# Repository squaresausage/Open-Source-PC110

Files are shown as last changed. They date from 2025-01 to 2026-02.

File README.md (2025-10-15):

# IBM Palm Top PC110

Screenshot 2025-04-17 at 7 04 40 PM

A repository for all the technical details of the PC110

What it includes:

Schematic and PCB layout of the motherboard (based on KiCad)

Schematic and PCB layout of the PSU module (based on KiCad)

Schematic and PCB layout of the Docking Station (based on KiCad)

Schematic and PCB layout of the Modem (based on KiCad)

Schematic and PCB layout of the 16MB RAM Module (based on KiCad)

Flex PCB and PET Schematic and layout of the Keyboard Membrane (based on KiCad)

Optical scans, X-ray images from different PCBs, layers, and chips.

Flash dump of the BIOS and the AT29LV512 (available in only a few models).

Flash dump of M38224M6HP and M38813E4HP.

# How can you help?

Help by reviewing Schematics and PCB layouts to report potential bugs, errors, and issues.

Help to verify the layout and schematic.

Help with finding missing datasheets

Please help us [fund](https://gofund.me/716b7dae) the next iteration of PCBA to test the recreated motherboard.

# Press

Featured on Hack-A-Day: 
- [Reverse Engineering The IBM PC110, One PCB At A Time](https://hackaday.com/2025/04/06/reverse-engineering-the-ibm-pc110-one-pcb-at-a-time/) 

Featured on Taka's blog:
- [PC110 New PSU](https://garakutaen.sakura.ne.jp/misc2/MlogmP3.html#e0318)
- [PC110 PCB Pattern](https://garakutaen.sakura.ne.jp/misc2/MlogmP1.html#e0130)
- [PC110 PCB Layout creation](https://garakutaen.sakura.ne.jp/misc2/MlogmP2.html#e0208)
- [PC110 New Docking Station PCB](https://garakutaen.sakura.ne.jp/misc2/MlogmP3.html#e0324)
- [X-ray photos of the inside of the PC110's LSI](https://garakutaen.sakura.ne.jp/misc2/MlogmP2.html#e0225)

Jeff Geerling's YouTube Channel:
- [Reverse engineering Episode](https://youtu.be/p7IvioiveOo?si=PUlHSzOhwXYEpZJ3&t=217)

LGR YouTube Channel:
- [LGR Vlog: VCFMW20](https://www.youtube.com/watch?v=yIwXQicYClw&t=7595s)

VCFMW20 YouTube Channel:
- [Archaeology of the IBM PC110](https://www.youtube.com/watch?v=8Uja7g9hQlo)

# License

This project is licensed under the Creative Commons Attribution-NonCommercial 4.0 International License (CC BY-NC 4.0).

You are free to:
- Share — copy and redistribute the material in any medium or format
- Adapt — remix, transform, and build upon the material

Under the following terms:
- Attribution — You must give appropriate credit, provide a link to the license, and indicate if changes were made.
- NonCommercial — You may not use the material for commercial purposes.

For full details, see: https://creativecommons.org/licenses/by-nc/4.0/

As the project creator, I reserve the right to use this material commercially or under any other terms.

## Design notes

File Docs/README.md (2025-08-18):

# A Tribute to the IBM PC110

## A Deep Dive into Silicon, Sandpaper, and Secrets of the IBM PC110

**Reverse engineering the beloved IBM PC110, a 486SX-based subnotebook from the 90s, released exclusively in Japan with custom repackaged BGA chips, custom ASICs, and an attractive form factor.**

---

## Introduction: A Palm-Sized Powerhouse

The **IBM PC110**, released exclusively in **Japan in 1995**, was one of the smallest fully functional x86 systems ever made by IBM. This palmtop computer crammed a 486SX CPU, a CHIPS 65535 VGA chip, two PCMCIA slots, a CF card, and more great features into something that fits on top of your palm.

Despite rumors of an **English-language or U.S. release**, no such version ever reached the market. The project was reportedly in development but was quietly shelved, making the IBM PC110 unique and **regionally rare and historically mysterious**.

What fascinated me wasn’t just the size—it was the story under the keyboard: repackaged BGA packages and chips with no public documentation, the usage of camcorder batteries instead of a proprietary battery, and a CF card slot which made the machine sort of future proof and relevant to be "practical", even today. 

Unfortunately, most of the IBM PC110s ended up breaking down over time due to the leak of the bridge battery, causing corrosion and destroying the circuit board. It was heartbreaking to see those laptops end up in the landfill helplessly.  

So I decided to **reverse engineer the entire machine**. That journey involved **sandpaper**, **ROM dumps**, **laser decapping**, **high-resolution die photos**, and the help of some brilliant hardware and software hackers. What I found includes rare chipsets, custom logic arrays, and design decisions that were both *visionary* and *tragically destructive*.

---

## A Design Ahead of Its Time and One Fatal Flaw

The PC110 had forward-thinking design features, including:

- A **standard camcorder battery** (still sold on Amazon today)
- A **CompactFlash card slot**, used as its primary storage drive

These were remarkable decisions in 1995, long before CF replaced spinning disks in industrial systems.

But the system had a fatal flaw:  
A small **NiMH-based bridge battery**, placed internally, which was designed to maintain power between main battery swaps.
This was mainly because the internal PSU was unable to charge the battery while the machine was operating (things we take for granted with today's laptops). Therefore, the bridge battery was placed there to keep the machine running for about 2 minutes while you perform a battery swap.

Over time, that battery becomes a **ticking time bomb**.  
As it fails, it **leaks potassium hydroxide (KOH)**, a highly corrosive chemical that **destroys PCB traces**, **eats through components**, and **wrecks solder joints**.  
It’s the leading cause of death for otherwise restorable PC110 units today.

---

## Sanding a 10-Layer PCB — With a Flatbed Scanner

To begin understanding the system, I took the hard and destructive, yet necessary route:  
I **sanded the motherboard** down layer by layer.

The board is just **1.0mm thick**, with **10 copper layers**, each ~**70 microns**. I used **ultra-fine grit sandpaper** to remove layers delicately, scanning the exposed surface after each pass with a **high-resolution flatbed scanner**.

It was slow, imperfect, and occasionally damaging—but it worked. By the end, I had a full stack of perfectly aligned copper layers. Because I made several mistakes during the sanding and went too far, especially as I progressed through the layers, I had to sacrifice a second PCB, this time by sanding it from the other side.

---

## Reconstructing the Board in KiCad

With the scanned layers imported into **KiCad**, I aligned them and manually traced:

- Every net  
- Every via (through and blind)  
- Every component pad  
- Every trace/track  
- Every power polygon  
- Many more details  

Bit by bit, the **entire circuit** came together. I gave up many times in the middle due to some complexity or unresolved issues, but each time, I returned and continued. Some traces were incomplete or degraded, but logic and redundancy allowed me to **reconstruct the full schematic** of the system. Some tracks even appeared to go nowhere—perhaps used for debugging or cut later by the manufacturer. Who knows what software IBM used in the mid-90s; certainly not KiCad.

---

## Schematic Extraction and Deep System Insight

After the layout was reconstructed and the parts were identified, I began to **extract the schematic**, piece by piece.  
I organized different **subsystems** into separate schematic sheets, including:

- Clock Tree  
- CPU and debug port  
- Chipset and RTC  
- VGA controller  
- RAM interface  
- ROM and BIOS  
- ASICs  
- Super IO (FDD, Serial, LPT)  
- Power and charging logic  
- PCMCIA controller  
- Audio and FM Synthesizer  
- Storage and CF slot  
- Keyboard/PS2  
- IRDA and Docking station connector  

This gave me exceptional insight into **how IBM and RIOS Systems engineered this device**. After extracting the full schematic, I linked it back to the layout to identify and resolve discrepancies.  

The result is a schematic that **perfectly reflects the physical PCB** — signal-for-signal.

---

## Why This Schematic Unlocks the Future

With a fully accurate schematic and layout, this project now enables:

- **Redesigning the motherboard** with modern components  
- **Changing the form factor** entirely (e.g., vertical/landscape designs)  
- **Creating a Raspberry Pi-based recreation**  
- **Hardware diagnostics and repair**  
- **Upgrades and mods**, including custom RAM cards, new docks, and embedded devices

---

## The Known and Unknown Silicon

Identified components:

- **Intel 80486SX** CPU  
- **CHIPS65535** VGA controller  
- **Ricoh RB5C396** PCMCIA bridge  
- **FDC37C665IR** for FDD, Serial, LPT  
- **SC414281PU4** Storage Controller  
- Various logic ICs

Mysterious components:

- **VL82C420** – part of the SCAMP IV chipset, no datasheet available  
- **ES488** – no datasheet found; To recover the pinout, we purchased an old ISA sound card based on the ES488 and carefully traced all the connections from the ISA bus to the chip. This revealed almost the entire pinout and, in turn, helped us determine the ISA bus pinout of the PC110 motherboard.
- **IBM “Pluto” and “Bowman” ASICs**

The VL82C420 integrates 6 known chips (VL82C59s, VL82C37s, VL82C54, VL82C018) and a custom gate array.

---

## Decapping Chips with CLC and John McMaster

With Fred Nielsen from **CLC**, we decapped the VL82C420, Pluto, and Bowman using a laser-driven photo-chemical process.  
**John McMaster** provided high-resolution die imaging.

### Inside the VL82C420

- 2× VL82C59 (Interrupt Controller)  
- 2× VL82C37 (DMA Controller)  
- 1× VL82C54 (Timer)  
- 1× VL82C018 (RTC)  
- Integrated gate array  
- BGA packaging custom-made by RIOS

### Pluto and Bowman

IBM-designed gate arrays responsible for:

- Power sequencing  
- Interrupt control  
- ISA and docking logic  
- System glue logic

---

## PSU, Modem, and Docking Station Reverse Engineering

Reverse-engineering the PSU, modem, and docking station enabled:

- Full **pinout mapping**  
- Verification of unknown connector functions  
- Potential for **custom modern docks**

---

## Embedded Microcontrollers and ROM Extraction

| Chip | Function |
|---|---|
| **M38223** | Power sequencing |
| **M3881** | Keyboard & PS/2 |
| **D17137AGT**  | TrackPoint controller |

ROMs for M38223 and M3881 were extracted (thanks to **Kevin Moonlight**).  
**D17137AGT** was imaged optically but not visually decoded.

---

## Everything is Open-Source

GitHub Repo: [https://github.com/ahmadexp/Open-Source-PC110](https://github.com/ahmadexp/Open-Source-PC110)

### Contents

- `/scans/` — 10-layer PCB scans  
- `/kicad/` — Full KiCad schematic/layout  
- `/rom_dumps/` — ROM binaries  
- `/die_images/` — Die photographs  
- `/pinouts/` — Pin mappings  
- `/notes/` — Research notes

---

## What You Can Do

- Rebuild or modify the hardware  
- Use for emulation or form factor experiments  
- Study VL82C420 and ES488  
- Build docks, RAM, and CF replacements  
- Contribute firmware or ROM analysis

---

## Thanks and Acknowledgements

This project would not have been possible without:

- **Kevin Moonlight** — for microcontroller ROM extraction  
- **Mike Lycett** — for organizing the fundraiser, coordinating the effort, and promoting the project  
- **Nick Rogers** — for debugging and verification  
- **John McMaster** — for high-resolution die imaging and technical consultation  
- **CLC** — for decapping services and silicon prep  
- The **open hardware & retrocomputing community** — for encouragement, contributions, and documentation support

---

## Featured on Hackaday

Read the article: [https://hackaday.com/2025/04/06/reverse-engineering-the-ibm-pc110-one-pcb-at-a-time/](https://hackaday.com/2025/04/06/reverse-engineering-the-ibm-pc110-one-pcb-at-a-time/)

> “The kind of project that goes beyond repair — it preserves design history, reveals hidden hardware, and makes future restoration possible.”

---

## Stay Updated

- GitHub: [ahmadexp/Open-Source-PC110](https://github.com/ahmadexp/Open-Source-PC110)  
- Contact: Ahmad Byagowi / [@ahmadexp](https://github.com/ahmadexp)  
- YouTube video coming soon!

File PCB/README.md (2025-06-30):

## PC110 Recreated PCBs

Here you can find the recreated [Schematics](https://github.com/ahmadexp/Open-Source-PC110/blob/main/PCB/PC110-Schematics-Combined.pdf) and PCB layouts for different parts of the PC110 based on KiCad 9.0 (with the [AKL](https://alternatekicadlibrary.com/) as a requirement).
Here is a description of each folder:

| Index | Folder | Description | Number of Layers |
| ----- | --- | --- | --- |
| 1 | Mainboard | Mother Board | 10 |
| 2 | PSU | Power Supply | 4 |
| 3 | Keyboard | Keyboard Membrane  | 2 + 2 |
| 4 | DockingStation | Port Expansion | 4 |
| 5 | Modem | 14.4 Interal Modem | 6 |
| 6 | RAM-16MB | 16MB RAM Module | 4 |

Here are some 3D renders of the PCBs

### Mother Board:

- Schematic

Screenshot 2025-06-19 at 7 54 10 AM

- Layout

motherboard

### Power Supply:

- Schematic
Screenshot 2025-06-19 at 7 47 46 AM

- Layout
Screenshot 2025-04-04 at 7 01 09 PM

### Keyboard Membrane:

- Schematic
Screenshot 2025-06-19 at 7 48 27 AM

- Layout
Screenshot 2025-03-26 at 6 59 02 PM

### Port Expansion (Docking Station):

- Schematic
Screenshot 2025-06-19 at 7 48 05 AM

- Layout
dock

### 14.4 Kbps Internal Modem:

- Schematic
Screenshot 2025-06-19 at 7 48 13 AM

- Layout
modem

### 16MB RAM Module:

- Schematic
Screenshot 2025-06-19 at 7 48 20 AM

- Layout
Screenshot 2025-03-26 at 7 45 36 PM

Screenshot 2025-03-26 at 7 45 54 PM

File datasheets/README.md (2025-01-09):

## collection of datasheets related to the chips on the board

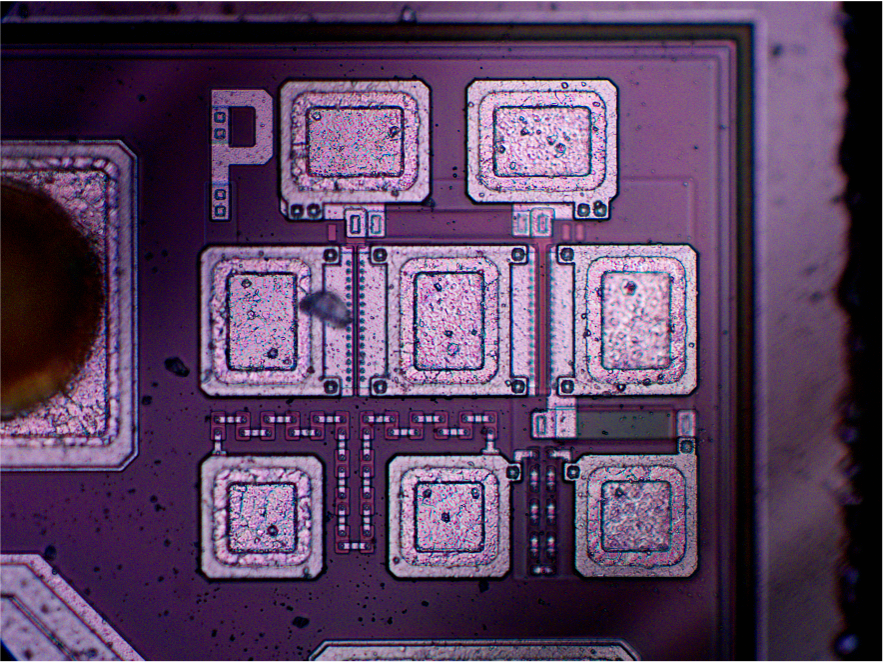
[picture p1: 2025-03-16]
optical/Pluto/Picture9.png

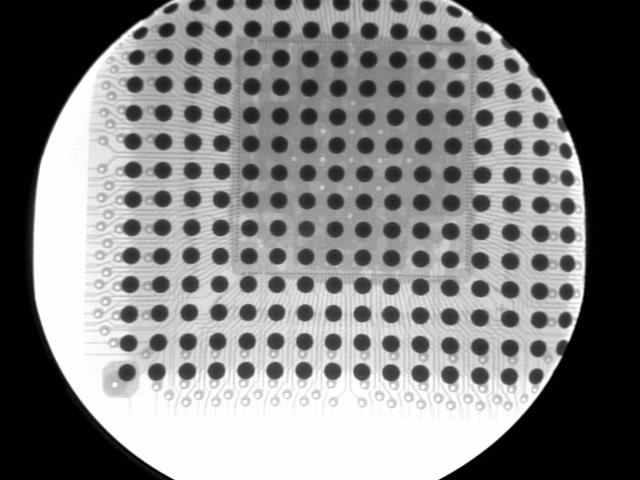
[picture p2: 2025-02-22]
optical/Chip Diagnostic/VL82C420 BL.JPG

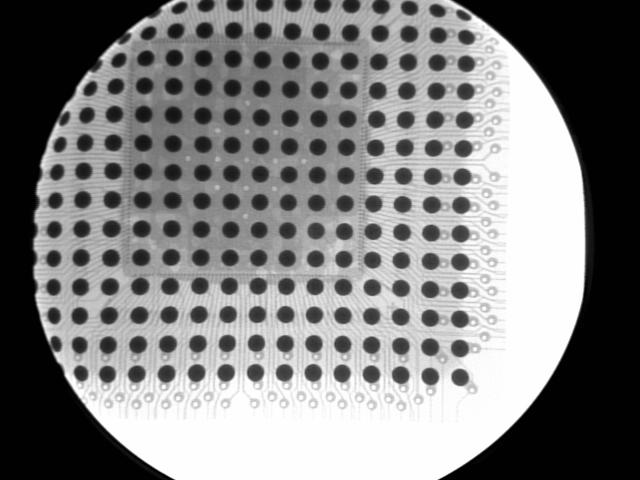
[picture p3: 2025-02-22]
optical/Chip Diagnostic/VL82C420 BR.JPG

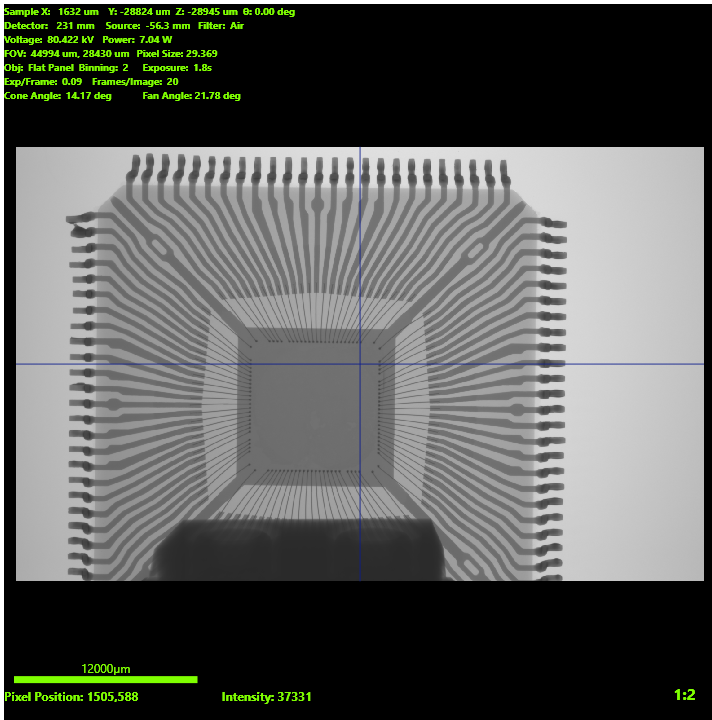
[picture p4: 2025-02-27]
optical/x-ray/pluto.png

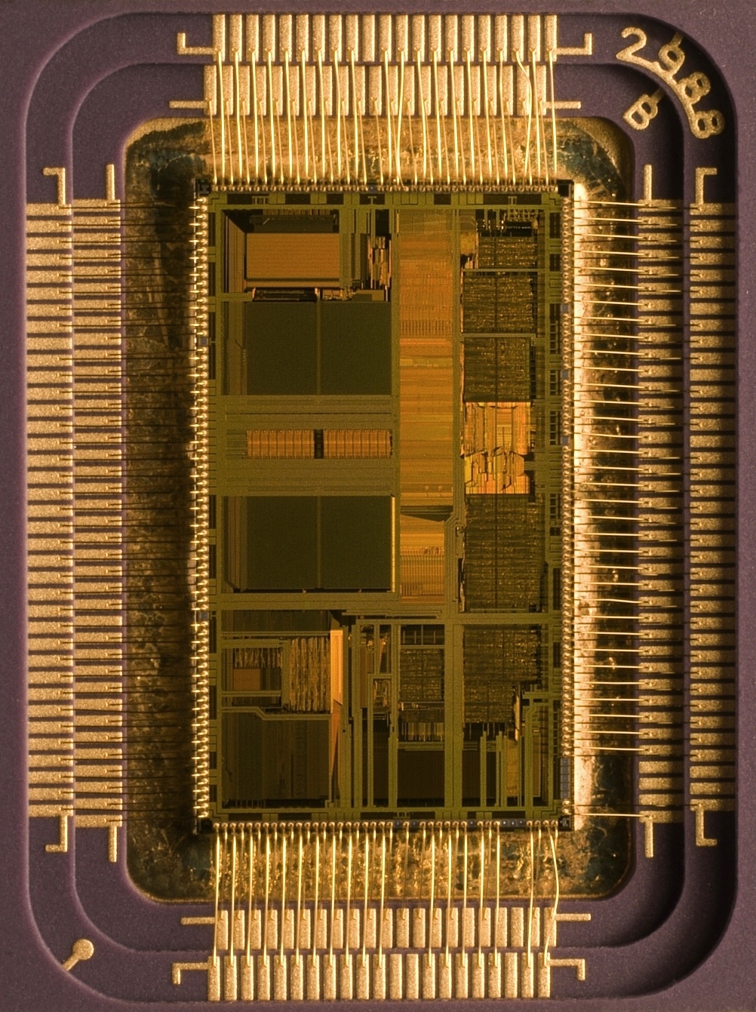
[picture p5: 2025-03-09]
optical/Chip Diagnostic/80486dx2-large.jpg

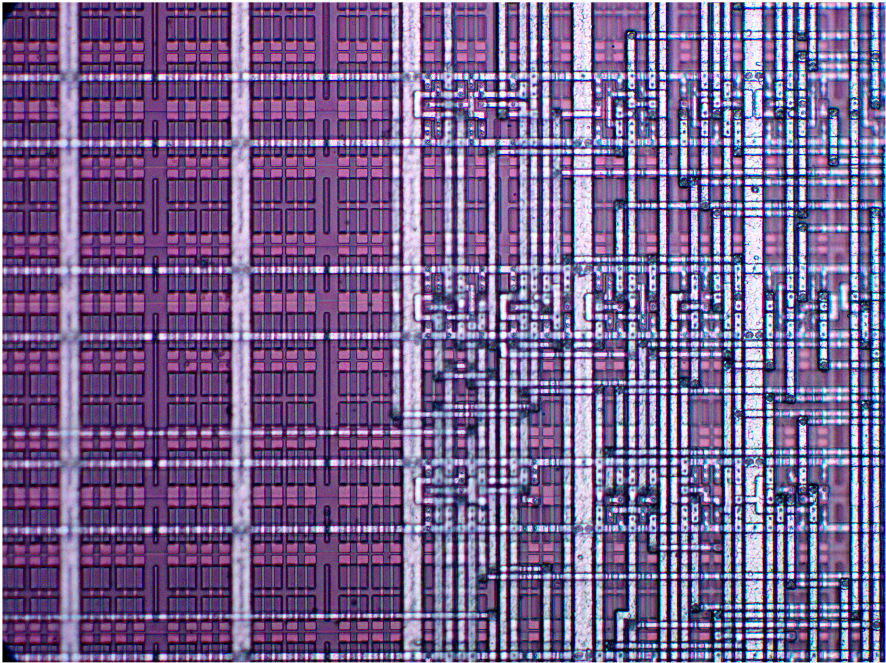
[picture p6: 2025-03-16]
optical/Pluto/Picture11.png

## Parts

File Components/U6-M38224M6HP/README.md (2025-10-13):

## Datasheets ##
[M38224M6HP](M3822.pdf)

[PCA4738H0-80A](PCA4738H.pdf)

## Part Number Details ##
```
M38223E4HP
|||||||||
|||||||++--> 80P6Q-A
||||||+----> 16384 Byte ROM Size 
|||||+-----> EPROM / OTP Version
||||+------> 512 Bytes RAM
++++-------> Mitsubishi 3822 Group MCU
```
There are at least two variations of the PC110.    In a small number of systems U6 is M38223E4HP OTP/EPROM version of the chip,  in the rest it is the M38223M4-192HP MASKROM version.  It is unclear if these represent early production models or perhaps supply chain related.    This is a helpful detail as it is unclear if a MASKROM variant can have its program read out without an optical approach.

Some boards also have non-programmed Sandisk controllers in U41 and contain a flash chip U27 for the program/config, where as the rest omit the external flashrom and have a maskrom U41.

I have observed boards where U6 is EPROM but U41 is MASKROM.  I have not yet seen one where U6 is MASKROM and U41 is not.  

## Location ##







## ROM Extraction ##

[M38223E4HP@QFP80.BIN](/Flash/M38223E4HP/M38223E4HP@QFP80.BIN) - **M3822X POWER SENSE MICON FIRMWARE Rev 8 (C) 1995 RIOS SYSTEMS CO.,LTD**

So far it seems to not be possible to  read the program from the MASKROM version of the chip,  which likely is to be expected.

There was some indictation that M38xx could be  programmed using a Segger Flasher 5 or earlier,  but I was unsuccessful with this approach so far.

For the PROM method, the documentation specifies to utilize a standard programmer with the following special adapter:

PCA4738H-80A - PROM Programming Adapter for 80-pin 0.5mm-pitch LQFP of 38000 Series with PROM

I was unable to find detailed documentation on this adapter,  but the manual does specify some useful information.

The document titled [**PROM Programming Adapters for 38000 Series**](PCA4738H.pdf) on **Page 16 under 2.6 Setting the Programming Area** specifies to configure your programmer for a M5M27C256A and that the ROM area will be 0x4080 to 0x7FFD.

In reviewing related chips of the M38 family I was able to determine the following were the required connections for accessing the PROM.   Note VCC not not be powered, and instead P40 receives VCC to power only the internal PROM.  There is a note about this PIN and its special use case for powering the internal PROM.   PIN60 must be grounded.   









## Program Recovery & Analysis

Datasheet states the M3822 group is based on the 740 family core,  which is based on the 65C02.

[Mitsubishi 704 Family MCU](https://en.wikipedia.org/wiki/Mitsubishi_740)

The vector table at the end of the PROM is as expected and dissassembly is the next step. Work is currently ongoing and many functions are already documented. The M3822 seems to be doing a lot of different things however, so there is still much to be done.

Note that currently a custom version of Ghidra is needed to add support for the Mitsubishi 740 and its extended variants like the M3822. This currently exists [here](https://github.com/squaresausage/ghidra/tree/philpem-add-melps740).

The ROM is appears at 0xC080 -> 0xFFFD  in the 65C02 memory space, with FFFC/FFFD being the reset vector.



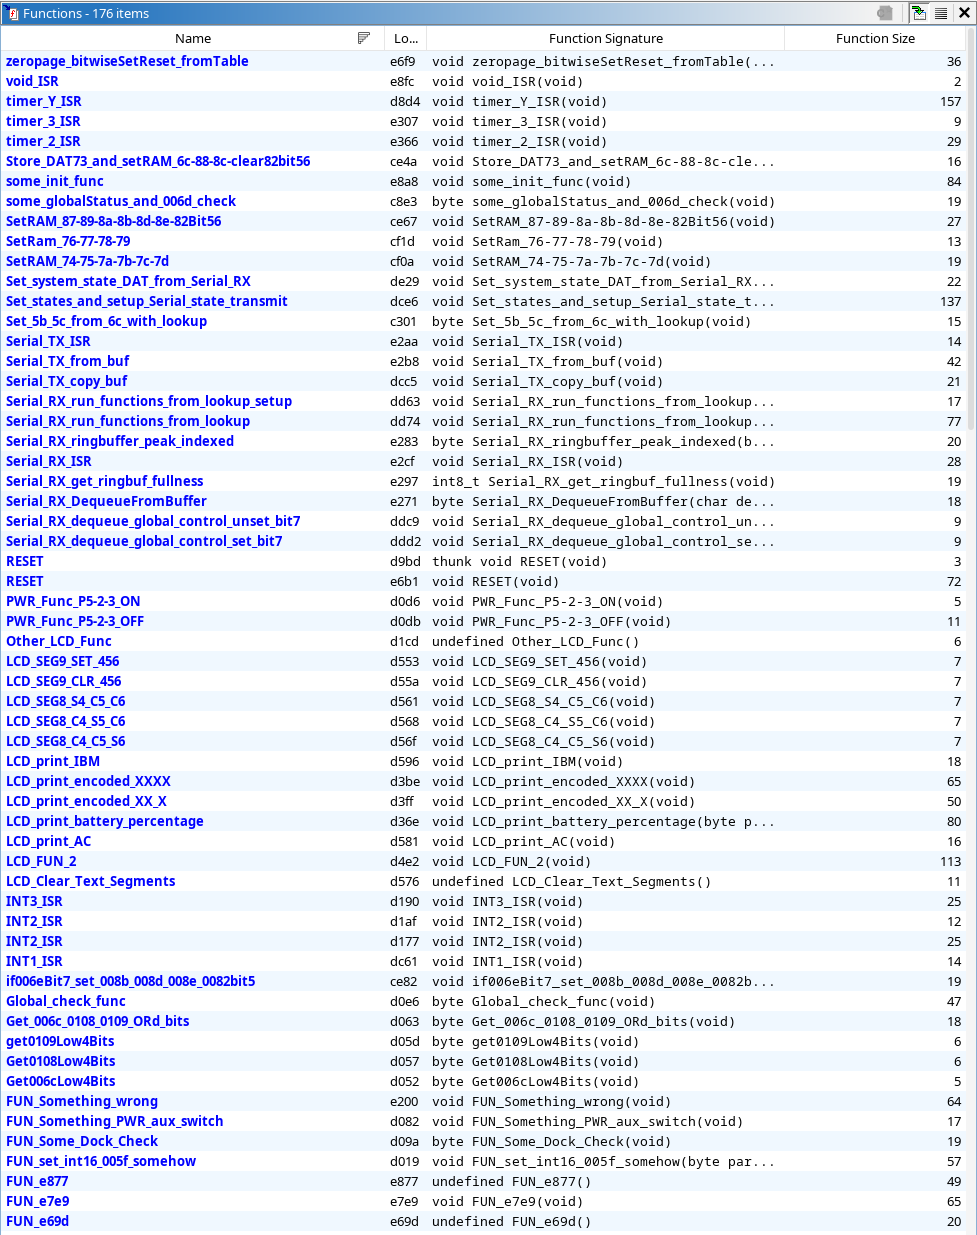
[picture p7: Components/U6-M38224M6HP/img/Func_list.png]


## Other Notes ##

* The UART pins (19,20)  are connected to U69 /  M3813E4HP   Pins 10/11.  The communicate at 1200 baud, there is a heartbeat and some other communication to be investigated.

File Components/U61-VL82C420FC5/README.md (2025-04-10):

## VL82C420FC5

Screenshot 2025-04-10 at 7 49 05 AM

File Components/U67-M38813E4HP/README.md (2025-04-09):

## Datasheets ##

As found with the  power management MCU,  some PC110's  have a MASKROM version populated,  and some have PROM version which can be read back.

The actual datasheet for the M3881   does not appear to be available,  however reviewing datasheets of similiar chips is helpful.

[PCA4738H0-80A](/Components/U6-M38224M6HP/PCA4738H.pdf)

[M38813M4 Example](M38813M4.png)

[M38002M4.PDF](M38002M4.PDF)

## Part Number Details ##
```
M38813E4HP
||||||||||
||||||||++--> 64P6Q-A
|||||||+----> 16384 Byte ROM Size 
||||||+-----> EPROM / OTP Version
|||||+------> 512 Bytes RAM
+++++-------> Mitsubishi 3881 Group MCU
```

## Location ##





## ROM Extraction ##

[M3881E4HP@QFP64.BIN](/Flash/M38813E4HP/M38813E4HP@QFP64.bin) - **MELPS 740 Series Keyboard Firmware Version 1.1(C) Copyright 1992-1995 RIOS Systems Co.,Ltd**

Extraction of the firmware from the M38813E4 was the same concept as the M38223E4,  however without a datasheet and limited information it took some trial and error to determine how to power the internal PROM.

As shown below, those are the connections made when using at as an M5M27C256K chip.    Datasheets for similiar  chips showed attaching A15 to VCC, however doing this caused unexpected behaviour.   Pulling A15 high with a 10K resistor resulted in reliable results.  The connections are still not quite as expected in relation to CE/OE.    Once connected the PROM is located at 0x4080 to 0x7FFD.

For a little bit more detail refer to [U6-M38224M6HP](/Components/U6-M38224M6HP/).





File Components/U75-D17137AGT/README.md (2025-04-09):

## D17137AGT

Screenshot 2025-04-09 at 12 22 31 AM

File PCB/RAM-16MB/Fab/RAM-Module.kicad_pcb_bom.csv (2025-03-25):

Designator | Quantity | Value | Footprint | Package | MPN | DNP | Mount_Type
C1, C10, C2, C3, C4, C5, C6, C7, C8, C9 | 10 | 100nF | C_0805_2012Metric |  |  |  | smt
J15 | 1 | RAM Module | RAM Module |  |  |  | smt
R1, R2 | 2 | 0 | R_0805_2012Metric |  |  |  | smt
U1, U2, U3, U4, U5, U6, U7, U8 | 8 | 51W17800TT6 | SOJ-28_10.16x18.415mm_P1.27mm |  |  |  | smt

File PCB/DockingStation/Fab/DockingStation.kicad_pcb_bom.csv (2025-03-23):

Designator | Quantity | Value | Footprint | Package | MPN | DNP | Mount_Type
, | 2 |  |  |  |  |  | tht
C1 | 1 | 330nF | C_0805_2012Metric |  |  |  | smt
C10 | 1 | 1nF | C_0603_1608Metric |  |  |  | smt
C11 | 1 | 2.5uF | C_1206_3216Metric |  |  |  | smt
C12, C15, C17, C19, C21, C23, C25, C27, C29, C31, C32, C34, C35, C36, C9 | 15 | 280nF | C_0603_1608Metric |  |  |  | smt
C13, C14, C16, C18, C20, C22, C24, C26, C28, C30 | 10 | 82pF | C_0603_1608Metric |  |  |  | smt
C2 | 1 | 1nF | C_0805_2012Metric |  |  |  | smt
C3, C4 | 2 | 200pF | C_0805_2012Metric |  |  |  | smt
C33 | 1 | 330nF | C_0603_1608Metric |  |  |  | smt
C37, C38, C39, C40, C41, C42, C43, C44, C63, C64, C65, C66 | 12 | 200pF | C_0603_1608Metric |  |  |  | smt
C45, C46, C47, C48, C49, C50, C51, C52, C53, C54, C55, C56, C57, C58, C59, C60, C61 | 17 | 200nF | C_0603_1608Metric |  |  |  | smt
C62, C67, C78 | 3 | 250nF | C_0603_1608Metric |  |  |  | smt
C68 | 1 | DNP | C_0603_1608Metric |  |  | Yes | smt
C69 | 1 | DNP | C_1206_3216Metric |  |  | Yes | smt
C70 | 1 | DNP | C_0805_2012Metric |  |  | Yes | smt
C71 | 1 | DNP | C_1206_3216Metric |  |  | Yes | smt
C72 | 1 | DNP | C_0805_2012Metric |  |  | Yes | smt
C73 | 1 | DNP | C_0603_1608Metric |  |  | Yes | smt
C74 | 1 | DNP | C_0603_1608Metric |  |  | Yes | smt
C75 | 1 | 150nF | C_0603_1608Metric |  |  |  | smt
C76, C77 | 2 | 10nF | C_0603_1608Metric |  |  |  | smt
C79, C80, C81, C82 | 4 | 360nF | C_0805_2012Metric |  |  |  | smt
C83 | 1 | DNP | C_0603_1608Metric |  |  | Yes | smt
CN1 | 1 | DSUB-15-HD_Socket_Horizontal_P2.29x1.90mm_EdgePinOffset3.03mm_Housed_MountingHolesOffset4.94mm | DSUB-15-HD_Socket_Horizontal_P2.29x1.90mm_EdgePinOffset3.03mm_Housed_MountingHolesOffset4.94mm |  |  |  | tht
CN2 | 1 | FDC_Connector | FDC_Connector |  |  |  | smt
CN4 | 1 | DSUB-25_Socket_Horizontal_P2.77x2.84mm_EdgePinOffset4.94mm_Housed_MountingHolesOffset4.94mm | DSUB-25_Socket_Horizontal_P2.77x2.84mm_EdgePinOffset4.94mm_Housed_MountingHolesOffset4.94mm |  |  |  | tht
CN5 | 1 | DSUB-9_Pins_Horizontal_P2.77x2.84mm_EdgePinOffset4.94mm_Housed_MountingHolesOffset4.94mm | DSUB-9_Pins_Horizontal_P2.77x2.84mm_EdgePinOffset4.94mm_Housed_MountingHolesOffset4.94mm |  |  |  | tht
CN6, CN7 | 2 | PS2 Connector | PS2 Connector |  |  |  | smt
CN8 | 1 | BarrelJack_Horizontal_PC110 | BarrelJack_Horizontal_PC110 |  |  |  | tht
D2, D3 | 2 | s.3 5J | D_2010_5025Metric |  |  |  | smt
DA1, DA10, DA2, DA3, DA4, DA6, DA7, DA8 | 8 | 1W | SOT-323_SC-70 |  |  |  | smt
DA11 | 1 | DNP | SOT-23W |  |  | Yes | smt
DA12 | 1 | DNP | SOT-23W |  |  | Yes | smt
DA9 | 1 | SOT-323_SC-70 | SOT-323_SC-70 |  |  | Yes | smt
F1 | 1 | 50v x1G0 JX30 | Fuse_Littelfuse_395Series |  |  |  | tht
J1, J2, J3, J4 | 4 | 25-1MP_P0.5mm_Horizontal | 25-1MP_P0.5mm_Horizontal_PC110_dock |  |  |  | smt
L1, L2, L3, L34, L37, L38 | 6 | 300nH | L_0805_2012Metric |  |  |  | smt
L11, L13, L14, L15, L16, L17, L18, L19, L20, L21, L22, L23, L24, L25, L26, L27, L28, L29, L30, L31, L39, L40, L41, L42, L43, L44, L45, L46, L47, L48, L49, L5, L50, L51, L52, L53, L54, L55, L56, L57, L58, L59, L6, L60, L61, L62, L63, L64, L65, L66, L67 | 51 | 680nH | L_0805_2012Metric |  |  |  | smt
L68 | 1 | EMI_Transformer | EMI_Transformer |  |  |  | smt
Q1 | 1 | 3P4J | TO-252-2 |  |  |  | smt
Q2 | 1 | 8C | SOT-323_SC-70 |  |  |  | smt
R1, R2 | 2 | 33 | R_0805_2012Metric |  |  |  | smt
R10 | 1 | DNP | R_0603_1608Metric |  |  | Yes | smt
R11 | 1 | DNP | R_0603_1608Metric |  |  | Yes | smt
R12, R13, R14, R15, R16, R17, R18, R19, R20, R21, R22, R23, R24, R25, R26, R27, R28 | 17 | 10 | R_0603_1608Metric |  |  |  | smt
R29 | 1 | DNP | R_0603_1608Metric |  |  | Yes | smt
R3, R4 | 2 | 33 | R_0603_1608Metric |  |  |  | smt
R30, R31, R32, R33, R34, R35, R36, R37 | 8 | 1k | R_0805_2012Metric |  |  |  | smt
R38 | 1 | 0 | R_0805_2012Metric |  |  |  | smt
R39, R41, R5, R52, R53, R54, R55, R56, R57, R58, R59, R68, R69, R7, R70, R71, R72, R73, R74, R75, R8 | 21 | 0 | R_0603_1608Metric |  |  |  | smt
R40 | 1 | DNP | R_0603_1608Metric |  |  | Yes | smt
R42 | 1 | DNP | R_0603_1608Metric |  |  | Yes | smt
R43 | 1 | DNP | R_0603_1608Metric |  |  | Yes | smt
R44 | 1 | DNP | R_0603_1608Metric |  |  | Yes | smt
R45 | 1 | DNP | R_0603_1608Metric |  |  | Yes | smt
R46 | 1 | DNP | R_0603_1608Metric |  |  | Yes | smt
R47 | 1 | DNP | R_0603_1608Metric |  |  | Yes | smt
R48 | 1 | DNP | R_0603_1608Metric |  |  | Yes | smt
R49 | 1 | DNP | R_0603_1608Metric |  |  | Yes | smt
R50 | 1 | DNP | R_0603_1608Metric |  |  | Yes | smt
R51 | 1 | DNP | R_0603_1608Metric |  |  | Yes | smt
R6, R9 | 2 | 470k | R_0603_1608Metric |  |  |  | smt
R60 | 1 | DNP | R_0603_1608Metric |  |  | Yes | smt
R61 | 1 | DNP | R_0603_1608Metric |  |  | Yes | smt
R62 | 1 | DNP | R_0603_1608Metric |  |  | Yes | smt
R63 | 1 | DNP | R_0603_1608Metric |  |  | Yes | smt
R64 | 1 | DNP | R_0603_1608Metric |  |  | Yes | smt
R65 | 1 | DNP | R_0603_1608Metric |  |  | Yes | smt
R66 | 1 | DNP | R_0603_1608Metric |  |  | Yes | smt
R67 | 1 | DNP | R_0603_1608Metric |  |  | Yes | smt
RA2, RA3, RA4 | 3 | 47k | R_Array_Concave_4x0603 |  |  |  | smt
RA5, RA6 | 2 | 470k | R_Array_Concave_4x0603 |  |  |  | smt
RA7 | 1 | DNP | R_Array_Concave_4x0603 |  |  | Yes | smt
RA8 | 1 | DNP | R_Array_Concave_4x0603 |  |  | Yes | smt
SSFC | 1 | Fuse_2010_5025Metric | Fuse_2010_5025Metric |  |  |  | smt
U1 | 1 | 74VHCT244 | SSOP-20_4.4x6.5mm_P0.65mm |  |  |  | smt
U2 | 1 | DNP (LT1237CS) | SSOP-28_5.3x10.2mm_P0.65mm |  |  | Yes | smt
U3 | 1 | DS14C535MSA | SSOP-28_5.3x10.2mm_P0.65mm |  |  |  | smt
U4 | 1 | DNP | SOT-23-5 |  |  | Yes | smt
ZD1 | 1 | 18- | D_0805_2012Metric |  |  |  | smt
ZD4 | 1 | 5_1 | D_0805_2012Metric |  |  |  | smt

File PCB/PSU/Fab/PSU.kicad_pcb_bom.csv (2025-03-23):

Designator | Quantity | Value | Footprint | Package | MPN | DNP | Mount_Type
C1, C16, C24, C28, C36, C46, C47, C5, C59, C7 | 10 | 150nF | C_0603_1608Metric |  |  |  | smt
C10 | 1 | 3.6nF | C_0603_1608Metric |  |  |  | smt
C11, C15, C37, C44, C49 | 5 | 180nF | C_0603_1608Metric |  |  |  | smt
C12 | 1 | 1.2uF | C_1206_3216Metric |  |  |  | smt
C13, C14 | 2 | 1.5uF | C_1206_3216Metric |  |  |  | smt
C17, C22, C26, C29, C30, C32, C39, C40, C48, C9 | 10 | 10nF | C_0603_1608Metric |  |  |  | smt
C18, C42, C51, C53, C64 | 5 | 120nF | C_0603_1608Metric |  |  |  | smt
C19 | 1 | 18nF | C_0603_1608Metric |  |  |  | smt
C2 | 1 | 4.7nF | C_0603_1608Metric |  |  |  | smt
C20, C6 | 2 | 100pF | C_0603_1608Metric |  |  |  | smt
C21 | 1 | 12nF | C_0603_1608Metric |  |  |  | smt
C23, C34, C38, C41, C55, C58 | 6 | 1.5uF | C_0805_2012Metric |  |  |  | smt
C25, C27, C31, C35, C66 | 5 | 1.2nF | C_0603_1608Metric |  |  |  | smt
C3 | 1 | 5.2uF | C_1206_3216Metric |  |  |  | smt
C33, C8 | 2 | 24nF | C_0603_1608Metric |  |  |  | smt
C4 | 1 | 2.5nF | C_0603_1608Metric |  |  |  | smt
C43 | 1 | 10pF | C_0603_1608Metric |  |  |  | smt
C45 | 1 | 33uF 20V | C_Disc_D3.0mm_W1.6mm_P2.50mm |  |  |  | tht
C50 | 1 | 56uF 25V EC | EC |  |  |  | tht
C52, C60 | 2 | 1nF | C_0603_1608Metric |  |  |  | smt
C54, C61 | 2 | 47uF 6.3v | C_Radial_D6.3mm_H11.0mm_P2.50mm |  |  |  | tht
C56 | 1 | 47uF 6.3V | C_Radial_D6.3mm_H11.0mm_P2.50mm |  |  |  | tht
C57 | 1 | 15uF 16V | C_Radial_D6.3mm_H11.0mm_P2.50mm |  |  |  | tht
C62, C65 | 2 | 100nF | C_0603_1608Metric |  |  |  | smt
C63 | 1 | 5.1nF | C_0603_1608Metric |  |  |  | smt
C67 | 1 | 18uF 50V | C_Radial_D6.3mm_H11.0mm_P2.50mm |  |  |  | tht
D1 | 1 | 8-2 | D_0603_1608Metric |  |  |  | smt
D2 | 1 | 5-9 | D_0603_1608Metric |  |  |  | smt
D3 | 1 | DNP | D_1206_3216Metric |  |  | Yes | smt
D4 | 1 | 18 | D_0603_1608Metric |  |  |  | smt
D5 | 1 | 3^9 | D_0603_1608Metric |  |  |  | smt
D6 | 1 | DNP | D_1206_3216Metric |  |  | Yes | smt
D7, D8 | 2 | s.3 4F | D_1206_3216Metric |  |  |  | smt
F1, F5 | 2 | 2.5A | Fuse_2010_5025Metric |  |  |  | smt
F2 | 1 | 830mA | Fuse_2010_5025Metric |  |  |  | smt
F3 | 1 | 15 | Fuse_1206_3216Metric |  |  |  | smt
F4 | 1 | 10 | Fuse_1210_3225Metric |  |  |  | smt
J1 | 1 | Backllight_Connector | Backllight_Connector |  |  |  | smt
J2 | 1 | PSU_Jack | PSU_Jack |  |  |  | smt
J3 | 1 | PSU_Connector_Receptor | PSU_Connector_Receptor |  |  |  | smt
L1 | 1 | 10uH | L_Radial_D7.5mm_P5.00mm_Fastron_07P |  |  |  | tht
L2, L5 | 2 | 10uH | L_Radial_D10.0mm_P5.00mm_Fastron_07M |  |  |  | tht
L3 | 1 | 68uH | L_Coilcraft_LPS5030 |  |  |  | smt
L4 | 1 | 470uH | L_Coilcraft_LPS5030 |  |  |  | smt
Q1 | 1 | R4C | 3D |  |  |  | smt
Q10 | 1 | 103 5G | SOT-powerT |  |  |  | smt
Q11, Q14, Q24, Q3, Q34, Q6, Q7 | 7 | 6LS | SOT-416 |  |  |  | smt
Q12, Q18 | 2 | Q | 3D |  |  |  | smt
Q13, Q15, Q33, Q37, Q4 | 5 | 8LR | SOT-416 |  |  |  | smt
Q16, Q17, Q19 | 3 | M2P | 3D |  |  |  | smt
Q2, Q32 | 2 | K | 3D |  |  |  | smt
Q20, Q28, Q31 | 3 | W6 | 3D |  |  |  | smt
Q21, Q22, Q23, Q27, Q30, Q35, Q5 | 7 | 8C | SOT-416 |  |  |  | smt
Q25 | 1 | 8LB | SOT-416 |  |  |  | smt
Q26 | 1 | G16 | SOT-23-PC110 |  |  |  | smt
Q29 | 1 | H15 | SOT-23-PC110 |  |  |  | smt
Q36 | 1 | 3P4J | TO-252-2 |  |  |  | smt
Q8 | 1 | 303 5H | SOT-powerT |  |  |  | smt
Q9 | 1 | KD 3.E | SOT-89-3 |  |  |  | smt
R1 | 1 | DNP | R_0603_1608Metric |  |  | Yes | smt
R10, R2, R21, R31, R70, R74, R83, R87, R90 | 9 | 470k | R_0603_1608Metric |  |  |  | smt
R100, R110 | 2 | 7.5k | R_0603_1608Metric |  |  |  | smt
R101, R109, R45, R62, R69, R81 | 6 | 200k | R_0603_1608Metric |  |  |  | smt
R102, R49, R53, R78 | 4 | 300k | R_0603_1608Metric |  |  |  | smt
R103, R11, R114, R117, R13, R17, R19, R20, R30, R33, R35, R4, R44, R52, R61, R63, R64, R85, R86 | 19 | 10k | R_0603_1608Metric |  |  |  | smt
R104, R118, R48 | 3 | 100 | R_0603_1608Metric |  |  |  | smt
R105, R15, R22, R5, R54, R57, R59, R77, R80, R84, R92 | 11 | 100k | R_0603_1608Metric |  |  |  | smt
R106, R27, R39, R41, R51, R58, R60 | 7 | 4.7k | R_0603_1608Metric |  |  |  | smt
R107 | 1 | 2k | R_0603_1608Metric |  |  |  | smt
R108 | 1 | DNP | R_0603_1608Metric |  |  | Yes | smt
R111 | 1 | 33 | R_0603_1608Metric |  |  |  | smt
R112, R113, R18, R9 | 4 | 20k | R_0603_1608Metric |  |  |  | smt
R115 | 1 | 11K | R_0603_1608Metric |  |  |  | smt
R116 | 1 | 15k | R_0603_1608Metric |  |  |  | smt
R12 | 1 | 2.2k | R_0603_1608Metric |  |  |  | smt
R14 | 1 | 12k | R_0603_1608Metric |  |  |  | smt
R16 | 1 | 130k | R_0603_1608Metric |  |  |  | smt
R23, R25, R32, R34 | 4 | 0.1 | R_1206_3216Metric |  |  |  | smt
R24 | 1 | 220 | R_0603_1608Metric |  |  |  | smt
R26 | 1 | 103 (RT1) | R_1206_3216Metric |  |  |  | smt
R28 | 1 | 0 | R_0603_1608Metric |  |  |  | smt
R29 | 1 | 103 (RT2) | R_1206_3216Metric |  |  |  | smt
R3, R36, R65, R71, R72, R75, R76, R93 | 8 | 1k | R_0603_1608Metric |  |  |  | smt
R37 | 1 | 120 | R_0603_1608Metric |  |  |  | smt
R38, R6 | 2 | 470 | R_0603_1608Metric |  |  |  | smt
R40 | 1 | 0.22 | R_1206_3216Metric |  |  |  | smt
R42, R47, R67, R68, R73, R79, R94 | 7 | 47k | R_0603_1608Metric |  |  |  | smt
R43, R56 | 2 | 300 | R_0603_1608Metric |  |  |  | smt
R46, R55, R88, R89 | 4 | 1M | R_0603_1608Metric |  |  |  | smt
R50 | 1 | DNP | R_0603_1608Metric |  |  | Yes | smt
R66 | 1 | DNP | R_0603_1608Metric |  |  | Yes | smt
R7, R8 | 2 | 0.1 | R_1210_3225Metric |  |  |  | smt
R82 | 1 | DNP | R_0603_1608Metric |  |  | Yes | smt
R91 | 1 | DNP | R_1206_3216Metric |  |  | Yes | smt
R95 | 1 | DNP | R_1206_3216Metric |  |  | Yes | smt
R96 | 1 | 1.8k | R_0603_1608Metric |  |  |  | smt
R97 | 1 | DNP | R_1206_3216Metric |  |  | Yes | smt
R98, R99 | 2 | 0 | R_1206_3216Metric |  |  |  | smt
SW1 | 1 | PSU-SW1 | PSU-SW1 |  |  |  | smt
U1 | 1 | D9D | SOT-23-5 |  |  |  | smt
U10 | 1 | 9742 | SSOP-16_4.4x5.2mm_P0.65mm |  |  |  | smt
U11 | 1 | 7W14 | SSOP-8-PSU |  |  |  | smt
U12, U13 | 2 | J421 | SOP-8_3.9x4.9mm_P1.27mm |  |  |  | smt
U2 | 1 | TA | SOT-23-5 |  |  |  | smt
U3 | 1 | 6.5 5F | SOT-23-6_Handsoldering |  |  |  | smt
U4 | 1 | MAX786CAI | TSSOP-28_6.1x9.7mm_P0.65mm |  |  |  | smt
U5 | 1 | K2337 | SOP-8_3.9x4.9mm_P1.27mm |  |  |  | smt
U6 | 1 | 7064 | TSSOP-14_4.4x5mm_P0.65mm |  |  |  | smt
U7 | 1 | 5W01 | SSOP-8-PSU |  |  |  | smt
U8, U9 | 2 | 2556 | SOP-8_3.9x4.9mm_P1.27mm |  |  |  | smt

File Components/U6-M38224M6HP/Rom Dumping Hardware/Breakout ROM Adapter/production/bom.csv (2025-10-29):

Designator | Footprint | Quantity | Value | LCSC Part #
J1, J2 | PinHeader_1x14_P2.54mm_Vertical | 2 | Conn_01x14
U6 | QFN-80 | 1 | M38223E4HP

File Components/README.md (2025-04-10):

## PROM Dump

Here is a list of microcontrollers used on the PC110.
You can find the binary used on them with the disassembler approach.

|Designator|Part#  |Functions |Notes |
|---|---|---|---|
|U6 |M38223*|Power Control, Front LCD & More|[Notes](U6-M38224M6HP/)|
|U67 |M38813*|Keyboard Controller|[Notes](U67-M38813E4HP/) |

## Die level investigation

This part is a collaboration with [John McMaster](https://siliconpr0n.org/archive/doku.php?id=ibm:pc110)

|Designator|Part# |Functions |Images | Notes |
|---|---|---|---|---|
|U75 |D17137AGT  |Trackpoint |[Images](https://siliconpr0n.org/archive/doku.php?id=mcmaster:nec:d17137agt)|[Notes](U75-D17137AGT/)|
|U35 |Pluto |Gate Array |[Images](https://siliconpr0n.org/archive/doku.php?id=mcmaster:rios:z10s10922-00)|[Notes](U35-Pluto/)|
|U21 |Bowman |Gate Array |[Images](https://siliconpr0n.org/archive/doku.php?id=mcmaster:rios:63g33f1017)|[Notes](U21-Bowman/)|
|U61 |VL82C420FC5|Chipset, RTC, DMA, Intrupt Controller, Timer |[Images](https://siliconpr0n.org/archive/doku.php?id=mcmaster:rios:vl82c420fc5-c)|[Notes](U61-VL82C420FC5/)|

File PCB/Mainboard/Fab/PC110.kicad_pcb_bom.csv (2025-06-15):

Designator | Quantity | Value | Footprint | Package | MPN | DNP | Mount_Type | Description
C1 | 1 | DNP | C_0402_1005Metric |  |  | Yes | smt
C10 | 1 | DNP | C_1206_3216Metric |  |  | Yes | smt
C100, C131, C150, C190, C222, C224, C245, C46, C59 | 9 | 10nF | C_0603_1608Metric |  |  |  | smt
C101, C109, C61, C74, C86, C88 | 6 | 180nF | C_0402_1005Metric |  |  |  | smt
C102, C113, C198, C243, C244, C255, C279, C29, C41, C62, C73, C87, C90, C92 | 14 | 120nF | C_0402_1005Metric |  |  |  | smt
C103, C104, C105, C108, C112, C123, C126, C128, C136, C142, C143, C151, C155, C157, C17, C19, C2, C203, C205, C211, C212, C216, C217, C219, C220, C223, C227, C231, C234, C235, C237, C239, C249, C253, C256, C26, C265, C271, C272, C278, C282, C31, C32, C33, C35, C39, C42, C5, C65, C8, C95, C96 | 52 | 150nF | C_0402_1005Metric |  |  |  | smt
C106, C107, C110, C111, C125, C137, C138, C15, C179, C188, C208, C247, C252, C254, C260, C34, C37, C38, C4, C40, C43, C64, C69, C71, C77, C78, C81, C85 | 28 | 1nF | C_0402_1005Metric |  |  |  | smt
C11, C13, C18, C21, C22, C25, C45 | 7 | 270nF | C_0603_1608Metric |  |  |  | smt
C114, C115, C116, C117, C119, C120, C121, C122, C127, C129, C133, C139, C141, C146, C149, C156, C172, C189, C213, C215, C236, C241, C242, C263, C274, C275, C276, C280, C3, C55, C56, C58, C67, C68, C7, C70, C72, C75, C76, C82, C83, C84, C91, C93, C94, C97 | 46 | 100nF | C_0402_1005Metric |  |  |  | smt
C118, C135, C54 | 3 | 2.7uF | C_0805_2012Metric |  |  |  | smt
C12 | 1 | 250nF | C_0603_1608Metric |  |  |  | smt
C124, C134, C202, C218, C221, C246, C273 | 7 | 150nF | C_0603_1608Metric |  |  |  | smt
C130, C140, C147, C153, C158, C168, C225, C226, C229, C238, C248, C277, C66, C79 | 14 | 1uF | C_0603_1608Metric |  |  |  | smt
C132, C57, C60, C63 | 4 | 100nF | C_0603_1608Metric |  |  |  | smt
C14, C152, C160, C161, C162, C200, C201, C204, C206, C209, C210, C214, C23, C232, C30, C36, C51, C9 | 18 | 10uF | C_1206_3216Metric |  |  |  | smt
C144, C145, C154, C16, C228, C99 | 6 | 100pF | C_0402_1005Metric |  |  |  | smt
C148 | 1 | DNP | C_0402_1005Metric |  |  | Yes | smt
C159 | 1 | DNP | C_0402_1005Metric |  |  | Yes | smt
C163, C167, C170, C199, C258, C269 | 6 | 220pF | C_0402_1005Metric |  |  |  | smt
C164, C233, C259 | 3 | 330nF | C_0603_1608Metric |  |  |  | smt
C165 | 1 | DNP | C_0402_1005Metric |  |  | Yes | smt
C166, C197, C207, C240 | 4 | 300nF | C_0603_1608Metric |  |  |  | smt
C169, C171, C173, C174, C175, C177, C178, C180, C181, C182, C183, C184, C185, C186, C187, C191, C192, C193, C194, C195, C196, C264 | 22 | 56pF | C_0402_1005Metric |  |  |  | smt
C176, C89 | 2 | 470nF | C_0603_1608Metric |  |  |  | smt
C20 | 1 | 1.5nF | C_0402_1005Metric |  |  |  | smt
C230 | 1 | DNP | C_0402_1005Metric |  |  | Yes | smt
C24 | 1 | DNP | C_0402_1005Metric |  |  | Yes | smt
C250, C251, C27, C28 | 4 | 18pF | C_0402_1005Metric |  |  |  | smt
C257 | 1 | DNP | C_0402_1005Metric |  |  | Yes | smt
C261 | 1 | DNP | C_0402_1005Metric |  |  | Yes | smt
C262 | 1 | 1.5uF | C_0805_2012Metric |  |  |  | smt
C266 | 1 | 180pF | C_0402_1005Metric |  |  |  | smt
C267 | 1 | DNP | C_0402_1005Metric |  |  | Yes | smt
C268 | 1 | 56pf | C_0402_1005Metric |  |  |  | smt
C270 | 1 | DNP | C_0402_1005Metric |  |  | Yes | smt
C281, C283 | 2 | 39pF | C_0402_1005Metric |  |  |  | smt
C44 | 1 | 5.6nF | C_0402_1005Metric |  |  |  | smt
C47 | 1 | 5.6uF | C_1206_3216Metric |  |  |  | smt
C48 | 1 | 330nF | C_0402_1005Metric |  |  |  | smt
C49 | 1 | 2.2uF | C_0805_2012Metric |  |  |  | smt
C50 | 1 | DNP | C_0402_1005Metric |  |  | Yes | smt
C52, C53 | 2 | 22pF | C_0402_1005Metric |  |  |  | smt
C6 | 1 | DNP | C_0402_1005Metric |  |  | Yes | smt
C80 | 1 | 1uF | C_0603_1608Metric |  |  | Yes | smt
C98 | 1 | 330pF | C_0402_1005Metric |  |  |  | smt
D1, D16, D18, D21, D22, D24, D25, D26, D27, D28, D29, D3, D35, D5 | 14 | 3D | 3D |  |  |  | smt
D10, D13, D2, D32, D58 | 5 | K | SOT-416L |  |  |  | smt
D11 | 1 | DNP | 3D |  |  | Yes | smt
D12 | 1 | DNP | 3D |  |  | Yes | smt
D14, D15, D17, D19, D30, D31, D37, D4, D40, D42, D43, D45, D46, D49 | 14 | N | SOT-416L |  |  |  | smt
D20, D59 | 2 | 3D | SOT-416L |  |  |  | smt
D23 | 1 | 92 | D_0603_1608Metric |  |  |  | smt
D33 | 1 | N | SOT-416 |  |  |  | smt
D34 | 1 | DNP | 3D |  |  | Yes | smt
D36 | 1 | 71 | D_0603_1608Metric |  |  |  | smt
D38 | 1 | 40 | D_0603_1608Metric |  |  |  | smt
D39, D55 | 2 | s.3 5F | Diode |  |  |  | smt
D41, D47 | 2 | 24 | D_0603_1608Metric |  |  |  | smt
D44 | 1 | 83 | D_0603_1608Metric |  |  |  | smt
D48 | 1 | A2 | D_0603_1608Metric |  |  |  | smt
D50 | 1 | 26 | D_0603_1608Metric |  |  |  | smt
D51 | 1 | C6 | D_0603_1608Metric |  |  |  | smt
D52, D53, D54, D56, D57 | 5 | K | SOT-416 |  |  |  | smt
D6, D7 | 2 | Q | 3D |  |  |  | smt
D60 | 1 | 3D | SOT-23 |  |  |  | smt
D8 | 1 | DNP | 3D |  |  | Yes | smt
D9 | 1 | DNP | 3D |  |  | Yes | smt
EM1, EM2, EM3, EM4, EM5 | 5 | R-array | R-array |  |  |  | smt
F1, F3, F4 | 3 | 0.5A | Fuse_1206_3216Metric |  |  |  | smt
F2 | 1 | 1.0A | Fuse_1206_3216Metric |  |  |  | smt
J1 | 1 | PS2 | PS2 |  |  |  | smt
J10 | 1 | PCMCIA | PCMCIA |  |  |  | smt
J11 | 1 | CF-card | CF-card |  |  |  | smt
J12 | 1 | Debug-6 | Debug-6 |  |  |  | smt
J13 | 1 | Docking Port | Docking Port |  |  |  | smt
J15 | 1 | RAM Module | RAM Module |  |  |  | smt
J16 | 1 | Flat-20 | Flat-20 |  |  |  | smt
J17 | 1 | Flat-8 | Flat-8 |  |  |  | smt
J18 | 1 | Flat-4 | Flat-4 |  |  |  | smt
J19 | 1 | Flat-18 | Flat-18 |  |  |  | smt
J2 | 1 | LCD_connector | LCD_connector |  |  |  | smt
J3 | 1 | Audio-Jack | Audio-Jack |  |  |  | smt
J4 | 1 | connector-4 | connector-4 |  |  |  | smt
J5 | 1 | PSU_Connector | PSU_Connector |  |  |  | smt
J6 | 1 | BridgeBatt | BridgeBatt |  |  |  | smt
J7 | 1 | SPKR | SPKR |  |  |  | smt
J8 | 1 | Modem-Connector | Modem-Connector |  |  |  | smt
J9 | 1 | Debug-10 | Debug-10 |  |  |  | smt
L1, L11, L13, L14, L15, L16, L17, L18, L2, L3, L5, L6, L7, L8 | 14 | 1.5uH | L_0603_1608Metric |  |  |  | smt
L10, L12, L9 | 3 | 300nH | L_0805_2012Metric |  |  |  | smt
L4 | 1 | 68uH | L_1210_3225Metric |  |  |  | smt
Q1, Q11, Q13 | 3 | IS6 | SOT-23 |  |  |  | smt
Q10, Q12, Q14, Q18, Q2, Q26, Q27, Q30, Q38, Q7 | 10 | 8C | SOT-416 |  |  |  | smt
Q15, Q19, Q21, Q23, Q32 | 5 | 8B | SOT-416 |  |  |  | smt
Q16 | 1 | IS6 | TSOT-23 |  |  |  | smt
Q17, Q8 | 2 | 6D | 3D |  |  |  | smt
Q20, Q36 | 2 | 7C | TSOT-23 |  |  |  | smt
Q22, Q4 | 2 | YQ | SOT-416L |  |  |  | smt
Q24, Q31 | 2 | 6D | SOT-23 |  |  |  | smt
Q25, Q33, Q34, Q37 | 4 | BH RT | SOT-89-3 |  |  |  | smt
Q28 | 1 | 8LR | SOT-416 |  |  |  | smt
Q29 | 1 | DNP | SOT-23 |  |  | Yes | smt
Q3 | 1 | 582 B74 | SOT-89-3 |  |  |  | smt
Q35, Q9 | 2 | 8C | SOT-523 |  |  |  | smt
Q39, Q40 | 2 | HQ | TSOT-23 |  |  |  | smt
Q41, Q42 | 2 | CQ | TSOT-23 |  |  |  | smt
Q43, Q44 | 2 | 8B | SOT-523 |  |  |  | smt
Q5 | 1 | HQ | SOT-416L |  |  |  | smt
Q6 | 1 | ST3 | SOT-416L |  |  |  | smt
R1, R10, R102, R105, R11, R113, R119, R122, R123, R124, R125, R126, R127, R128, R13, R130, R135, R139, R144, R146, R147, R148, R15, R152, R156, R158, R160, R161, R162, R173, R18, R182, R183, R186, R187, R189, R19, R190, R191, R194, R2, R215, R216, R217, R218, R22, R224, R228, R229, R233, R235, R243, R244, R245, R247, R248, R259, R262, R269, R27, R278, R282, R287, R302, R303, R305, R306, R307, R309, R311, R314, R315, R327, R33, R360, R361, R379, R5, R6, R61, R7, R77, R80, R82, R83, R90, R91, R94 | 88 | 470k | R_0402_1005Metric |  |  |  | smt
R100, R291, R297 | 3 | 220 | R_0402_1005Metric |  |  |  | smt
R101, R103, R106, R149, R154, R159, R251, R252, R255, R257, R261, R272, R274, R317, R318, R322, R324, R326, R329, R332, R333, R334, R335, R337, R338, R340, R341, R342, R343, R345, R346, R347, R348, R350, R352, R357, R359, R46, R53 | 39 | 33 | R_0402_1005Metric |  |  |  | smt
R104, R112, R114, R117, R165, R171, R177, R196, R197, R200, R204, R206, R240, R246, R249, R254, R280, R288, R312, R356, R385, R39, R393, R397, R40, R408, R411, R85, R93, R95, R96 | 31 | 47k | R_0402_1005Metric |  |  |  | smt
R107, R276, R383 | 3 | 33k | R_0402_1005Metric |  |  |  | smt
R108, R185, R24, R263, R265, R270, R275, R279, R283, R304, R328, R330, R331, R336, R339, R351, R354, R355, R373, R374, R375, R376, R377, R378, R38, R380, R381, R4, R42, R86, R89, R9, R98 | 33 | 4.7k | R_0402_1005Metric |  |  |  | smt
R109, R110, R115, R134, R143, R163, R164, R166, R168, R169, R170, R172, R174, R175, R176, R178, R179, R181, R188, R192, R193, R198, R203, R220, R227, R232, R237, R258, R281, R289, R320, R325, R36, R365, R384, R389, R391, R395, R396, R41, R71, R74, R78, R97 | 44 | 10k | R_0402_1005Metric |  |  |  | smt
R111 | 1 | 100 | R_0603_1608Metric |  |  |  | smt
R116, R118, R120, R121, R150, R151, R153, R155, R157, R167, R201, R205, R209, R212, R214, R219, R223, R234, R268, R310, R321, R349, R35, R363, R37, R372, R390, R401, R404, R405, R406, R407, R413, R44, R45, R49, R57, R59, R81, R87 | 40 | 100k | R_0402_1005Metric |  |  |  | smt
R12 | 1 | 182k | R_0402_1005Metric |  |  |  | smt
R129, R260 | 2 | 133k | R_0402_1005Metric |  |  |  | smt
R131 | 1 | DNP | R_0402_1005Metric |  |  | Yes | smt
R132, R133, R137, R362, R371 | 5 | 2k | R_0402_1005Metric |  |  |  | smt
R136, R138, R140, R141, R142, R25, R29, R316, R319, R323, R34, R386, R76 | 13 | 1k | R_0402_1005Metric |  |  |  | smt
R14, R17, R20, R308 | 4 | 10 | R_0402_1005Metric |  |  |  | smt
R145 | 1 | DNP | R_0402_1005Metric |  |  | Yes | smt
R16, R195, R21, R221, R23, R285, R295, R299, R30, R366, R367, R370, R51, R58, R67, R72, R75, R79, R84, R88 | 20 | 0 | R_0402_1005Metric |  |  |  | smt
R180 | 1 | 180k | R_0402_1005Metric |  |  |  | smt
R184 | 1 | DNP | R_0402_1005Metric |  |  | Yes | smt
R199 | 1 | DNP | R_0402_1005Metric |  |  | Yes | smt
R202 | 1 | DNP | R_0402_1005Metric |  |  | Yes | smt
R207, R208, R211, R213, R52 | 5 | 120k | R_0402_1005Metric |  |  |  | smt
R210 | 1 | 100K | R_0402_1005Metric |  |  |  | smt
R222, R225 | 2 | 6.8k | R_0402_1005Metric |  |  |  | smt
R226 | 1 | 120 | R_1206_3216Metric |  |  |  | smt
R230, R250, R300 | 3 | 0 | R_0805_2012Metric |  |  |  | smt
R231 | 1 | 0 | R_0603_1608Metric |  |  |  | smt
R236, R99 | 2 | 470 | R_0402_1005Metric |  |  |  | smt
R238, R239 | 2 | 56 | R_0603_1608Metric |  |  |  | smt
R241 | 1 | 8.2 | R_1206_3216Metric_Pad1.30x1.75mm_HandSolder |  |  |  | smt
R242, R412 | 2 | 7.5k | R_0402_1005Metric |  |  |  | smt
R253 | 1 | DNP | R_0402_1005Metric |  |  | Yes | smt
R256 | 1 | 100 | R_0805_2012Metric |  |  |  | smt
R26, R32, R409, R69, R73 | 5 | 2.2k | R_0402_1005Metric |  |  |  | smt
R264, R267, R273 | 3 | 150 | R_0805_2012Metric |  |  |  | smt
R266, R382, R60 | 3 | 50k | R_0402_1005Metric |  |  |  | smt
R271 | 1 | DNP | R_0402_1005Metric |  |  | Yes | smt
R277 | 1 | 200k | R_0402_1005Metric |  |  |  | smt
R28 | 1 | 56 | R_1206_3216Metric |  |  |  | smt
R284 | 1 | 10 | R_0805_2012Metric |  |  |  | smt
R286, R293, R369, R392, R398, R399 | 6 | 22k | R_0402_1005Metric |  |  |  | smt
R290 | 1 | DNP | R_0402_1005Metric |  |  | Yes | smt
R292 | 1 | DNP | R_0805_2012Metric |  |  | Yes | smt
R294 | 1 | 1.2k | R_0402_1005Metric |  |  |  | smt
R296 | 1 | DNP | R_0402_1005Metric |  |  | Yes | smt
R298 | 1 | DNP | R_0402_1005Metric |  |  | Yes | smt
R3 | 1 | 131k | R_0402_1005Metric |  |  |  | smt
R301 | 1 | DNP | R_0402_1005Metric |  |  | Yes | smt
R31, R8 | 2 | 300 | R_0402_1005Metric |  |  |  | smt
R313 | 1 | 300 | R_0805_2012Metric |  |  |  | smt
R344 | 1 | DNP | R_0402_1005Metric |  |  | Yes | smt
R353 | 1 | 56 | R_0402_1005Metric |  |  |  | smt
R358, R92 | 2 | 47 | R_0402_1005Metric |  |  |  | smt
R364 | 1 | DNP | R_0402_1005Metric |  |  | Yes | smt
R368 | 1 | 1.5k | R_0402_1005Metric |  |  |  | smt
R387 | 1 | DNP | R_0402_1005Metric |  |  | Yes | smt
R388 | 1 | 3K | R_0402_1005Metric |  |  |  | smt
R394 | 1 | DNP | R_0402_1005Metric |  |  | Yes | smt
R400 | 1 | DNP | R_0402_1005Metric |  |  | Yes | smt
R402 | 1 | DNP | R_0402_1005Metric |  |  | Yes | smt
R403 | 1 | DNP | R_0402_1005Metric |  |  | Yes | smt
R410 | 1 | 20k | R_0402_1005Metric |  |  |  | smt
R43, R62, R63 | 3 | 68k | R_0402_1005Metric |  |  |  | smt
R47 | 1 | DNP | R_0402_1005Metric |  |  | Yes | smt
R48 | 1 | DNP | R_0402_1005Metric |  |  | Yes | smt
R50 | 1 | DNP | R_0402_1005Metric |  |  | Yes | smt
R54 | 1 | DNP | R_0402_1005Metric |  |  | Yes | smt
R55 | 1 | DNP | R_0402_1005Metric |  |  | Yes | smt
R56 | 1 | DNP | R_0402_1005Metric |  |  | Yes | smt
R64 | 1 | DNP | R_0402_1005Metric |  |  | Yes | smt
R65 | 1 | DNP | R_0402_1005Metric |  |  | Yes | smt
R66 | 1 | 270 | R_0402_1005Metric |  |  |  | smt
R68 | 1 | 56 | R_0805_2012Metric |  |  |  | smt
R70 | 1 | DNP | R_0402_1005Metric |  |  | Yes | smt | External clock input for Audio Drive
RA1 | 1 | 47k | R-array |  |  |  | smt
RA2, RA4 | 2 | 10k | R-array |  |  |  | smt
RA3 | 1 | 22k | R-array |  |  |  | smt
RA5 | 1 | 470k | R-array |  |  |  | smt
SW1 | 1 | Switch | Switch |  |  |  | smt
SW2 | 1 | LidSwitch | LidSwitch |  |  |  | smt
U1, U14, U15, U23, U52, U58 | 6 | EA | SOT-353 |  |  |  | smt
U10 | 1 | YM3812 | SOP-24 |  |  |  | smt
U11, U44 | 2 | NJM2904M | soic-8-small |  |  |  | smt
U12 | 1 | LM4861 | SOIC-8-narrow |  |  |  | smt | Audio Amp
U13, U16 | 2 | 8C01 | SOT-23-5 |  |  |  | smt
U17 | 1 | 3E00 | SOT-23-5 |  |  |  | smt
U18 | 1 | VT74 | TSSOP-14_4.4x5mm_P0.65mm |  |  |  | smt
U19, U26 | 2 | 7W126 | sso-8 |  |  |  | smt
U2 | 1 | 7W32 | sso-8 |  |  |  | smt
U20, U38 | 2 | 7W14 | sso-8 |  |  |  | smt
U21 | 1 | Bowman | Bowman |  |  |  | smt
U22 | 1 | FDC37C665IR | FDC |  |  |  | smt
U24, U25, U65, U9 | 4 | E4 | SOT-353 |  |  |  | smt
U27 | 1 | AT29LV512-12TU | Flash-32 |  |  |  | smt
U28, U33 | 2 | M5M4V16160BTP | RAMchip |  |  |  | smt
U29 | 1 | E2 | SOT-353 |  |  |  | smt
U3 | 1 | HSDL-1000 X03 | IRDA |  |  |  | smt
U30 | 1 | 74LVT74 | TSSOP-14_4.4x5mm_P0.65mm |  |  |  | smt
U31 | 1 | 3F01 | SOT-23-5 |  |  |  | smt
U32 | 1 | V74 | TSSOP-14_4.4x5mm_P0.65mm |  |  |  | smt
U34 | 1 | 74LV126 | TSSOP-14_4.4x5mm_P0.65mm |  |  |  | smt
U35 | 1 | Pluto | Pluto |  |  |  | smt
U36 | 1 | MSM538032E | SOP48 |  |  |  | smt
U37 | 1 | E8 | SOT-353 |  |  |  | smt
U39 | 1 | 7W00 | sso-8 |  |  |  | smt
U4 | 1 | ES488F | QFN-52 |  |  |  | smt
U40 | 1 | SN74LS74a | TSSOP-14_4.4x5mm_P0.65mm |  |  |  | smt
U41 | 1 | SDLB-4 | SanDisk |  |  |  | smt
U42 | 1 | SC414281PU4 | QFN-100 |  |  |  | smt
U43 | 1 | Front LCD | LCD |  |  |  | tht
U45 | 1 | SN74LS123A | TSSOP-16_4.4x5mm_P0.65mm |  |  |  | smt
U46 | 1 | Y3014 | SOP-16 |  |  |  | smt
U47 | 1 | 3414A | SOIC-8 |  |  |  | smt
U48 | 1 | DS1669 | SOIC-8 |  |  |  | smt | Digital Rheostat
U49, U72 | 2 | HD151015 | SSOP-24_5.3x8.2mm_P0.65mm |  |  |  | smt | 9 bit Level Shifter/Transceiver With 3 State Outputs
U5 | 1 | 74HC14 | TSSOP-14_4.4x5mm_P0.65mm |  |  |  | smt
U50 | 1 | 3T01 | SOT-23-5 |  |  |  | smt
U51 | 1 | CHIPS65535 | BGA-169 |  |  |  | smt
U53 | 1 | 3F01 | TSOP-5_1.65x3.05mm_P0.95mm |  |  |  | smt
U54 | 1 | SN74HC74 | TSSOP-14_4.4x5mm_P0.65mm |  |  |  | smt | Dual D-Type Positive-Edge-Triggered Flip-Flops With Clear and Preset
U55 | 1 | 3T01 | TSOP-5_1.65x3.05mm_P0.95mm |  |  |  | smt
U56, U71 | 2 | SN74LV32 | TSSOP-14_4.4x5mm_P0.65mm |  |  |  | smt | Quadruple 2-Input Positive-Or Gates
U57, U62 | 2 | SN74LVT125 | TSSOP-14_4.4x5mm_P0.65mm |  |  |  | smt | ABT QUADRUPLE BUS BUFFER WITH 3STATE OUTPUTS
U59 | 1 | 28F002BX | Flash-40 |  |  |  | smt
U6 | 1 | M38223E4HP | QFN-80 |  |  |  | smt
U60 | 1 | E3 | SOT-353 |  |  |  | smt
U61 | 1 | VL82C420 | BGA-256 |  |  |  | smt
U63 | 1 | AV9154A-27 | SOIC-16W |  |  |  | smt
U64 | 1 | SN74LV126 | TSSOP-14_4.4x5mm_P0.65mm |  |  |  | smt | Quadruple Bus Buffer Gates With 3-State Outputs
U66 | 1 | SN74LV02 | TSSOP-14_4.4x5mm_P0.65mm |  |  |  | smt | Quadruple 2-Input Positive-NOR Gates
U67 | 1 | M38813M4 | QFN64 |  |  |  | smt | Keyboard controller
U68 | 1 | SN74LV08 | TSSOP-14_4.4x5mm_P0.65mm |  |  |  | smt
U69 | 1 | SN74LVC2G32 | SSOP-8_2.95x2.8mm_P0.65mm |  |  |  | smt | Dual 2-Input Positive-OR Gate
U7 | 1 | HD151015 | TSSOP-24_6.1x7.8mm_P0.65mm |  |  |  | smt
U70 | 1 | TPS2201 | TSSOP-30_6.1x9.7mm_P0.65mm |  |  |  | smt | Dual-Slot PC Card Power-Interface Switches
U73 | 1 | SN74LVT244B | TSSOP-20_4.4x6.5mm_P0.65mm |  |  |  | smt | ABT OCTAL BUFFER/DRIVER
U74 | 1 | RB5C396 | BGA-256 |  |  |  | smt
U75 | 1 | D17137AGT | SSOP-28 |  |  |  | smt | Trackpad Controller
U76 | 1 | 486SX-33 | BGA-256 |  |  |  | smt | Intel 486 SX
U8 | 1 | 51W4260ATT7 | GRAMchip |  |  |  | smt
X1 | 1 | 245759 | XTAL-2 |  |  |  | smt
X2 | 1 | 89G6821 | XTAL-1 |  |  |  | smt
X3 | 1 | 32768 | XTAL-3 |  |  |  | smt
X4 | 1 | 59G3482 | XTAL-6 |  |  |  | smt
X5 | 1 | 4.00 | XTAL-5 |  |  |  | smt
X6 | 1 | 8.00 | XTAL-4 |  |  |  | smt

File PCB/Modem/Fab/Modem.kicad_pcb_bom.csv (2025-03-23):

Designator | Quantity | Value | Footprint | Package | MPN | DNP | Mount_Type
C1, C4, C52, C54 | 4 | 330nF | C_0603_1608Metric |  |  |  | smt
C12, C45 | 2 | 47uF 16v | C_1812_4532Metric |  |  |  | smt
C13 | 1 | 822J | C_1206_3216Metric |  |  |  | smt
C15, C2, C32 | 3 | 1.2uF | C_0603_1608Metric |  |  |  | smt
C2, C34 | 2 | 1nF | C_0603_1608Metric |  |  |  | smt
C23 | 1 | 1.2uF | C_0805_2012Metric |  |  |  | smt
C24, C37 | 2 | 230nF | C_0603_1608Metric |  |  |  | smt
C26 | 1 | 10nF | C_0603_1608Metric |  |  |  | smt
C28 | 1 | 8.1uF | C_1206_3216Metric |  |  |  | smt
C29, C30 | 2 | 1.5uF | C_0603_1608Metric |  |  |  | smt
C3 | 1 | 30nF | C_0603_1608Metric |  |  |  | smt
C31 | 1 | 230nF | C_1206_3216Metric |  |  |  | smt
C38 | 1 | 2.2uF | C_0603_1608Metric |  |  |  | smt
C39 | 1 | 100nF | C_0603_1608Metric |  |  |  | smt
C39, C48 | 2 | 25nF | C_0603_1608Metric |  |  |  | smt
C40 | 1 | 16nF | C_0603_1608Metric |  |  |  | smt
C41, C43 | 2 | 1uF | C_0603_1608Metric |  |  |  | smt
C42, C51 | 2 | 1.2nF | C_0603_1608Metric |  |  |  | smt
C46, C47 | 2 | 24nF | C_0603_1608Metric |  |  |  | smt
C5 | 1 | 250nF | C_0603_1608Metric |  |  |  | smt
C56 | 1 | 1.6nF | C_0402_1005Metric |  |  |  | smt
C56 | 1 | 470nF | C_0603_1608Metric |  |  |  | smt
C57 | 1 | 6.8uF | C_1206_3216Metric |  |  |  | smt
C58 | 1 | 220nF | C_0603_1608Metric |  |  |  | smt
C59, C60, C62 | 3 | 280nF | C_2220_5750Metric |  |  |  | smt
C70, C72 | 2 | 1.8uF | C_0603_1608Metric |  |  |  | smt
C71 | 1 | 1.3uF | C_0805_2012Metric |  |  |  | smt
C73 | 1 | 100pF | C_0402_1005Metric |  |  |  | smt
C74 | 1 | 220nF | C_0805_2012Metric |  |  |  | smt
CNP1 | 1 | Line_Connector | Line_Connector |  |  |  | smt
CNP2 | 1 | modem_heaset_jack | modem_heaset_jack |  |  |  | smt
CNP3 | 1 | JST_8_headset_connector | JST_8_headset_connector |  |  |  | smt
CNP4 | 1 | Modem-Connector | Modem-Connector |  |  |  | smt
CNP5 | 1 | JST_2_modem_spkr | JST_2_modem_spkr |  |  |  | smt
D1, D7, D9 | 3 | TO-269AA | TO-269AA |  |  |  | smt
D10 | 1 | 152 | D_1206_3216Metric |  |  |  | smt
D2 | 1 | 1N4148 | D_SOD-128 |  |  |  | smt
D3, D4, D8 | 3 | 5 | D_1206_3216Metric_modem |  |  |  | smt
D5 | 1 | 3D | SOT-323_SC-70 |  |  |  | smt
D6 | 1 | 30H | SOT-23-3 |  |  |  | smt
DA1 | 1 | M1T | DA_Modem |  |  |  | smt
IC10 | 1 | AT32 433 | TSSOP-14_4.4x5mm_P0.65mm |  |  |  | smt
IC11 | 1 | EN29F040A | TSOP-I-32_18.4x8mm_P0.5mm_Reverse |  |  |  | smt
IC12 | 1 | KM681000BLT-7 (I-Reverse) | TSOP-I-32_18.4x8mm_P0.5mm_Reverse |  |  |  | smt
IC13, IC17, IC2, IC7, IC9 | 5 | EA | SOT-353_SC-70-5 |  |  |  | smt
IC14 | 1 | E4 | SOT-353_SC-70-5 |  |  |  | smt
IC15 | 1 | 8206 5877 | SOIC-8_5.3x6.2mm_P1.27mm |  |  |  | smt
IC16 | 1 | E3 | SOT-353_SC-70-5 |  |  |  | smt
IC18 | 1 | 3L01 | TSOT-23-5 |  |  |  | smt
IC3 | 1 | Line-Module | Line-Module |  |  |  | smt
IC4 | 1 | E5 | SOT-353_SC-70-5 |  |  |  | smt
IC5 | 1 | MN195 | MN195 |  |  |  | smt
IC6 | 1 | 54 | SOT-353_SC-70-5 |  |  |  | smt
IC8 | 1 | TA31033F | SOIC-16_4.55x10.3mm_P1.27mm |  |  |  | smt
L1, L2 | 2 | 1.2uH | L_1206_3216Metric |  |  |  | smt
L3, L5 | 2 | 1.8uH | L_0603_1608Metric |  |  |  | smt
L4 | 1 | 1.2uH | L_0603_1608Metric |  |  |  | smt
NF1 | 1 | 300nH | L_1206_3216Metric |  |  |  | smt
NF2, NF4 | 2 | 4.7nH | L_1206_3216Metric |  |  |  | smt
NF3 | 1 | 0 | L_1206_3216Metric |  |  |  | smt
OSC1 | 1 | 41.472 | Oscillator_SMD_Fordahl_DFAS2-4Pin_7.3x5.1mm |  |  |  | smt
PC2 | 1 | TLP124 | Everlight_ITR8307_Reverse |  |  |  | smt
Q1, Q4 | 2 | CQ | SOT-323_SC-70 |  |  |  | smt
Q2 | 1 | DA QU | SOT-89-3 |  |  |  | smt
Q3 | 1 | 123 | SOT-323_SC-70 |  |  |  | smt
Q7 | 1 | SOT-323_SC-70 | SOT-323_SC-70 |  |  |  | smt
Q9 | 1 | HP | SOT-323_SC-70 |  |  |  | smt
R1 | 1 | 12k | R_0402_1005Metric |  |  |  | smt
R10, R11, R68 | 3 | 38k | R_0402_1005Metric |  |  |  | smt
R100, R51, R72, R72, R90 | 5 | 470k | R_0402_1005Metric |  |  |  | smt
R101, R102, R103, R104, R105, R106, R107, R108, R109, R110, R111, R112, R114, R115, R116, R117, R118, R119, R120, R121, R122, R123, R124, R124, R125, R126, R127, R129, R130, R131, R132 | 31 | 100 | R_0402_1005Metric |  |  |  | smt
R12, R75 | 2 | 2.2k | R_2010_5025Metric |  |  |  | smt
R13, R133, R16, R17, R19, R21, R47, R49, R62, R67, R82 | 11 | 10k | R_0402_1005Metric |  |  |  | smt
R14 | 1 | 560k | R_0402_1005Metric |  |  |  | smt
R15 | 1 | 330k | R_0402_1005Metric |  |  |  | smt
R18, R46 | 2 | 1.5k | R_0402_1005Metric |  |  |  | smt
R2, R28, R29, R3, R30, R31, R32, R36, R37, R38, R41, R43 | 12 | 4.7k | R_0402_1005Metric |  |  |  | smt
R20, R63, R81, R9 | 4 | 100k | R_0402_1005Metric |  |  |  | smt
R22 | 1 | DNP | R_0402_1005Metric |  |  | Yes | smt
R23 | 1 | DNP | R_0402_1005Metric |  |  | Yes | smt
R24 | 1 | 200 | R_0603_1608Metric |  |  |  | smt
R25 | 1 | 500k | R_0402_1005Metric |  |  |  | smt
R26, R33, R34, R7 | 4 | 10 | R_1206_3216Metric |  |  |  | smt
R27 | 1 | DNP | R_0402_1005Metric |  |  | Yes | smt
R35 | 1 | 20 | R_1206_3216Metric |  |  |  | smt
R4 | 1 | 330 | R_0402_1005Metric |  |  |  | smt
R42 | 1 | 15k | R_0402_1005Metric |  |  |  | smt
R44 | 1 | 51 | R_0402_1005Metric |  |  |  | smt
R48 | 1 | 3.3 | R_1206_3216Metric |  |  |  | smt
R5 | 1 | 100 | R_0603_1608Metric |  |  |  | smt
R50 | 1 | 6.2k | R_0603_1608Metric |  |  |  | smt
R52, R70, R71 | 3 | 1k | R_0402_1005Metric |  |  |  | smt
R53 | 1 | 11k | R_0603_1608Metric |  |  |  | smt
R54 | 1 | 1.5k | R_0603_1608Metric |  |  |  | smt
R55 | 1 | 82 | R_2010_5025Metric |  |  |  | smt
R56 | 1 | 15 | R_1206_3216Metric |  |  |  | smt
R57 | 1 | 150 | R_0603_1608Metric |  |  |  | smt
R58 | 1 | 620 | R_0603_1608Metric |  |  |  | smt
R59, R60 | 2 | 2.2k | R_0402_1005Metric |  |  |  | smt
R6 | 1 | 3.3k | R_0603_1608Metric |  |  |  | smt
R61 | 1 | 3.6k | R_0402_1005Metric |  |  |  | smt
R65 | 1 | 15 | R_0402_1005Metric |  |  |  | smt
R68 | 1 | 20k | R_0402_1005Metric |  |  |  | smt
R73 | 1 | 120 | R_0603_1608Metric |  |  |  | smt
R76 | 1 | 2.4k | R_0402_1005Metric |  |  |  | smt
R77 | 1 | 270k | R_0402_1005Metric |  |  |  | smt
R78 | 1 | 5.6k | R_0402_1005Metric |  |  |  | smt
R8 | 1 | 22k | R_0402_1005Metric |  |  |  | smt
R92 | 1 | 47k | R_0402_1005Metric |  |  |  | smt
R98, R99 | 2 | 100 | R_0805_2012Metric |  |  |  | smt
RL1 | 1 | RL | RL |  |  |  | smt
SW2 | 1 | SW_modem | SW_modem |  |  |  | smt
T1 | 1 | IsoTransformer | IsoTransformer |  |  |  | smt
VA1 | 1 | R_2512_6332Metric | R_2512_6332Metric |  |  |  | smt

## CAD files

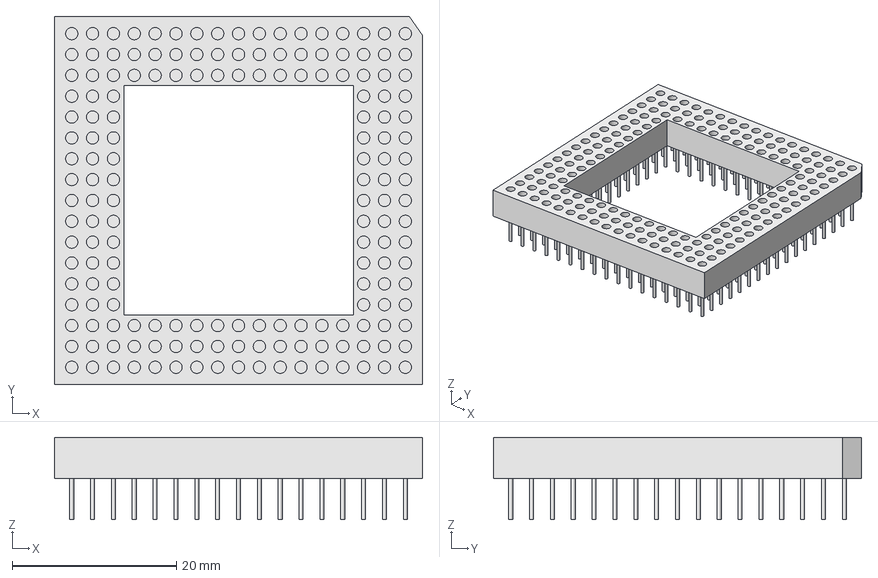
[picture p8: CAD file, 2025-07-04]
Modifications/PC110-ITX/486_Socket.step
44.8 x 44.8 x 10.0 mm

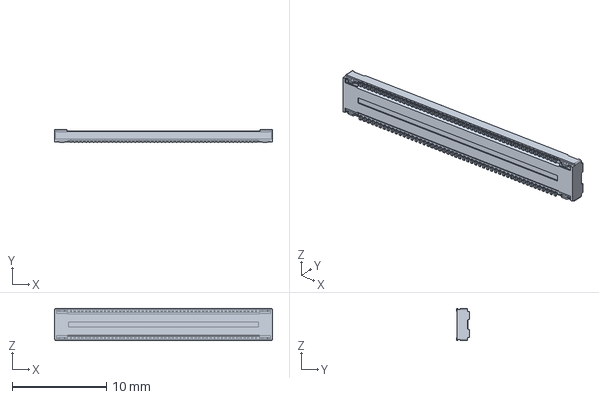
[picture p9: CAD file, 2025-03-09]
Modifications/CPU Upgrade/bgacpu-dualcon/3D/51338-1074.stp
23.1 x 1.40 x 3.40 mm

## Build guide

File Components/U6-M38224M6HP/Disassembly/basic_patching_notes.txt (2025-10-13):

C300	280	60	Made sense
C310	290	60	Made sense
C600	580	50	Made sense but not sure
C900	880	10	Cant patch with my ghidra :(
C980	900	85	Made sense
D000	F80	65	Made sense but less sure
D280	1200	04	Made sense
DC00	1B80	D8	Made sense but less sure
E230	21B0	60	Made sense
E500	2480	00	Cant patch with my ghidra :(
E530	24B0	05	Made Sense
E630	25B0	60	Made Sense
E880	2800	D3	Made sense bit not sure

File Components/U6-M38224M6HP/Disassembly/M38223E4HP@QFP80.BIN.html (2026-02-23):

                            ;************************************************************************************************
                            ;*  P0-0 : Connected to BOWMAN P105                                                             *
                            ;*  P0-1 : Connected to BOWMAN P104                                                             *
                            ;*  P0-2 : Connected to BOWMAN P103                                                             *
                            ;*  P0-3 : Connected to BOWMAN P102                                                             *
                            ;*  P0-4 : Connected to BOWMAN P101                                                             *
                            ;*  P0-5 : Connected to BOWMAN P99                                                              *
                            ;*  P0-6 : Connected to BOWMAN P98                                                              *
                            ;*  P0-7 : Connected to BOWMAN P97                                                              *
                            ;************************************************************************************************
                            P0:                           ;XREF[6,0]:   cdee,ce22,dc79,dc82,e06d,e099
ZERO_PAGE:0000                  db          ??                                      
                            ;************************************************************************************************
                            ;*  // Port P0 Direction Register (P0D) [Address 0x01]                                          *
                            ;*  // Bit 0: Sets Port P0 mode — 0 = input, 1 = output                                         *
                            ;*  // Bits 1-7: Not allocated; cannot be read or written                                       *
                            ;************************************************************************************************
                            P0D:                          ;XREF[7,0]:   cdf1,ce25,e070,e09c,e71f,e76f,e794
ZERO_PAGE:0001                  db          ??                                      
                            ;************************************************************************************************
                            ;*  P1-0 : ON connects Touch_Y- to GND                                                          *
                            ;*  P1-1 : OFF connects Touch_Y+ to PWR                                                         *
                            ;*  P1-2 : ON connects Touch_X- to GND                                                          *
                            ;*  P1-3 : OFF connects Touch_X+ to PWR                                                         *
                            ;*  P1-4 : Connects to BOWMAN pin 107                                                           *
                            ;*  P1-5 : Connects to BOWMAN pin 106                                                           *
                            ;*  P1-6 : Connects to Docking connector pin 62                                                 *
                            ;*  P1-7 : OFF conects power to touch components (P0-1, P0-3, op amps)                          *
                            ;************************************************************************************************
                            P1:                           ;XREF[23,0]:  cdec,cdfa,cdfe,ce00,ce1a,ce1c,ce1e,ce20
                                                          ;             d84e,d850,d865,d867,d885,d887,d8a7,d8a9
                                                          ;             dc7b,dc7d,e06b,e097,e721,e773,e798
ZERO_PAGE:0002                  db          ??                                      
                            ;************************************************************************************************
                            ;*  // Port P1 Direction Register (P1D) [Address 0x03]                                          *
                            ;*  // Bit 0: Sets Port P0 mode — 0 = input, 1 = output                                         *
                            ;*  // Bits 1-7: Not allocated; cannot be read or written                                       *
                            ;************************************************************************************************
                            P1D:                          ;XREF[1,0]:   e723
ZERO_PAGE:0003                  db          ??                                      
                            ;************************************************************************************************
                            ;*  P2-0 : PSU control unsure                                                                   *
                            ;*  P2-1 : PSU control unsure                                                                   *
                            ;*  P2-2 : KB_KBCSMI                                                                            *
                            ;*  P2-3 : KB_TP139                                                                             *
                            ;*  P2-4 : N/C                                                                                  *
                            ;*  P2-5 : N/C                                                                                  *
                            ;*  P2-6 : N/C                                                                                  *
                            ;*  P2-7 : KB_SPKDN                                                                             *
                            ;************************************************************************************************
                            P2:                           ;XREF[44,0]:  c7e8,c7ef,c806,c80d,c825,c82c,c843,c84a
                                                          ;             c883,c88a,c8b0,c8b7,c8ce,c8d5,ca03,ca13
                                                          ;             ca93,ca95,caaf,cab1,cb53,cb62,cb64,cc34
                                                          ;             cc37,cc47,cc4b,cc4e,cc51,cc5b,cc61,cc64
                                                          ;             cc70,cc72,db62,db68,db82,db88,e211,e215
                                                          ;             e219,e21d,e725,e79c
ZERO_PAGE:0004                  db          ??                                      
                            ;************************************************************************************************
                            ;*  Port P2 Direction Register (P2D) [Address 0x05]                                             *
                            ;*  Each bit sets the corresponding Port P2 pin mode:                                           *
                            ;*  0 = input mode                                                                              *
                            ;*  1 = output mode                                                                             *
                            ;*  At reset, all bits are 0 (input mode)                                                       *
                            ;*  Register is write-only; contents cannot be read                                             *
                            ;************************************************************************************************
                            P2D:                          ;XREF[1,0]:   e727
ZERO_PAGE:0005                  db          ??                                      
                            ;************************************************************************************************
                            ;*  P3-0 : N/C                                                                                  *
                            ;*  P3-1 : N/C                                                                                  *
                            ;*  P3-2 : N/C                                                                                  *
                            ;*  P3-3 : N/C                                                                                  *
                            ;*  P3-4 : Dock, connects to P46 when connected, pulled up                                      *
                            ;*         Pulled down to 0 when dock barreljack powered                                        *
                            ;*  P3-5 : KB_PADLED#                                                                           *
                            ;*  P3-6 : KB_NUMLED#                                                                           *
                            ;*  P3-7 : KB_CAPLED#                                                                           *
                            ;************************************************************************************************
                            P3:                           ;XREF[4,0]:   d0a9,d1eb,d1f4,d1fd
ZERO_PAGE:0006                  db          ??                                      
ZERO_PAGE:0007                  NO_ACCESS   ??                                      
                            ;************************************************************************************************
                            ;*  P4-0 : PSU_AUX_SW1                                                                          *
                            ;*  P4-1 : BOWMAN (Touch enable active low from ASIC?)                                          *
                            ;*  P4-2 : N/C                                                                                  *
                            ;*  P4-3 : BOWMAN                                                                               *
                            ;*  P4-4 : KB_TXD                                                                               *
                            ;*  P4-5 : KB_RXD                                                                               *
                            ;*  P4-6 : Dock, connects to P34 when connected, pulled up                                      *
                            ;*         Pulled down to 0 when dock barreljack powered                                        *
                            ;*  P4-7 : N/C                                                                                  *
                            ;************************************************************************************************
                            P4:                           ;XREF[19,0]:  c9da,ccb9,cdaf,cdd2,cde0,d082,d0a5,d1b2
                                                          ;             d1b8,db9a,e2f0,e324,e37f,e38a,e392,e396
                                                          ;             e729,e7a0,e802
ZERO_PAGE:0008                  ??          ??                                      
                            ;************************************************************************************************
                            ;*  Port P4 Direction Register (P4D) [Address 0x09]                                             *
                            ;*  Each bit sets the corresponding Port P4 pin mode:                                           *
                            ;*  0 = input mode                                                                              *
                            ;*  1 = output mode                                                                             *
                            ;*  At reset, all bits are 0 (input mode)                                                       *
                            ;*  Nothing is allocated bit 0 of port P4                                                       *
                            ;*  Register is write-only; contents cannot be read                                             *
                            ;*                                                                                              *
                            ;************************************************************************************************
                            P4D:                          ;XREF[1,0]:   e72b
ZERO_PAGE:0009                  db          ??                                      
                            ;************************************************************************************************
                            ;*  P5-0 : GND                                                                                  *
                            ;*  P5-1 : PNET5                                                                                *
                            ;*  P5-2 : Something to do with the PWR_SW1                                                     *
                            ;*  P5-3 : possibly enable Jack+ sensing (P64) and some BAT                                     *
                            ;*         current sensing change (P63)                                                         *
                            ;*  P5-4 : N/C                                                                                  *
                            ;*  P5-5 : 1CLK whatever that is                                                                *
                            ;*  P5-6 : N/C                                                                                  *
                            ;*  P5-7 : signal from BOWMAN, PNET1 pullup                                                     *
                            ;************************************************************************************************
                            P5:                           ;XREF[21,0]:  ca91,caad,cc6e,cd8a,cd91,cd9d,ce0b,d0d6
                                                          ;             d0d8,d0e1,d0e3,d1d1,dab0,dab3,dab7,dab9
                                                          ;             db42,db48,e221,e225,e72d
ZERO_PAGE:000a                  db          ??                                      
                            ;************************************************************************************************
                            ;*  Port P5 Direction Register (P5D) [Address 0x0b]                                             *
                            ;*  Each bit sets the corresponding Port P5 pin mode:                                           *
                            ;*  0 = input mode                                                                              *
                            ;*  1 = output mode                                                                             *
                            ;*  At reset, all bits are 0 (input mode)                                                       *
                            ;*  Register is write-only; contents cannot be read                                             *
                            ;************************************************************************************************
                            P5D:                          ;XREF[1,0]:   e72f
ZERO_PAGE:000b                  db          ??                                      
                            ;************************************************************************************************
                            ;*  P6-0 : BAT current usage (1V = 1A)                                                          *
                            ;*  P6-1 : Sensing BAT_GND somehow                                                              *
                            ;*  P6-2 : CMOS BAT Sense (Microphone?)                                                         *
                            ;*  P6-3 : BAT charge current (cant figure out schematic)                                       *
                            ;*  P6-4 : PWR_IN_10V5 1V = 4V                                                                  *
                            ;*  P6-5 : Touch_Y measurement (Via Touch_X) 1V = 1V / 1.2                                      *
                            ;*  P6-6 : Touch_X measurement (Via Touch_Y) 1V = 1V / 1.2                                      *
                            ;*  P6-7 : Dock PWR_IN V+ (1V = 3V)                                                             *
                            ;************************************************************************************************
                            P6:                           ;XREF[1,0]:   e731
ZERO_PAGE:000c                  db          ??                                      
                            ;************************************************************************************************
                            ;*  Port P6 Direction Register (P6D) [Address 0x0d]                                             *
                            ;*  Each bit sets the corresponding Port P6 pin mode:                                           *
                            ;*  0 = input mode                                                                              *
                            ;*  1 = output mode                                                                             *
                            ;*  At reset, all bits are 0 (input mode)                                                       *
                            ;*  Register is write-only; contents cannot be read                                             *
                            ;************************************************************************************************
                            P6D:                          ;XREF[1,0]:   e733
ZERO_PAGE:000d                  db          ??                                      
                            ;************************************************************************************************
                            ;*  P7-0 : PWRGD_Shift_Buf                                                                      *
                            ;*  P7-1 : Something for PSI_AUX_SW1                                                            *
                            ;*  P7-2 : N/C                                                                                  *
                            ;*  P7-3 : N/C                                                                                  *
                            ;*  P7-4 : N/C                                                                                  *
                            ;*  P7-5 : N/C                                                                                  *
                            ;*  P7-6 : N/C                                                                                  *
                            ;*  P7-7 : N/C                                                                                  *
                            ;************************************************************************************************
                            P7:                           ;XREF[8,0]:   c9dd,cd85,cd96,cdb2,ce0e,d1b5,e735,e805
ZERO_PAGE:000e                  db          ??                                      
                            ;************************************************************************************************
                            ;*  Port P7 Direction Register (P7D) [Address 0x0f]                                             *
                            ;*  Each bit sets the corresponding Port P7 pin mode:                                           *
                            ;*  0 = input mode                                                                              *
                            ;*  1 = output mode                                                                             *
                            ;*  At reset, all bits are 0 (input mode)                                                       *
                            ;*  Nothing is allocated bit 2 to bit 7 of port P7                                              *
                            ;*  Register is write-only; contents cannot be read                                             *
                            ;************************************************************************************************
                            P7D:                          ;XREF[1,0]:   e737
ZERO_PAGE:000f                  db          ??                                      
ZERO_PAGE:0010                  NO_ACCESS   ??                                      
ZERO_PAGE:0011                  NO_ACCESS   ??                                      
ZERO_PAGE:0012                  NO_ACCESS   ??                                      
ZERO_PAGE:0013                  NO_ACCESS   ??                                      
ZERO_PAGE:0014                  NO_ACCESS   ??                                      
ZERO_PAGE:0015                  NO_ACCESS   ??                                      
                            ;************************************************************************************************
                            ;*  PULL register A (PULLA) [Address 0x16]                                                      *
                            ;*  Bits 0: Port P00–P07 pull-down enable (0: No pull-down, 1: Pull-down enabled)               *
                            ;*  Bits 1: Port P10–P17 pull-down enable (0: No pull-down, 1: Pull-down enabled)               *
                            ;*  Bits 2: Port P20–P27 pull-up enable (0: No pull-up, 1: Pull-up enabled)                     *
                            ;*  Bits 3: Port P30–P37 pull-down enable (0: No pull-down, 1: Pull-down enabled)               *
                            ;*  Bits 4: Port P70, P71 pull-up enable (0: No pull-up, 1: Pull-up enabled)                    *
                            ;*  Bits 5 to 7: Not allocated, fixed to 0 on read                                              *
                            ;*  For ports set for the output mode, pull-up or                                               *
                            ;*  pull-down is impossible.                                                                    *
                            ;************************************************************************************************
                            PULLA:                        ;XREF[1,0]:   e739
ZERO_PAGE:0016                  db          ??                                      
                            ;************************************************************************************************
                            ;*  PULL register B (PULLB) [Address 0x17]                                                      *
                            ;*  Bit 0: Port P41–P43 pull-up (0: No pull-up, 1: Pull-up enabled)                             *
                            ;*  Bit 1: Port P44–P47 pull-up (0: No pull-up, 1: Pull-up enabled)                             *
                            ;*  Bit 2: Port P50–P53 pull-up (0: No pull-up, 1: Pull-up enabled)                             *
                            ;*  Bit 3: Port P54–P57 pull-up (0: No pull-up, 1: Pull-up enabled)                             *
                            ;*  Bit 4: Port P60–P63 pull-up (0: No pull-up, 1: Pull-up enabled)                             *
                            ;*  Bit 5: Port P64–P67 pull-up (0: No pull-up, 1: Pull-up enabled)                             *
                            ;*  Bits 6, 7: Not allocated, fixed to 0 on read                                                *
                            ;*  For ports set for the output mode, pull-up is impossible.                                   *
                            ;************************************************************************************************
                            PULLB:                        ;XREF[1,0]:   e73b
ZERO_PAGE:0017                  db          ??                                      
                            ;************************************************************************************************
                            ;*  // Bit fields for TB/RB (Transmit/Receive Buffer Register)                                  *
                            ;*  b0–b7: Transmit/Receive data byte                                                           *
                            ;*  // Write to transmit, read from receive buffer                                              *
                            ;*                                                                                              *
                            ;************************************************************************************************
                            TB/RB:                        ;XREF[2,0]:   e2c2,e2d6
ZERO_PAGE:0018                  char        ??                                      
                            ;************************************************************************************************
                            ;*  // Bit fields for SIOSTS (Serial I/O Status Register)                                       *
                            ;*  b0: Transmit buffer empty flag (TBE)                                                        *
                            ;*  b1: Receive buffer full flag (RBF)                                                          *
                            ;*  b2: Transmit shift register shift completion flag (TSC)                                     *
                            ;*  b3: Overrun error flag (OE)                                                                 *
                            ;*  b4: Parity error flag (PE)                                                                  *
                            ;*  b5: Framing error flag (FE)                                                                 *
                            ;*  b6: Summing error flag (SE) — (OE) ∪ (PE) ∪ (FE)                                            *
                            ;*  b7: Reserved — fixed to 1 when read, cannot be written                                      *
                            ;************************************************************************************************
                            SIO1STS:                      ;XREF[8,0]:   d97b,d97e,d981,d984,d98f,d991,d993,d995
ZERO_PAGE:0019                  db          ??                                      
                            ;************************************************************************************************
                            ;*  // Bit fields for SIOCON (Serial I/O Control Register)                                      *
                            ;*  b0: BRG count source selection bit (CSS)                                                    *
                            ;*  // 0: f(XIN), 1: f(XIN)/4                                                                   *
                            ;*  b1: Serial I/O synchronization clock selection bit (SCS)                                    *
                            ;*  // Selects internal or external clock                                                       *
                            ;*  b2: SRDY output enable bit (SRDY)                                                           *
                            ;*  // 1: Enable SRDY signal on P47                                                             *
                            ;*  b3: Transmit interrupt source selection bit (TIC)                                           *
                            ;*  // 0: On buffer empty, 1: On shift complete                                                 *
                            ;*  b4: Transmit enable bit (TE)                                                                *
                            ;*  // 1: Enable transmit                                                                       *
                            ;*  b5: Receive enable bit (RE)                                                                 *
                            ;*  // 1: Enable receive                                                                        *
                            ;*  b6: Serial I/O mode selection bit (SIOM)                                                    *
                            ;*  // 0: UART mode, 1: Clock synchronous mode                                                  *
                            ;*  b7: Serial I/O enable bit (SIOE)                                                            *
                            ;*  // 1: Enable Serial I/O (P44–P47 as I/O)                                                    *
                            ;*                                                                                              *
                            ;************************************************************************************************
                            SIO1CON:                      ;XREF[8,0]:   d989,d98b,d98d,d997,d999,d99b,e73d,e790
ZERO_PAGE:001a                  db          ??                                      
                            ;************************************************************************************************
                            ;*  // Bit fields for UART Control Register (UARTCON)                                           *
                            ;*  b0: CHAS  – Character length selection bit                                                  *
                            ;*  // 0 = 8 bits, 1 = 7 bits                                                                   *
                            ;*  b1: PARE  – Parity enable bit                                                               *
                            ;*  // 0 = Disabled, 1 = Enabled                                                                *
                            ;*  b2: PARS  – Parity selection bit                                                            *
                            ;*  // 0 = Even, 1 = Odd                                                                        *
                            ;*  b3: STPS  – Stop bit length selection bit                                                   *
                            ;*  // 0 = 1 stop bit, 1 = 2 stop bits                                                          *
                            ;*  b4: POFF  – P45/TxD P-channel output disable bit                                            *
                            ;*  // 0 = CMOS output, 1 = Open-drain output                                                   *
                            ;*  b5–b7: Reserved/fixed                                                                       *
                            ;*  // Always read as 1, cannot be written                                                      *
                            ;*                                                                                              *
                            ;************************************************************************************************
                            UARTCON:                      ;XREF[1,0]:   e73f
ZERO_PAGE:001b                  db          ??                                      
                            ;************************************************************************************************
                            ;*  Baud rate calculation:                                                                      *
                            ;*  Baud rate =                                                                                 *
                            ;*  	XIN input frequency /                                                                      *
                            ;*  	(Division ratio * (BRG value + 1) * 4)                                                     *
                            ;*                                                                                              *
                            ;*  Division ratio can be 1 or 4.                                                               *
                            ;*  BRG value ranges from 0 to 255.                                                             *
                            ;************************************************************************************************
                            BRG:                          ;XREF[1,0]:   e741
ZERO_PAGE:001c                  db          ??                                      
ZERO_PAGE:001d                  NO_ACCESS   ??                                      
ZERO_PAGE:001e                  NO_ACCESS   ??                                      
ZERO_PAGE:001f                  NO_ACCESS   ??                                      
                            ;************************************************************************************************
                            ;*  Timer X (TXH:TXL) is a 16-bit down counter (0x21–0x20).                                     *
                            ;*  Decrements by 1 with each count input.                                                      *
                            ;*  Must write TXL before TXH when setting value.                                               *
                            ;*  Must read TXH before TXL when reading value.                                                *
                            ;*  If write control bit is 0, TXH and TXL are latched together.                                *
                            ;*  Default reset value is 0x01.                                                                *
                            ;*                                                                                              *
                            ;************************************************************************************************
                            TXL:                          ;XREF[1,0]:   daf4
ZERO_PAGE:0020                  db          ??                                      
                            ;************************************************************************************************
                            ;*  Timer X (TXH:TXL) is a 16-bit down counter (0x21–0x20).                                     *
                            ;*  Decrements by 1 with each count input.                                                      *
                            ;*  Must write TXL before TXH when setting value.                                               *
                            ;*  Must read TXH before TXL when reading value.                                                *
                            ;*  If write control bit is 0, TXH and TXL are latched together.                                *
                            ;*  Default reset value is 0x01.                                                                *
                            ;*                                                                                              *
                            ;************************************************************************************************
                            TXH:                          ;XREF[3,0]:   db05,db10,db17
ZERO_PAGE:0021                  db          ??                                      
                            ;************************************************************************************************
                            ;*  Timer Y (TYH:TYL) is a 16-bit down counter (0x23–0x22).                                     *
                            ;*  Decrements by 1 with each count input.                                                      *
                            ;*  Must write TYL before TYH when setting value.                                               *
                            ;*  Must read TYH before TYL when reading value.                                                *
                            ;*  If write control bit is 0, TXH and TXL are latched together.                                *
                            ;*  Default reset value is 0x01.                                                                *
                            ;*                                                                                              *
                            ;************************************************************************************************
                            TYL:                          ;XREF[3,0]:   e747,e77b,e7a8
ZERO_PAGE:0022                  db          ??                                      
                            ;************************************************************************************************
                            ;*  Timer Y (TYH:TYL) is a 16-bit down counter (0x23–0x22).                                     *
                            ;*  Decrements by 1 with each count input.                                                      *
                            ;*  Must write TYL before TYH when setting value.                                               *
                            ;*  Must read TYH before TYL when reading value.                                                *
                            ;*  If write control bit is 0, TXH and TXL are latched together.                                *
                            ;*  Default reset value is 0x01.                                                                *
                            ;*                                                                                              *
                            ;************************************************************************************************
                            TYH:                          ;XREF[3,0]:   e749,e77f,e7ac
ZERO_PAGE:0023                  db          ??                                      
                            ;************************************************************************************************
                            ;*  // Timer 1 and Timer 3 latch register (T1, T3) [Addr 0x24, 0x26]                            *
                            ;*  // - Set timer count values from 0x0016 to 0xFF16.                                          *
                            ;*  // - Values written are latched and auto-loaded into the counters upon underflow.           *
                            ;*  // - Write-only register; not readable.                                                     *
                            ;*  // - Reset default is 0x01.                                                                 *
                            ;*                                                                                              *
                            ;************************************************************************************************
                            T1:                           
ZERO_PAGE:0024                  db          ??                                      
                            ;************************************************************************************************
                            ;*  Timer 2 latch register (T2) [Address 0x25]                                                  *
                            ;*  Set count value between 0x0016 and 0xFF16.                                                  *
                            ;*  Value is written to latch and auto-loaded into Timer 2 on underflow.                        *
                            ;*  Only bit 0 is used; bits 1–7 are unused.                                                    *
                            ;*  Write-only register; not readable.                                                          *
                            ;*  Reset value: bit 0 = 1, bits 1–7 = 0.                                                       *
                            ;************************************************************************************************
                            T2:                           ;XREF[3,0]:   e2f8,e320,e74d
ZERO_PAGE:0025                  db          ??                                      
                            ;************************************************************************************************
                            ;*  // Timer 1 and Timer 3 latch register (T1, T3) [Addr 0x24, 0x26]                            *
                            ;*  // - Set timer count values from 0x0016 to 0xFF16.                                          *
                            ;*  // - Values written are latched and auto-loaded into the counters upon underflow.           *
                            ;*  // - Write-only register; not readable.                                                     *
                            ;*  // - Reset default is 0x01.                                                                 *
                            ;*                                                                                              *
                            ;************************************************************************************************
                            T3:                           ;XREF[1,0]:   e74f
ZERO_PAGE:0026                  db          ??                                      
                            ;************************************************************************************************
                            ;*  Timer X Mode Register (TXM) [Address 0x27]                                                  *
                            ;*                                                                                              *
                            ;*  b0: Timer X write control bit                                                               *
                            ;*      0 = Write value to latch and counter                                                    *
                            ;*      1 = Write value to latch only                                                           *
                            ;*  b1: Real-time port control                                                                  *
                            ;*      0 = Real-time port invalid                                                              *
                            ;*      1 = Real-time port valid                                                                *
                            ;*  b2: RTP0 data output (real-time port 0)                                                     *
                            ;*      0 = "L" level output                                                                    *
                            ;*      1 = "H" level output                                                                    *
                            ;*  b3: RTP1 data output (real-time port 1)                                                     *
                            ;*      0 = "L" level output                                                                    *
                            ;*      1 = "H" level output                                                                    *
                            ;*  b4–b5: Timer X operating mode                                                               *
                            ;*      00 = Timer mode                                                                         *
                            ;*      01 = Pulse output mode                                                                  *
                            ;*      10 = Event counter mode                                                                 *
                            ;*      11 = Pulse width measurement mode                                                       *
                            ;*  b6: CNTR0 active edge switch bit                                                            *
                            ;*      - CNTR0 interrupt: 0 = falling edge, 1 = rising edge                                    *
                            ;*      - Pulse output mode: 0 = start at "H", 1 = start at "L"                                 *
                            ;*      - Event counter: 0 = rising edge, 1 = falling edge                                      *
                            ;*      - Pulse width measurement: 0 = measure "H" width, 1 = measure "L" width                 *
                            ;*  b7: Timer X stop control bit                                                                *
                            ;*      0 = Count start                                                                         *
                            ;*      1 = Count stop                                                                          *
                            ;*                                                                                              *
                            ;************************************************************************************************
                            TXM:                          ;XREF[6,0]:   db0c,db13,db1f,e743,e777,e7a4
ZERO_PAGE:0027                  db          ??                                      
                            ;************************************************************************************************
                            ;*  Timer Y Mode Register (TYM) [Address 0x28]                                                  *
                            ;*                                                                                              *
                            ;*  b0–b3: Reserved (fixed to 0, cannot be written)                                             *
                            ;*  b4–b5: Timer Y operating mode                                                               *
                            ;*      00: Timer mode                                                                          *
                            ;*      01: Period measurement mode                                                             *
                            ;*      10: Event counter mode                                                                  *
                            ;*      11: Pulse width HL continuously measurement mode                                        *
                            ;*                                                                                              *
                            ;*  b6: CNTR1 active edge switch bit                                                            *
                            ;*      - In CNTR1 interrupt: 0 = falling edge, 1 = rising edge                                 *
                            ;*      - In period measurement: 0 = fall→fall, 1 = rise→rise                                   *
                            ;*      - In event counter: 0 = rising edge, 1 = falling edge                                   *
                            ;*                                                                                              *
                            ;*  b7: Timer Y stop control bit                                                                *
                            ;*      0 = Count start                                                                         *
                            ;*      1 = Count stop                                                                          *
                            ;************************************************************************************************
                            TYM:                          ;XREF[1,0]:   e745
ZERO_PAGE:0028                  db          ??                                      
                            ;************************************************************************************************
                            ;*  Timer 123 Mode Register (T123M) [Address 0x29]                                              *
                            ;*  b0: Timer 2 TOUT start edge                                                                 *
                            ;*  	(0: start HIGH, 1: start LOW)                                                              *
                            ;*  b1: Timer 2 TOUT enable                                                                     *
                            ;*  	(0: disabled, 1: enabled)                                                                  *
                            ;*  b2: Timer 2 write control                                                                   *
                            ;*  	(0: write to latch & counter, 1: latch only)                                               *
                            ;*  b3: Timer 2 count source                                                                    *
                            ;*  	(0: Timer 1 underflow, 1: f(XIN)/16 or f(XCIN)/16)                                         *
                            ;*  b4: Timer 3 count source                                                                    *
                            ;*  	(0: Timer 1 underflow, 1: f(XIN)/16 or f(XCIN)/16)                                         *
                            ;*  b5: Timer 1 count source                                                                    *
                            ;*  	(0: f(XIN)/16 or f(XCIN)/16, 1: f(XCIN))                                                   *
                            ;*  b6–b7: Reserved                                                                             *
                            ;*  	(read as 0, cannot be written)                                                             *
                            ;*  Note: In low-speed mode, internal clock = f(XCIN)/2                                         *
                            ;************************************************************************************************
                            T123M:                        ;XREF[1,0]:   e74b
ZERO_PAGE:0029                  db          ??                                      
                            ;************************************************************************************************
                            ;*  ϕ Output Control Register (CKOUT) [Address 0x2A]                                            *
                            ;*                                                                                              *
                            ;*  b0: ϕ output control bit                                                                    *
                            ;*      0 = Normal port function                                                                *
                            ;*      1 = ϕ clock output (only if port direction register = 1)                                *
                            ;*                                                                                              *
                            ;*  b1–b7: Reserved (fixed to 0, cannot be written)                                             *
                            ;*  Reset value = 0x00                                                                          *
                            ;*                                                                                              *
                            ;************************************************************************************************
                            CKOUT:                        ;XREF[1,0]:   e751
ZERO_PAGE:002a                  db          ??                                      
ZERO_PAGE:002b                  NO_ACCESS   ??                                      
ZERO_PAGE:002c                  NO_ACCESS   ??                                      
ZERO_PAGE:002d                  NO_ACCESS   ??                                      
ZERO_PAGE:002e                  NO_ACCESS   ??                                      
ZERO_PAGE:002f                  NO_ACCESS   ??                                      
ZERO_PAGE:0030                  NO_ACCESS   ??                                      
ZERO_PAGE:0031                  NO_ACCESS   ??                                      
ZERO_PAGE:0032                  NO_ACCESS   ??                                      
ZERO_PAGE:0033                  NO_ACCESS   ??                                      
                            ;************************************************************************************************
                            ;*  A-D Control Register (ADCON) [Address 0x34]                                                 *
                            ;*                                                                                              *
                            ;*  b0–b2: Analog input pin selection bits                                                      *
                            ;*      000 = AN0, 001 = AN1, ..., 111 = AN7                                                    *
                            ;*                                                                                              *
                            ;*  b3: A-D conversion completion bit                                                           *
                            ;*      0 = Conversion in progress                                                              *
                            ;*      1 = Conversion completed                                                                *
                            ;*      Note: Must be cleared to "0" to start conversion                                        *
                            ;*            (when using internal trigger)                                                     *
                            ;*                                                                                              *
                            ;*  b4: VREF input switch                                                                       *
                            ;*      0 = VREF OFF                                                                            *
                            ;*      1 = VREF ON                                                                             *
                            ;*                                                                                              *
                            ;*  b5: A-D external trigger valid bit                                                          *
                            ;*      0 = Internal trigger (bit 3 used to start conversion)                                   *
                            ;*      1 = External trigger enabled                                                            *
                            ;*                                                                                              *
                            ;*  b6: Interrupt source selection                                                              *
                            ;*      0 = Interrupt on conversion complete                                                    *
                            ;*      1 = Interrupt on falling edge of ADT pin                                                *
                            ;*                                                                                              *
                            ;*  b7: Reserved (fixed to 0, cannot be written)                                                *
                            ;*                                                                                              *
                            ;*  Note:                                                                                       *
                            ;*  When an internal trigger is selected, A-D conversion                                        *
                            ;*  is started by setting bit 3 to “0.” Writing only “0”                                        *
                            ;*  to bit 3 is valid. Even if “1” is written to bit 3,                                         *
                            ;*  it is not set to “0.” Accordingly, to write values to                                       *
                            ;*  the ADCON without affecting bit 3,                                                          *
                            ;*  set bit 3 to “1.”                                                                           *
                            ;************************************************************************************************
                            ADCON:                        ;XREF[8,0]:   c0d5,c137,d634,d726,d7cf,d8f4,d8fc,e753
ZERO_PAGE:0034                  db          ??                                      
                            AD:                           ;XREF[11,0]:  d67d,d6a2,d6ae,d6c9,d6fd,d72e,d737,d87a
                                                          ;             d88f,d89a,d8b1
ZERO_PAGE:0035                  db          ??                                      
ZERO_PAGE:0036                  NO_ACCESS   ??                                      
ZERO_PAGE:0037                  NO_ACCESS   ??                                      
                            SEG:                          ;XREF[1,0]:   e755
ZERO_PAGE:0038                  db          ??                                      
                            LM:                           ;XREF[6,0]:   d133,d1bb,d1bf,d1c3,d1c9,e757
ZERO_PAGE:0039                  db          ??                                      
                            ;************************************************************************************************
                            ;*  // Bit fields for INTEDGE (Interrupt Edge Selection Register)                               *
                            ;*  b0: INT0 interrupt edge selection bit (0 = Falling edge, 1 = Rising edge)                   *
                            ;*  b1: INT1 interrupt edge selection bit (0 = Falling edge, 1 = Rising edge)                   *
                            ;*  b2: INT2 interrupt edge selection bit (0 = Falling edge, 1 = Rising edge)                   *
                            ;*  b3: INT3 interrupt edge selection bit (0 = Falling edge, 1 = Rising edge)                   *
                            ;*  b4: Reserved (always reads as 0, cannot be written)                                         *
                            ;*  b5: Reserved (always reads as 0, cannot be written)                                         *
                            ;*  b6: Reserved (always reads as 0, cannot be written)                                         *
                            ;*  b7: Reserved (always reads as 0, cannot be written)                                         *
                            ;*                                                                                              *
                            ;************************************************************************************************
                            INTEDGE:                      ;XREF[1,0]:   e759
ZERO_PAGE:003a                  db          ??                                      
                            ;************************************************************************************************
                            ;*  CPU Mode Register (CPUM) [Address 0x3B]                                                     *
                            ;*                                                                                              *
                            ;*  b0–b1: Processor mode bits                                                                  *
                            ;*      00 = Single-chip mode                                                                   *
                            ;*      01 = Not available                                                                      *
                            ;*      10/11 = Reserved (Do not use)                                                           *
                            ;*                                                                                              *
                            ;*  b2: Stack page selection bit                                                                *
                            ;*      0 = 0 page                                                                              *
                            ;*      1 = 1 page                                                                              *
                            ;*                                                                                              *
                            ;*  b3: Fixed to 1 (must always be written as 1)                                                *
                            ;*                                                                                              *
                            ;*  b4: Port Xc switch bit                                                                      *
                            ;*      0 = I/O port                                                                            *
                            ;*      1 = XcIN, XcOUT (external clock I/O)                                                    *
                            ;*                                                                                              *
                            ;*  b5: Main clock (XIN–XOUT) stop bit                                                          *
                            ;*      0 = Oscillating                                                                         *
                            ;*      1 = Stopped                                                                             *
                            ;*                                                                                              *
                            ;*  b6: Main clock division ratio selection                                                     *
                            ;*      0 = f(XIN)/2 (high-speed mode)                                                          *
                            ;*      1 = f(XIN)/8 (middle-speed mode)                                                        *
                            ;*                                                                                              *
                            ;*  b7: Internal system clock source selection                                                  *
                            ;*      0 = XIN–XOUT selected (middle/high-speed)                                               *
                            ;*      1 = XCIN–XCOUT selected (low-speed mode)                                                *
                            ;************************************************************************************************
                            CPUM:                         ;XREF[3,0]:   e75b,e783,e7b0
ZERO_PAGE:003b                  db          ??                                      
                            ;************************************************************************************************
                            ;*  // Bit fields for IREQ1 (Interrupt Request Register 1)                                      *
                            ;*  b0: INT0 interrupt request bit                                                              *
                            ;*  b1: INT1 interrupt request bit                                                              *
                            ;*  b2: Serial I/O receive interrupt request bit                                                *
                            ;*  b3: Serial I/O transmit interrupt request bit                                               *
                            ;*  b4: Timer X interrupt request bit                                                           *
                            ;*  b5: Timer Y interrupt request bit                                                           *
                            ;*  b6: Timer 2 interrupt request bit                                                           *
                            ;*  b7: Timer 3 interrupt request bit                                                           *
                            ;************************************************************************************************
                            IREQ1:                        ;XREF[21,0]:  ce16,d168,d195,dbfa,dd59,e067,e2cc,e2fd
                                                          ;             e314,e33c,e358,e761,e85d,e85f,e861,e88e
                                                          ;             e890,e892,e8f2,e8f4,e8f6
ZERO_PAGE:003c                  db          ??                                      
                            ;************************************************************************************************
                            ;*  // Bit fields for IREQ2 (Interrupt Request Register 2)                                      *
                            ;*  b0: CNTR0 interrupt request bit                                                             *
                            ;*  b1: CNTR1 interrupt request bit                                                             *
                            ;*  b2: Timer 1 interrupt request bit                                                           *
                            ;*  b3: INT2 interrupt request bit                                                              *
                            ;*  b4: INT3 interrupt request bit                                                              *
                            ;*  b5: Key input interrupt request bit                                                         *
                            ;*  b6: ADT/A-D conversion interrupt request bit                                                *
                            ;*  b7: Nothing is allocated (bit always reads as 0, cannot be written)                         *
                            ;************************************************************************************************
                            IREQ2:                        ;XREF[7,0]:   d11f,d12d,d16b,d198,d7d1,e310,e763
ZERO_PAGE:003d                  db          ??                                      
                            ;************************************************************************************************
                            ;*  // Bit fields for ICON1 (Interrupt Control Register 1)                                      *
                            ;*  b0: INTo interrupt enable bit                                                               *
                            ;*  b1: INT1 interrupt enable bit                                                               *
                            ;*  b2: Serial I/O receive interrupt enable bit                                                 *
                            ;*  b3: Serial I/O transmit interrupt enable bit                                                *
                            ;*  b4: Timer X interrupt enable bit                                                            *
                            ;*  b5: Timer Y interrupt enable bit                                                            *
                            ;*  b6: Timer 2 interrupt enable bit                                                            *
                            ;*  b7: Timer 3 interrupt enable bit                                                            *
                            ;************************************************************************************************
                            ICON1:                        ;XREF[18,0]:  cdfc,ce18,d162,d188,dbfc,dd5b,e069,e0a5
                                                          ;             e2ca,e2ff,e316,e33e,e35a,e360,e379,e75d
                                                          ;             e767,e788
ZERO_PAGE:003e                  db          ??                                      
                            ;************************************************************************************************
                            ;*  // Bit fields for ICON2 (Interrupt Control Register 2)                                      *
                            ;*  b0: CNTR0 interrupt enable bit                                                              *
                            ;*  b1: CNTR1 interrupt enable bit                                                              *
                            ;*  b2: Timer 1 interrupt enable bit                                                            *
                            ;*  b3: INT2 interrupt enable bit                                                               *
                            ;*  b4: INT3 interrupt enable bit                                                               *
                            ;*  b5: Key input interrupt enable bit                                                          *
                            ;*  b6: ADT/A-D conversion interrupt enable bit                                                 *
                            ;*  b7: Fixed to 0 (do not modify)                                                              *
                            ;************************************************************************************************
                            ICON2:                        ;XREF[14,0]:  d11c,d165,d16e,d170,d17c,d186,d19b,d19d
                                                          ;             d19f,e2f6,e312,e75f,e76b,e78c
ZERO_PAGE:003f                  db          ??                                      
                            ;************************************************************************************************
                            ;*                             0x40 to 0x4F = LCD display RAM Area                              *
                            ;************************************************************************************************
                            SEG0/1:                       ;XREF[8,0]:   d2b0,d36b,d3bb,d3cd,d40e,d578,e031,e6e3
ZERO_PAGE:0040                  db          ??                                      
                            SEG3/2:                       ;XREF[15,0]:  d26c,d2c7,d2ca,d2cc,d2d0,d380,d386,d3dc
                                                          ;             d41d,d57a,e01a,e01e,e039,e03d,e6e3
ZERO_PAGE:0041                  db          ??                                      
                            SEG5/4:                       ;XREF[6,0]:   d2e3,d3af,d3ed,d421,d57c,e045
ZERO_PAGE:0042                  db          ??                                      
                            SEG7/6:                       ;XREF[10,0]:  d2f4,d3b5,d3b7,d3fc,d42e,d57e,e011,e015
                                                          ;             e04d,e051
ZERO_PAGE:0043                  db          ??                                      
                            SEG9/8:                       ;XREF[56,0]:  d1d7,d1d9,d1db,d1ee,d1f2,d1f7,d1fb,d200
                                                          ;             d204,d212,d223,d227,d22c,d22f,d231,d235
                                                          ;             d237,d23e,d242,d247,d250,d254,d4e8,d4f9
                                                          ;             d50a,d51b,d52c,d52f,d547,d54a,d553,d555
                                                          ;             d557,d55a,d55c,d55e,d561,d563,d565,d568
                                                          ;             d56a,d56c,d56f,d571,d573,d596,dfde,dfe2
                                                          ;             dfe7,dfeb,dff0,dff4,dffc,e000,e005,e009
ZERO_PAGE:0044                  db          ??                                      
                            SEG11/10:                     
ZERO_PAGE:0045                  db          ??                                      
                            SEG13/12:                     
ZERO_PAGE:0046                  db          ??                                      
                            SEG15/14:                     
ZERO_PAGE:0047                  db          ??                                      
                            SEG17/16:                     
ZERO_PAGE:0048                  db          ??                                      
                            SEG19/18:                     
ZERO_PAGE:0049                  db          ??                                      
                            SEG21/20:                     
ZERO_PAGE:004a                  db          ??                                      
                            SEG23/22:                     
ZERO_PAGE:004b                  db          ??                                      
                            SEG25/24:                     
ZERO_PAGE:004c                  db          ??                                      
                            SEG27/26:                     
ZERO_PAGE:004d                  db          ??                                      
                            SEG29/28:                     
ZERO_PAGE:004e                  db          ??                                      
                            SEG31/30:                     
ZERO_PAGE:004f                  db          ??                                      
                            ;************************************************************************************************
                            ;*                                     0x50 to 0x23F is RAM                                     *
                            ;************************************************************************************************
                            RunningMode:                  ;XREF[46,0]:  c1df,c1e4,c26e,c383,c602,c61d,c620,c63e
                                                          ;             c641,c775,c77b,c8e5,c8ea,c9d1,c9fd,ca35
                                                          ;             ca40,cd77,cd7a,cd7d,ce08,ce95,cea5,ceb5
                                                          ;             d130,d139,d1af,d1d4,d20f,d21d,d220,d269
                                                          ;             d2fc,d4b5,d4db,d8f6,d978,daad,dce6,dce9
                                                          ;             dcec,e7f6,e830,e843,e877,e8b0
ZERO_PAGE:0050                  GlobalPw...??                                      
                            DAT_0051:                     ;XREF[8,0]:   c0e7,c113,c124,c149,c156,c17b,c18d,c19b
ZERO_PAGE:0051                  undefined1  ??                                      
ZERO_PAGE:0052                  ??          ??                                      
ZERO_PAGE:0053                  undefined1  ??                                      
ZERO_PAGE:0054                  ??          ??                                      
ZERO_PAGE:0055                  ??          ??                                      
ZERO_PAGE:0056                  ??          ??                                      
ZERO_PAGE:0057                  ??          ??                                      
ZERO_PAGE:0058                  undefined1  ??                                      
ZERO_PAGE:0059                  ??          ??                                      
                            DAT_005a:                     ;XREF[4,0]:   c2b8,c2bd,c372,c377
ZERO_PAGE:005a                  undefined1  ??                                      
                            DAT_005b:                     ;XREF[2,0]:   c309,ccf4
ZERO_PAGE:005b                  ??          ??                                      
                            DAT_005c:                     ;XREF[11,0]:  c2db,c2df,c2f5,c2f7,c30e,c3e1,c3e3,c3e9
                                                          ;             c3fc,c400,ccf7
ZERO_PAGE:005c                  undefined1  ??                                      
                            uint16_t_005d:                ;XREF[6,4]:   c22b,c23b,c24b,c25b,d6d3,d6ea,c22e,c23e
                                                          ;             c24e,c25e
ZERO_PAGE:005d                  uint16_t    ??                                      
                            uint16_t_005f:                ;XREF[7,4]:   c231,c241,c251,c261,d6ba,d6e3,d77f,c234
                                                          ;             c244,c254,c264
ZERO_PAGE:005f                  uint16_t    ??                                      
                            DAT_0061:                     ;XREF[6,0]:   c237,c247,c257,c267,d70d,d7ac
ZERO_PAGE:0061                  undefined1  ??                                      
                            DAT_0062:                     ;XREF[3,0]:   c399,cd03,d75a
ZERO_PAGE:0062                  undefined1  ??                                      
                            DAT_0063:                     ;XREF[3,0]:   c39d,cd06,d75d
ZERO_PAGE:0063                  undefined1  ??                                      
                            DAT_0064:                     ;XREF[2,0]:   cd09,d760
ZERO_PAGE:0064                  undefined1  ??                                      
                            uint24_t_0065:                ;XREF[5,7]:   c280,c356,cd0d,d6ac,d763,c298,c29a,c29f
                                                          ;             cd10,cd13,d766,d769
ZERO_PAGE:0065                  uint24_t                                            
   |_ZERO_PAGE:0065  field0_0x0      ??          ??                                      
   |_ZERO_PAGE:0066  field1_0x1      ??          ??                                      
   |_ZERO_PAGE:0067  field2_0x2      ??          ??                                      
                            DAT_0068:                     ;XREF[3,0]:   c3af,ccfc,d76c
ZERO_PAGE:0068                  undefined1  ??                                      
                            DAT_0069:                     ;XREF[3,0]:   c3b3,ccff,d76f
ZERO_PAGE:0069                  undefined1  ??                                      
                            DAT_006a:                     ;XREF[4,0]:   c497,cfe9,d002,d6ff
ZERO_PAGE:006a                  undefined1  ??                                      
                            DAT_006b:                     ;XREF[3,0]:   c495,cfe7,d6b0
ZERO_PAGE:006b                  undefined1  ??                                      
                            DAT_006c:                     ;XREF[37,0]:  c187,c1e9,c26b,c3d4,c7a5,ca43,ca4a,ca8d
                                                          ;             ca8f,caa9,caab,cb34,cba4,cc16,cc5e,cc6c
                                                          ;             ccaf,ccb1,cce5,cce9,ce53,ce56,ce82,d052
                                                          ;             d217,d21a,d229,d23b,d244,d311,d320,d423
                                                          ;             d7d4,dd00,ddf7,ddfd,e3e6
ZERO_PAGE:006c                  undefined1  ??                                      
                            ;************************************************************************************************
                            ;*                        DAT_006d bit 0 high indicates dock mains power                        *
                            ;************************************************************************************************
                            DAT_006d:                     ;XREF[44,0]:  c1fe,c282,c2af,c36f,c490,c5fc,c61a,c63b
                                                          ;             c76f,c7f3,c7fa,c811,c818,c830,c837,c83a
                                                          ;             c84e,c855,c87a,c88e,c895,c8bb,c8c2,c8d9
                                                          ;             c8e0,c8ef,c974,c9d7,ca00,ca4c,cadf,cdbb
                                                          ;             cdc1,cdca,cdd0,cfe2,d0de,d136,d2ff,d302
                                                          ;             d355,dd0e,e808,e840
ZERO_PAGE:006d                  undefined1  ??                                      
                            ModeControlFlags:             ;XREF[26,0]:  c2f9,c2fe,c3ed,c4ae,c4d8,c4e1,c4ea,c60b
                                                          ;             c614,ca57,cb56,cc03,cc86,cc90,cc98,ccb3
                                                          ;             ccc3,ccd5,ccd9,ccdd,ccee,d0f8,d314,d33f
                                                          ;             dd17,de05
ZERO_PAGE:006e                  undefined1  ??                                      
                            DAT_006f:                     ;XREF[4,0]:   cc88,ccb6,cccf,ccf1
ZERO_PAGE:006f                  ??          ??                                      
                            DAT_0070:                     ;XREF[19,0]:  c2a1,c2b2,c2cc,c358,c366,c3ca,cace,cb13
                                                          ;             cb29,cb5c,cb70,cc09,cc41,cc55,d3de,d3ef
                                                          ;             dd25,e592,e5a8
ZERO_PAGE:0070                  undefined1  ??                                      
                            DAT_0071:                     ;XREF[18,0]:  c3c2,c4ba,c4f1,c60d,c97e,ca4f,caf2,cafa
                                                          ;             cb45,cb86,cbb4,cbe0,d075,d3be,d3cf,d701
                                                          ;             d706,dd29
ZERO_PAGE:0071                  undefined1  ??                                      
                            DAT_0072:                     ;XREF[11,0]:  ca63,cae2,caea,cbfd,d3ff,d410,d6a4,dd37
                                                          ;             e3c5,e3f6,e524
ZERO_PAGE:0072                  undefined1  ??                                      
                            DAT_0073:                     ;XREF[9,0]:   ca46,cb2f,cb9b,cba6,cbd2,cc23,ce4a,ce51
                                                          ;             da3b
ZERO_PAGE:0073                  undefined1  ??                                      
                            ADC_tracked_max:              ;XREF[3,0]:   cf0a,d830,d834
ZERO_PAGE:0074                  undefined1  ??                                      
                            ADC_tracked_max:              ;XREF[3,0]:   cf13,d837,d83b
ZERO_PAGE:0075                  undefined1  ??                                      
                            DAT_0076:                     ;XREF[4,0]:   cf1d,d80a,d810,d814
ZERO_PAGE:0076                  undefined1  ??                                      
                            DAT_0077:                     ;XREF[4,0]:   cf20,d804,d812,d817
ZERO_PAGE:0077                  undefined1  ??                                      
                            DAT_0078:                     ;XREF[4,0]:   cf23,d820,d826,d82a
ZERO_PAGE:0078                  undefined1  ??                                      
                            DAT_0079:                     ;XREF[4,0]:   cf26,d81a,d828,d82d
ZERO_PAGE:0079                  undefined1  ??                                      
                            BatV+_max:                    ;XREF[4,0]:   cf0d,d7de,d7e4,d7e8
ZERO_PAGE:007a                  undefined1  ??                                      
                            BatV+_prevMax:                ;XREF[4,0]:   cf10,d7d8,d7e6,d7eb
ZERO_PAGE:007b                  undefined1  ??                                      
                            BatV+_min:                    ;XREF[4,0]:   cf16,d7f4,d7fa,d7fe
ZERO_PAGE:007c                  undefined1  ??                                      
                            BatV+_prevMin:                ;XREF[4,0]:   cf19,d7ee,d7fc,d801
ZERO_PAGE:007d                  undefined1  ??                                      
                            DAT_007e:                     ;XREF[1,0]:   c11f
ZERO_PAGE:007e                  ??          ??                                      
ZERO_PAGE:007f                  undefined1  ??                                      
                            ADC_State:                    ;XREF[42,0]:  c0e5,c147,c1b7,c1ba,c1bd,c1c0,d654,d657
                                                          ;             d65a,d6d8,d6db,d6e1,d70f,d712,d718,d74e
                                                          ;             d751,d754,d758,d841,d856,d8ee,d8fe,d94f
                                                          ;             d955,d958,d95a,e84d,e84f,e851,e853,e855
                                                          ;             e881,e883,e885,e887,e889,e8ca,e8e7,e8e9
                                                          ;             e8eb,e8ed
ZERO_PAGE:0080                  undefined1  ??                                      
                            ADC_Global_State_Var:         ;XREF[38,0]:  c1c3,c1c6,c1c9,c1cc,c1cf,c1d2,d623,d627
                                                          ;             d62a,d630,d651,d668,d66b,d671,d674,d677
                                                          ;             d67f,d6a0,d6aa,d6c5,d6fb,d724,d74a,d777
                                                          ;             d788,d79a,d7a3,d7b2,d7bb,d7c4,d844,d858
                                                          ;             d86d,d88d,d8af,e857,e88b,e8ef
ZERO_PAGE:0081                  ADC_Glob...                                        
   |_ZERO_PAGE:0081  BAT_DISCH...    bool:1      ??                                      
   |_ZERO_PAGE:0081  BAT_CHARG...    bool:1      ??                                      
   |_ZERO_PAGE:0081  CMOS_BAT_...    bool:1      ??                                      
   |_ZERO_PAGE:0081  BAT_V+          bool:1      ??                                      
   |_ZERO_PAGE:0081  DOCK_PWR_...    bool:1      ??                                      
   |_ZERO_PAGE:0081  TOUCH_X         bool:1      ??                                      
   |_ZERO_PAGE:0081  TOUCH_Y         bool:1      ??                                      
   |_ZERO_PAGE:0081  CMOS_BAT_...    bool:1      ??                                      
                            DAT_0082:                     ;XREF[19,0]:  cda8,ce60,ce62,ce7b,ce7d,ce90,cea0,ceb0
                                                          ;             cec0,dae1,dae4,db33,db36,db53,db56,db73
                                                          ;             db76,e846,e87a
ZERO_PAGE:0082                  undefined1  ??                                      
                            DAT_0083:                     ;XREF[2,0]:   db44,db51
ZERO_PAGE:0083                  undefined1  ??                                      
                            DAT_0084:                     ;XREF[3,0]:   db3a,db3e,db4c
ZERO_PAGE:0084                  undefined1  ??                                      
ZERO_PAGE:0085                  undefined1  ??                                      
ZERO_PAGE:0086                  ??          ??                                      
                            DAT_0087:                     ;XREF[3,0]:   ce69,db64,db71
ZERO_PAGE:0087                  undefined1  ??                                      
                            DAT_0088:                     ;XREF[4,0]:   ce5a,db5a,db5e,db6c
ZERO_PAGE:0088                  undefined1  ??                                      
                            DAT_0089:                     ;XREF[1,0]:   ce6c
ZERO_PAGE:0089                  ??          ??                                      
                            DAT_008a:                     ;XREF[1,0]:   ce6f
ZERO_PAGE:008a                  ??          ??                                      
                            DAT_008b:                     ;XREF[4,0]:   ce72,ce87,db84,db91
ZERO_PAGE:008b                  undefined1  ??                                      
                            DAT_008c:                     ;XREF[12,0]:  c7df,c7fd,c81c,c86b,c873,c877,c8a7,c8c5
                                                          ;             ce5d,db7a,db7e,db8c
ZERO_PAGE:008c                  undefined1  ??                                      
                            DAT_008d:                     ;XREF[2,0]:   ce75,ce8a
ZERO_PAGE:008d                  ??          ??                                      
                            DAT_008e:                     ;XREF[2,0]:   ce78,ce8d
ZERO_PAGE:008e                  ??          ??                                      
                            DAT_008f:                     ;XREF[8,0]:   cdab,dae8,daec,db0a,db1d,e848,e87c,e8b3
ZERO_PAGE:008f                  undefined1  ??                                      
                            DAT_0090:                     ;XREF[10,5]:  ce9a,ceaa,ceba,daf2,daf7,db03,db08,db1b
                                                          ;             db24,db26,ce9d,cead,cebd,db2a,db2c
ZERO_PAGE:0090                  undefined2  ??                                      
                            DAT_0092:                     ;XREF[3,0]:   e3f0,e3fb,e406
ZERO_PAGE:0092                  undefined1  ??                                      
                            DAT_0093:                     ;XREF[2,0]:   e3ee,e3f4
ZERO_PAGE:0093                  undefined1  ??                                      
                            DAT_0094:                     ;XREF[3,0]:   e3f2,e3f8,e40d
ZERO_PAGE:0094                  undefined1  ??                                      
                            95bitFields_0095:             ;XREF[41,0]:  c0e9,c0fa,c100,c116,c14b,c162,c168,c17e
                                                          ;             ca1d,ca9d,caa6,cab9,cac1,cb26,cbf8,cc7a
                                                          ;             cc7c,ce3d,d184,d92c,d9c8,d9d3,d9f9,da04
                                                          ;             da0b,dacd,dad8,dba9,dc07,dd63,ddc4,dfd1
                                                          ;             e024,e085,e08b,e201,e206,e229,e3e3,e3ec
                                                          ;             e8b6
ZERO_PAGE:0095                  95bitFields                                         
   |_ZERO_PAGE:0095  Touch_BOW...    byte:1      ??                                      
   |_ZERO_PAGE:0095  b7              bool:1      ??                                      
                            DAT_0096:                     ;XREF[4,0]:   d9c0,d9c5,e832,e8b8
ZERO_PAGE:0096                  ??          ??                                      
                            DAT_0097:                     ;XREF[2,0]:   da07,da0d
ZERO_PAGE:0097                  undefined1  ??                                      
                            DAT_0098:                     ;XREF[9,0]:   caa3,cabb,cb93,cb96,cbe6,cbf5,cc77,dad0
                                                          ;             dad4
ZERO_PAGE:0098                  undefined1  ??                                      
                            Touch_timeout_countdown_sec...;XREF[6,0]:   ce3f,d9f1,d9f5,dc04,e059,e082
ZERO_PAGE:0099                  undefined1  ??                                      
                            DAT_009a:                     ;XREF[5,0]:   d9fc,da00,ddc1,dfce,e021
ZERO_PAGE:009a                  undefined1  ??                                      
                            DAT_009b:                     ;XREF[2,0]:   d9cb,d9cf
ZERO_PAGE:009b                  undefined1  ??                                      
                            DAT_009c:                     ;XREF[6,0]:   ca9a,cab6,cbfa,cc74,dac5,dac9
ZERO_PAGE:009c                  undefined1  ??                                      
                            DAT_009d:                     ;XREF[10,0]:  c1a6,d29a,d2b2,da27,da29,da2f,da99,de40
                                                          ;             de4c,de52
ZERO_PAGE:009d                  undefined1  ??                                      
                            DAT_009e:                     ;XREF[10,0]:  c1aa,d2d2,d2e5,da1c,da1e,da24,daa0,de60
                                                          ;             de6c,de72
ZERO_PAGE:009e                  undefined1  ??                                      
                            DAT_009f:                     ;XREF[10,0]:  c1ae,d49c,d4bc,da11,da13,da19,da55,daa4
                                                          ;             de2e,de92
ZERO_PAGE:009f                  undefined1  ??                                      
                            DAT_00a0:                     ;XREF[1,0]:   d9b0
ZERO_PAGE:00a0                  undefined1  ??                                      
                            TimerY_countdown10_runmodeC:  ;XREF[4,0]:   d900,d902,d906,e834
ZERO_PAGE:00a1                  undefined1  ??                                      
                            TimerY_countdown2:            ;XREF[5,0]:   d181,d915,d918,d929,e836
ZERO_PAGE:00a2                  undefined1  ??                                      
                            DAT_00a3:                     ;XREF[4,0]:   d93d,d93f,d943,e838
ZERO_PAGE:00a3                  undefined1  ??                                      
                            DAT_00a4:                     ;XREF[4,0]:   d920,d9e1,d9e5,e8aa
ZERO_PAGE:00a4                  undefined1  ??                                      
                            DAT_00a5:                     ;XREF[2,0]:   dabc,dac0
ZERO_PAGE:00a5                  undefined1  ??                                      
                            DAT_00a6:                     ;XREF[10,0]:  ca97,cab3,cb3e,cb66,cbba,cbda,cc18,cc3b
                                                          ;             d9e8,d9ec
ZERO_PAGE:00a6                  undefined1  ??                                      
                            DAT_00a7:                     ;XREF[6,0]:   ca05,ca0f,ca15,ca19,d9d5,d9d9
ZERO_PAGE:00a7                  undefined1  ??                                      
                            DAT_00a8:                     ;XREF[2,0]:   d9db,d9df
ZERO_PAGE:00a8                  undefined1  ??                                      
                            DAT_00a9:                     ;XREF[2,0]:   d971,d975
ZERO_PAGE:00a9                  undefined1  ??                                      
                            DAT_00aa:                     ;XREF[1,0]:   e83a
ZERO_PAGE:00aa                  ??          ??                                      
                            Serial_TX_buf_len:            ;XREF[4,0]:   dcc7,dd3f,dd50,e83c
ZERO_PAGE:00ab                  undefined1  ??                                      
                            DAT_00ac:                     ;XREF[1,0]:   e83e
ZERO_PAGE:00ac                  undefined1  ??                                      
                            Serial_TX_other_buf:          ;XREF[1,15]:  dd02,dd07,dd0c,dd10,dd15,dd19,dd1e,dd23
                                                          ;             dd27,dd2b,dd30,dd35,dd39,dd3b,dd4e,e6b3
ZERO_PAGE:00ad                  db[14]      ??                                      
   |_ZERO_PAGE:00ad  [0]             db          ??                                      
   |_ZERO_PAGE:00ae  [1]             db          ??                                      
   |_ZERO_PAGE:00af  [2]             db          ??                                      
   |_ZERO_PAGE:00b0  [3]             db          ??                                      
   |_ZERO_PAGE:00b1  [4]             db          ??                                      
   |_ZERO_PAGE:00b2  [5]             db          ??                                      
   |_ZERO_PAGE:00b3  [6]             db          ??                                      
   |_ZERO_PAGE:00b4  [7]             db          ??                                      
   |_ZERO_PAGE:00b5  [8]             db          ??                                      
   |_ZERO_PAGE:00b6  [9]             db          ??                                      
   |_ZERO_PAGE:00b7  [10]            db          ??                                      
   |_ZERO_PAGE:00b8  [11]            db          ??                                      
   |_ZERO_PAGE:00b9  [12]            db          ??                                      
   |_ZERO_PAGE:00ba  [13]            db          ??                                      
                            Serial_TX_buf_bytes_to_send:  ;XREF[4,0]:   dd54,e2ba,e2c6,e8bb
ZERO_PAGE:00bb                  undefined1  ??                                      
                            Serial_TX_buf_ptr:            ;XREF[3,0]:   dd56,e2be,e2c4
ZERO_PAGE:00bc                  uint8_t     ??                                      
                            Serial_RX_ringBuf_WriteIndex: ;XREF[6,0]:   e273,e285,e297,e2d4,e2e3,e8be
ZERO_PAGE:00bd                  undefined1  ??                                      
                            Serial_RX_ringBuf_ReadIndex:  ;XREF[9,0]:   e271,e27c,e27e,e283,e28c,e29a,e2a5,e2df
                                                          ;             e8c1
ZERO_PAGE:00be                  undefined1  ??                                      
                            global_control_bits:          ;XREF[44,0]:  c105,c16d,c1a3,d14e,d1cd,d1e0,d20c,d266
                                                          ;             d293,da4c,da4f,da52,da92,daa8,daab,db2f
                                                          ;             dcd7,dcda,dcfb,ddc6,ddcc,ddd5,de2c,de94
                                                          ;             de9d,de9f,df12,df59,df89,df8c,dfbc,dfc4
                                                          ;             dfd3,e026,e1fa,e22e,e869,e86b,e86d,e89a
                                                          ;             e89c,e89e,e8a8,e8c4

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

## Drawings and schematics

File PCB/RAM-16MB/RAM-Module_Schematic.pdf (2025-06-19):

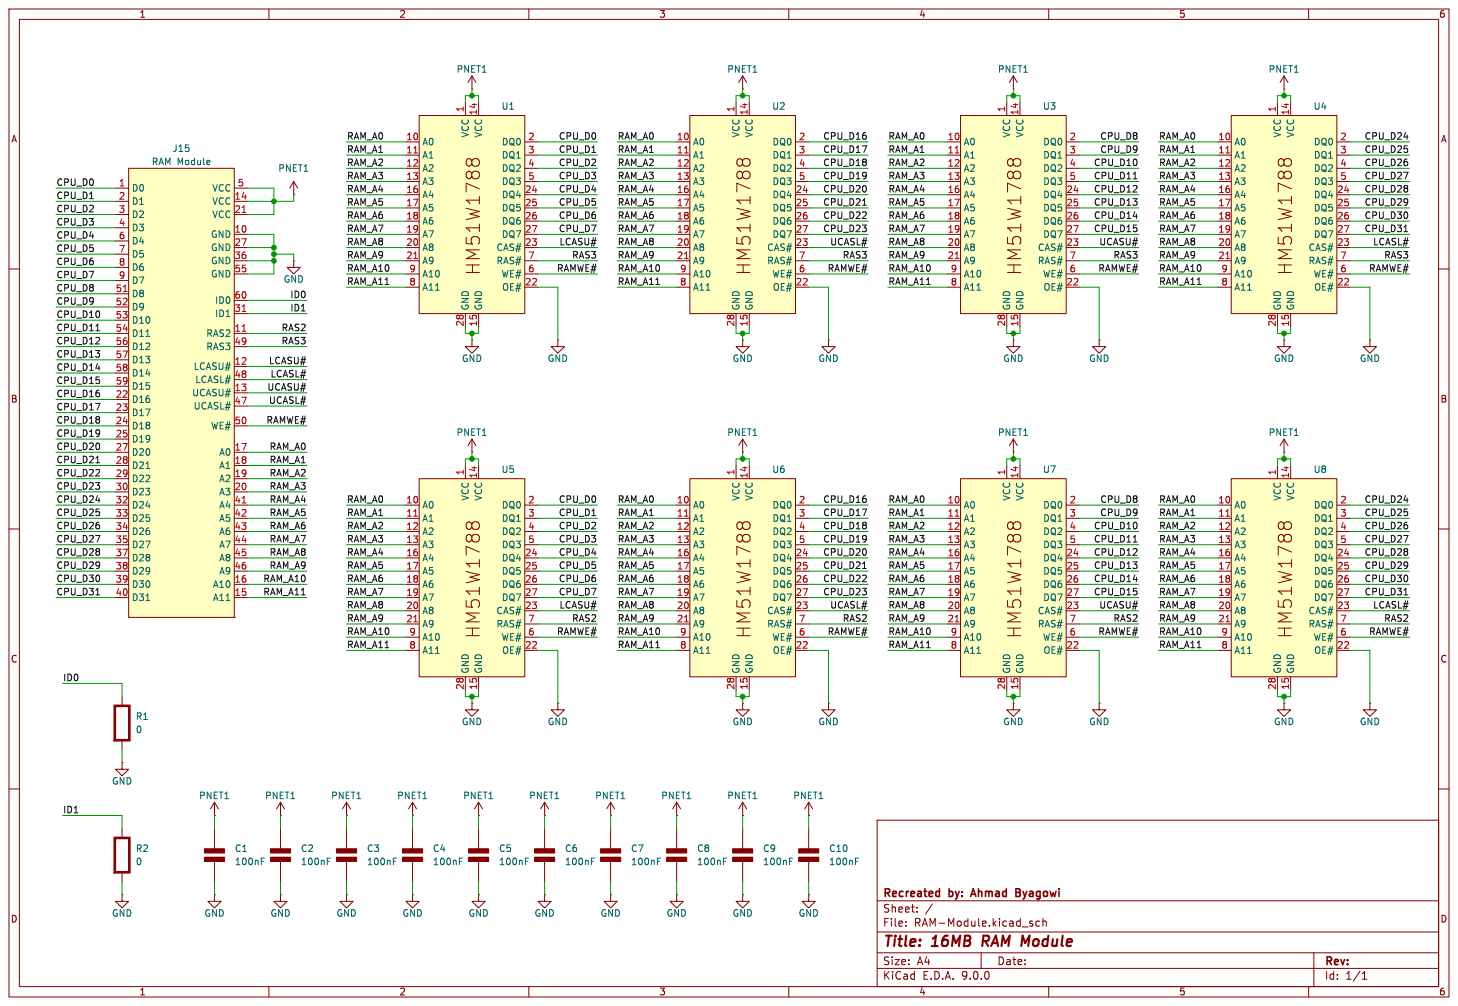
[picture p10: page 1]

1 GND 28 VCC 14 GND 15 DQ0 2 DQ1 3 DQ2 4 DQ3 5 DQ4 24 DQ5 25 DQ6 26 DQ7 27 CAS# 23 RAS# 7 WE# 6 OE# 22 U6 PNET1HM51W1788

1 GND 28 VCC 14 GND 15 DQ0 2 DQ1 3 DQ2 4 DQ3 5 DQ4 24 DQ5 25 DQ6 26 DQ7 27 CAS# 23 RAS# 7 WE# 6 OE# 22 U1 PNET1C2

1 GND 28 VCC 14 GND 15 DQ0 2 DQ1 3 DQ2 4 DQ3 5 DQ4 24 DQ5 25 DQ6 26 DQ7 27 CAS# 23 RAS# 7 WE# 6 OE# 22 U2 GND GND

1 GND 28 VCC 14 GND 15 DQ0 2 DQ1 3 DQ2 4 DQ3 5 DQ4 24 DQ5 25 DQ6 26 DQ7 27 CAS# 23 RAS# 7 WE# 6 OE# 22 U3 GND HM51W1788

1 GND 28 VCC 14 GND 15 DQ0 2 DQ1 3 DQ2 4 DQ3 5 DQ4 24 DQ5 25 DQ6 26 DQ7 27 CAS# 23 RAS# 7 WE# 6 OE# 22 U4 GND

1 GND 28 VCC 14 GND 15 DQ0 2 DQ1 3 DQ2 4 DQ3 5 DQ4 24 DQ5 25 DQ6 26 DQ7 27 CAS# 23 RAS# 7 WE# 6 OE# 22 U8 R1

1 GND 28 VCC 14 GND 15 DQ0 2 DQ1 3 DQ2 4 DQ3 5 DQ4 24 DQ5 25 DQ6 26 DQ7 27 CAS# 23 RAS# 7 WE# 6 OE# 22 U5 HM51W1788

1 GND 28 VCC 14 GND 15 DQ0 2 DQ1 3 DQ2 4 DQ3 5 DQ4 24 DQ5 25 DQ6 26 DQ7 27 CAS# 23 RAS# 7 WE# 6 OE# 22 U7 GND

Id: 1/1 Title: 16MB RAM Module

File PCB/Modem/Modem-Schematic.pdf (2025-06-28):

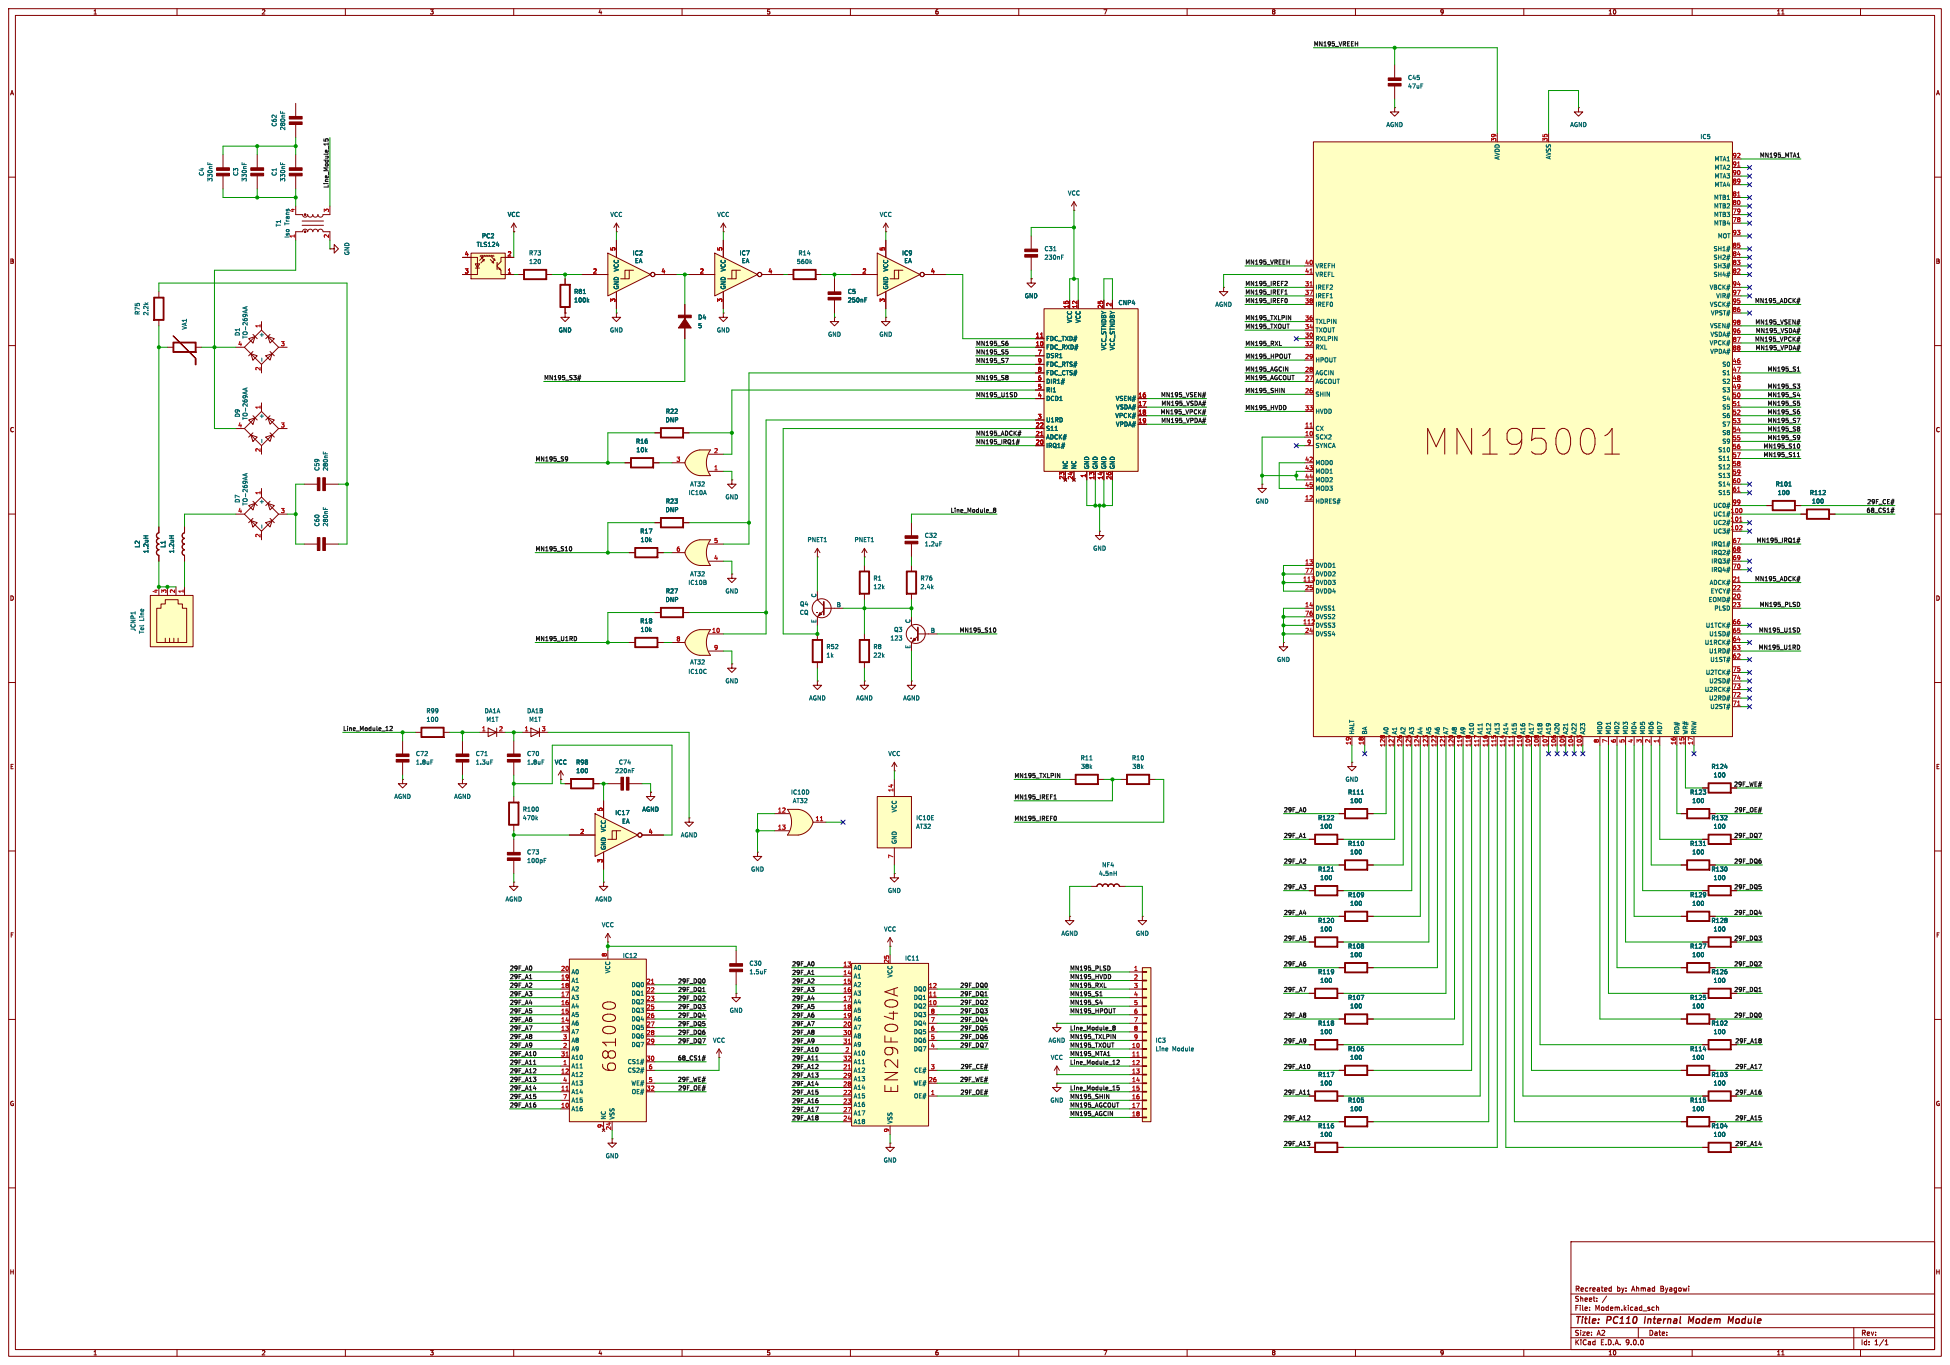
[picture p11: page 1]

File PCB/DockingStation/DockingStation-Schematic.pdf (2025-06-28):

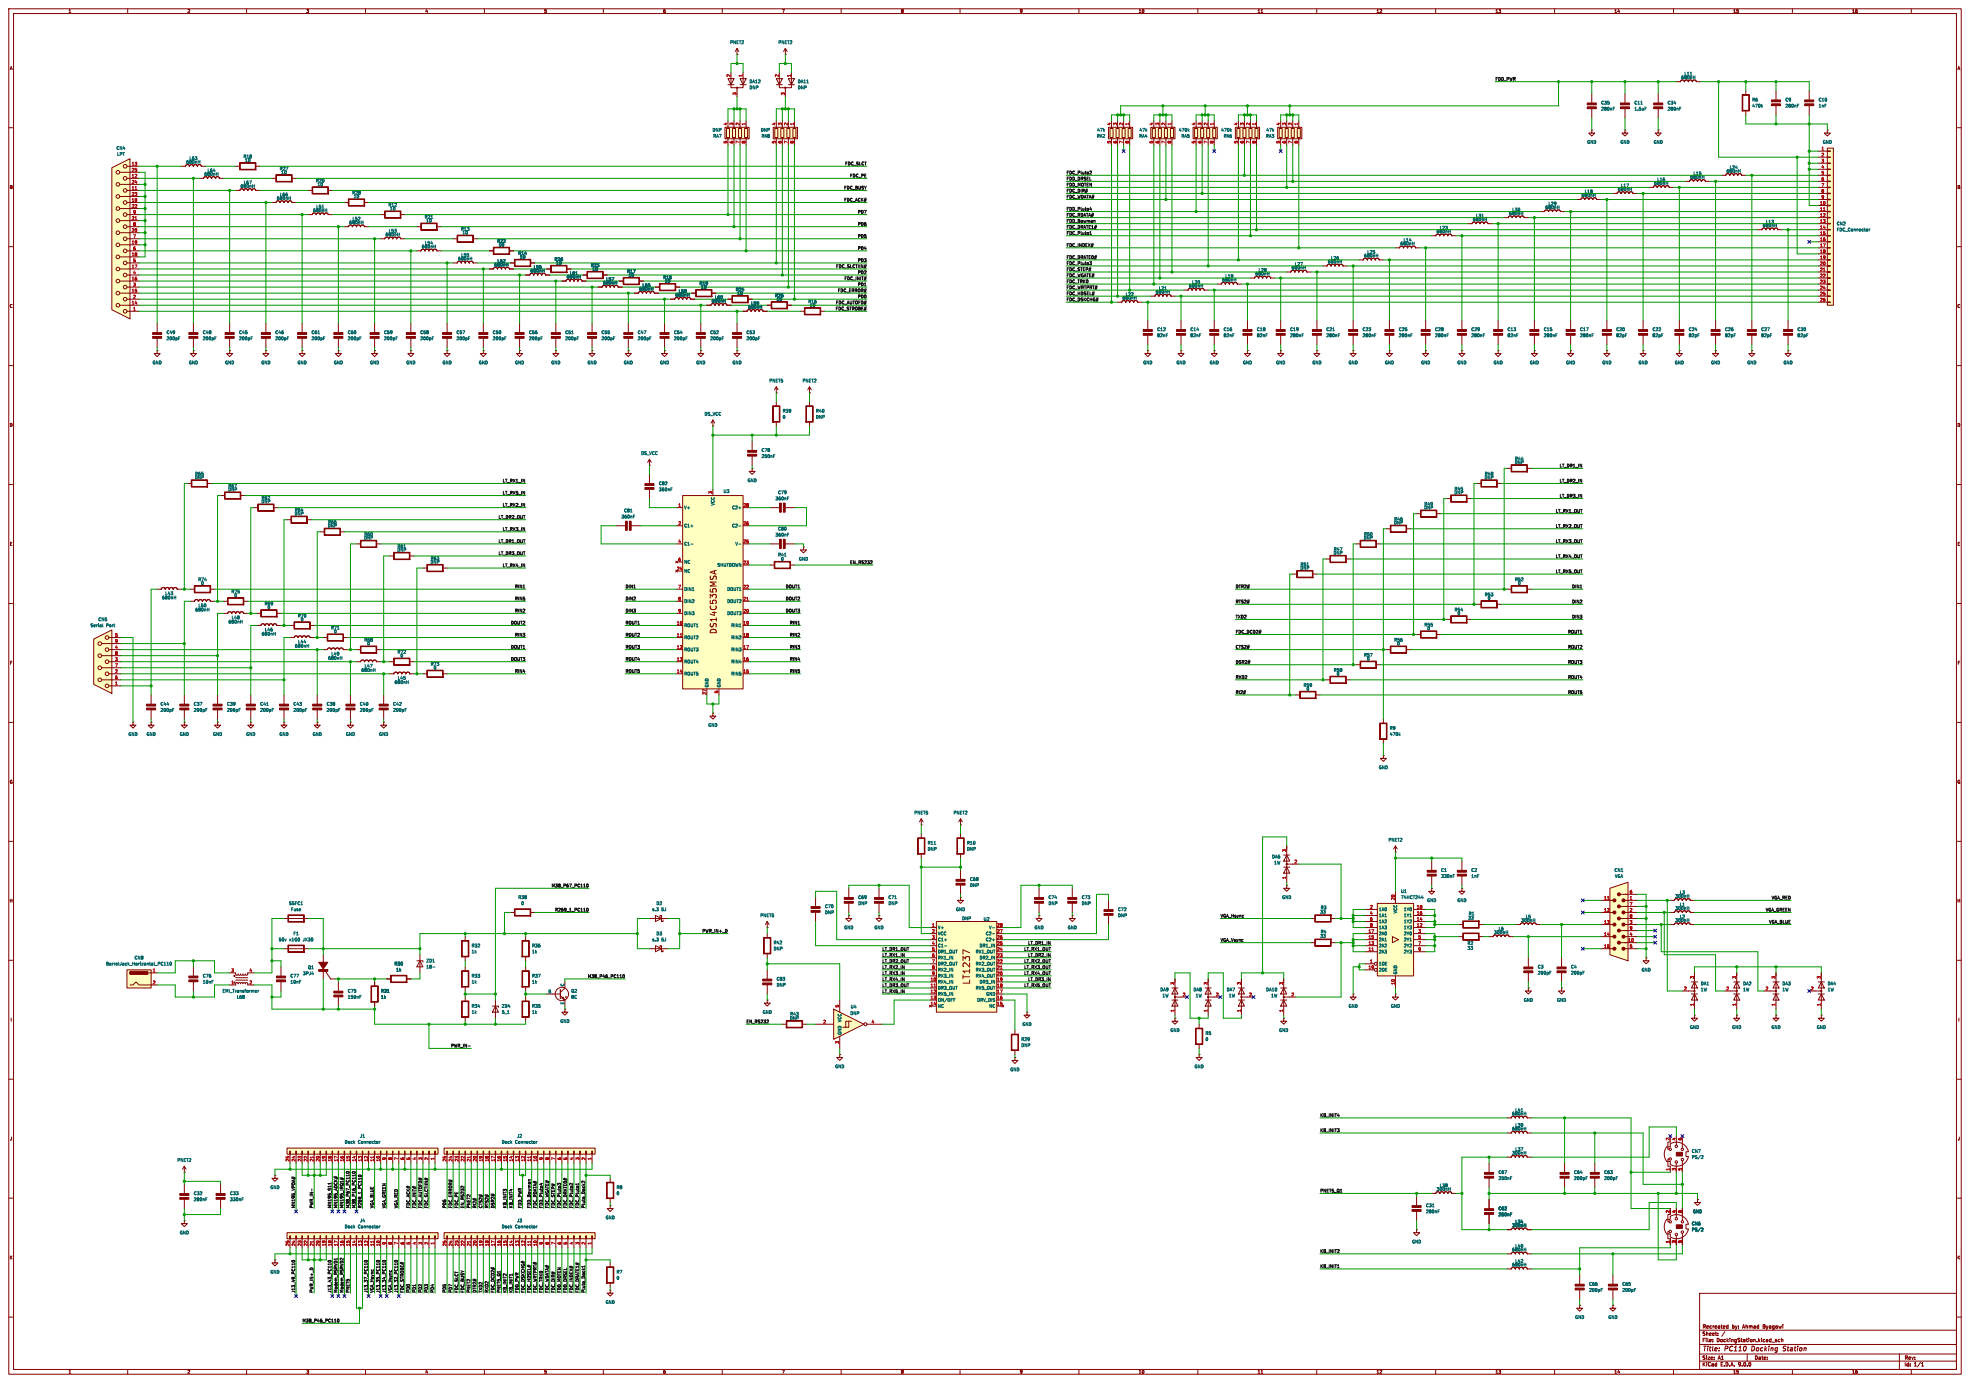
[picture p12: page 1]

Id: 1/1 Title: PC110 Docking Station

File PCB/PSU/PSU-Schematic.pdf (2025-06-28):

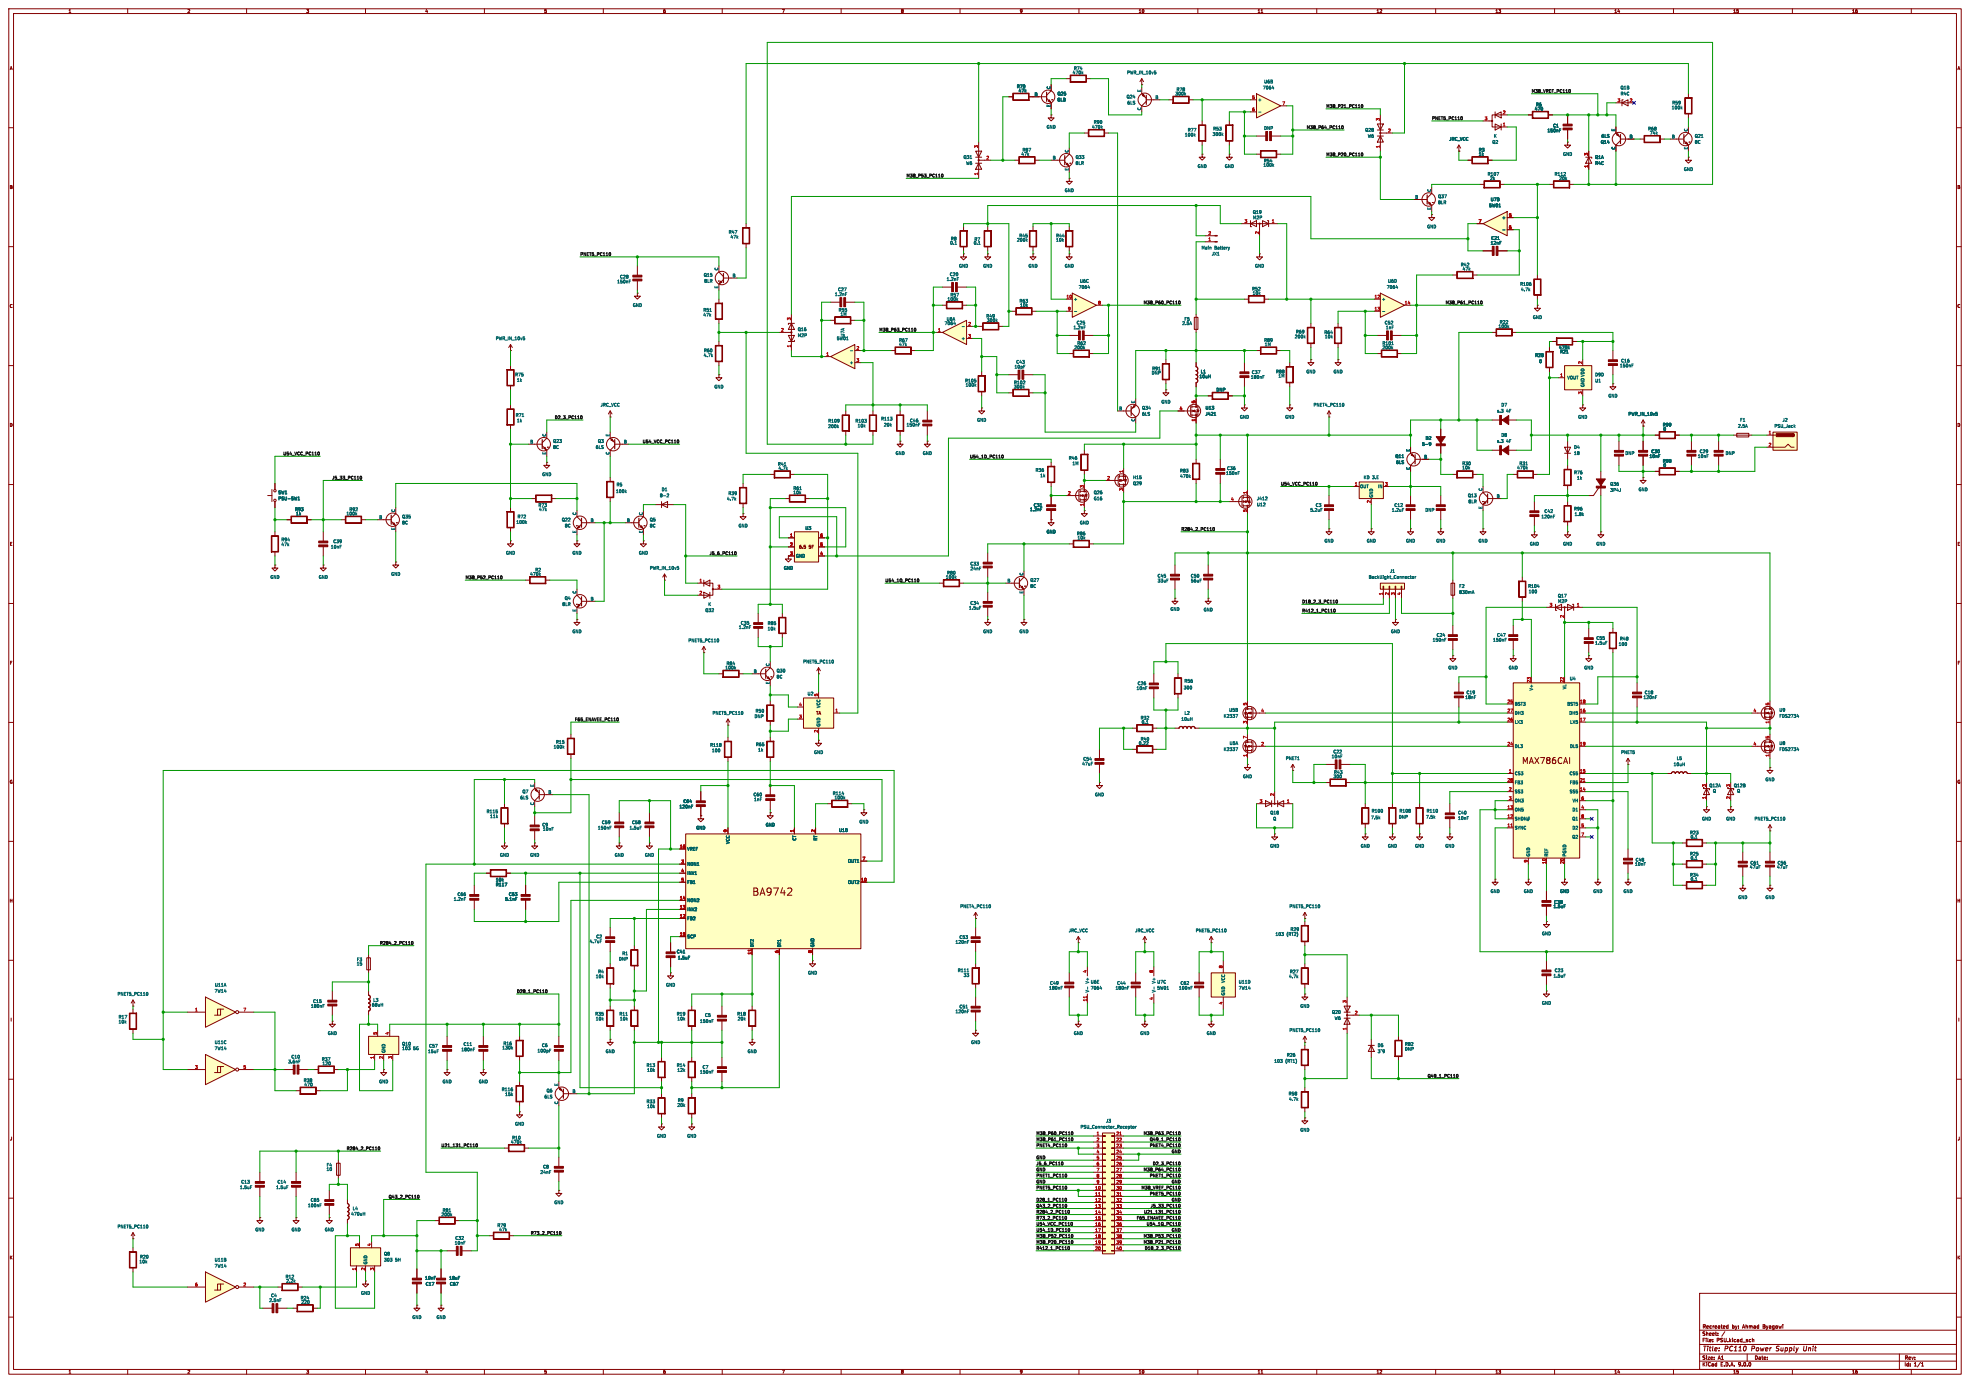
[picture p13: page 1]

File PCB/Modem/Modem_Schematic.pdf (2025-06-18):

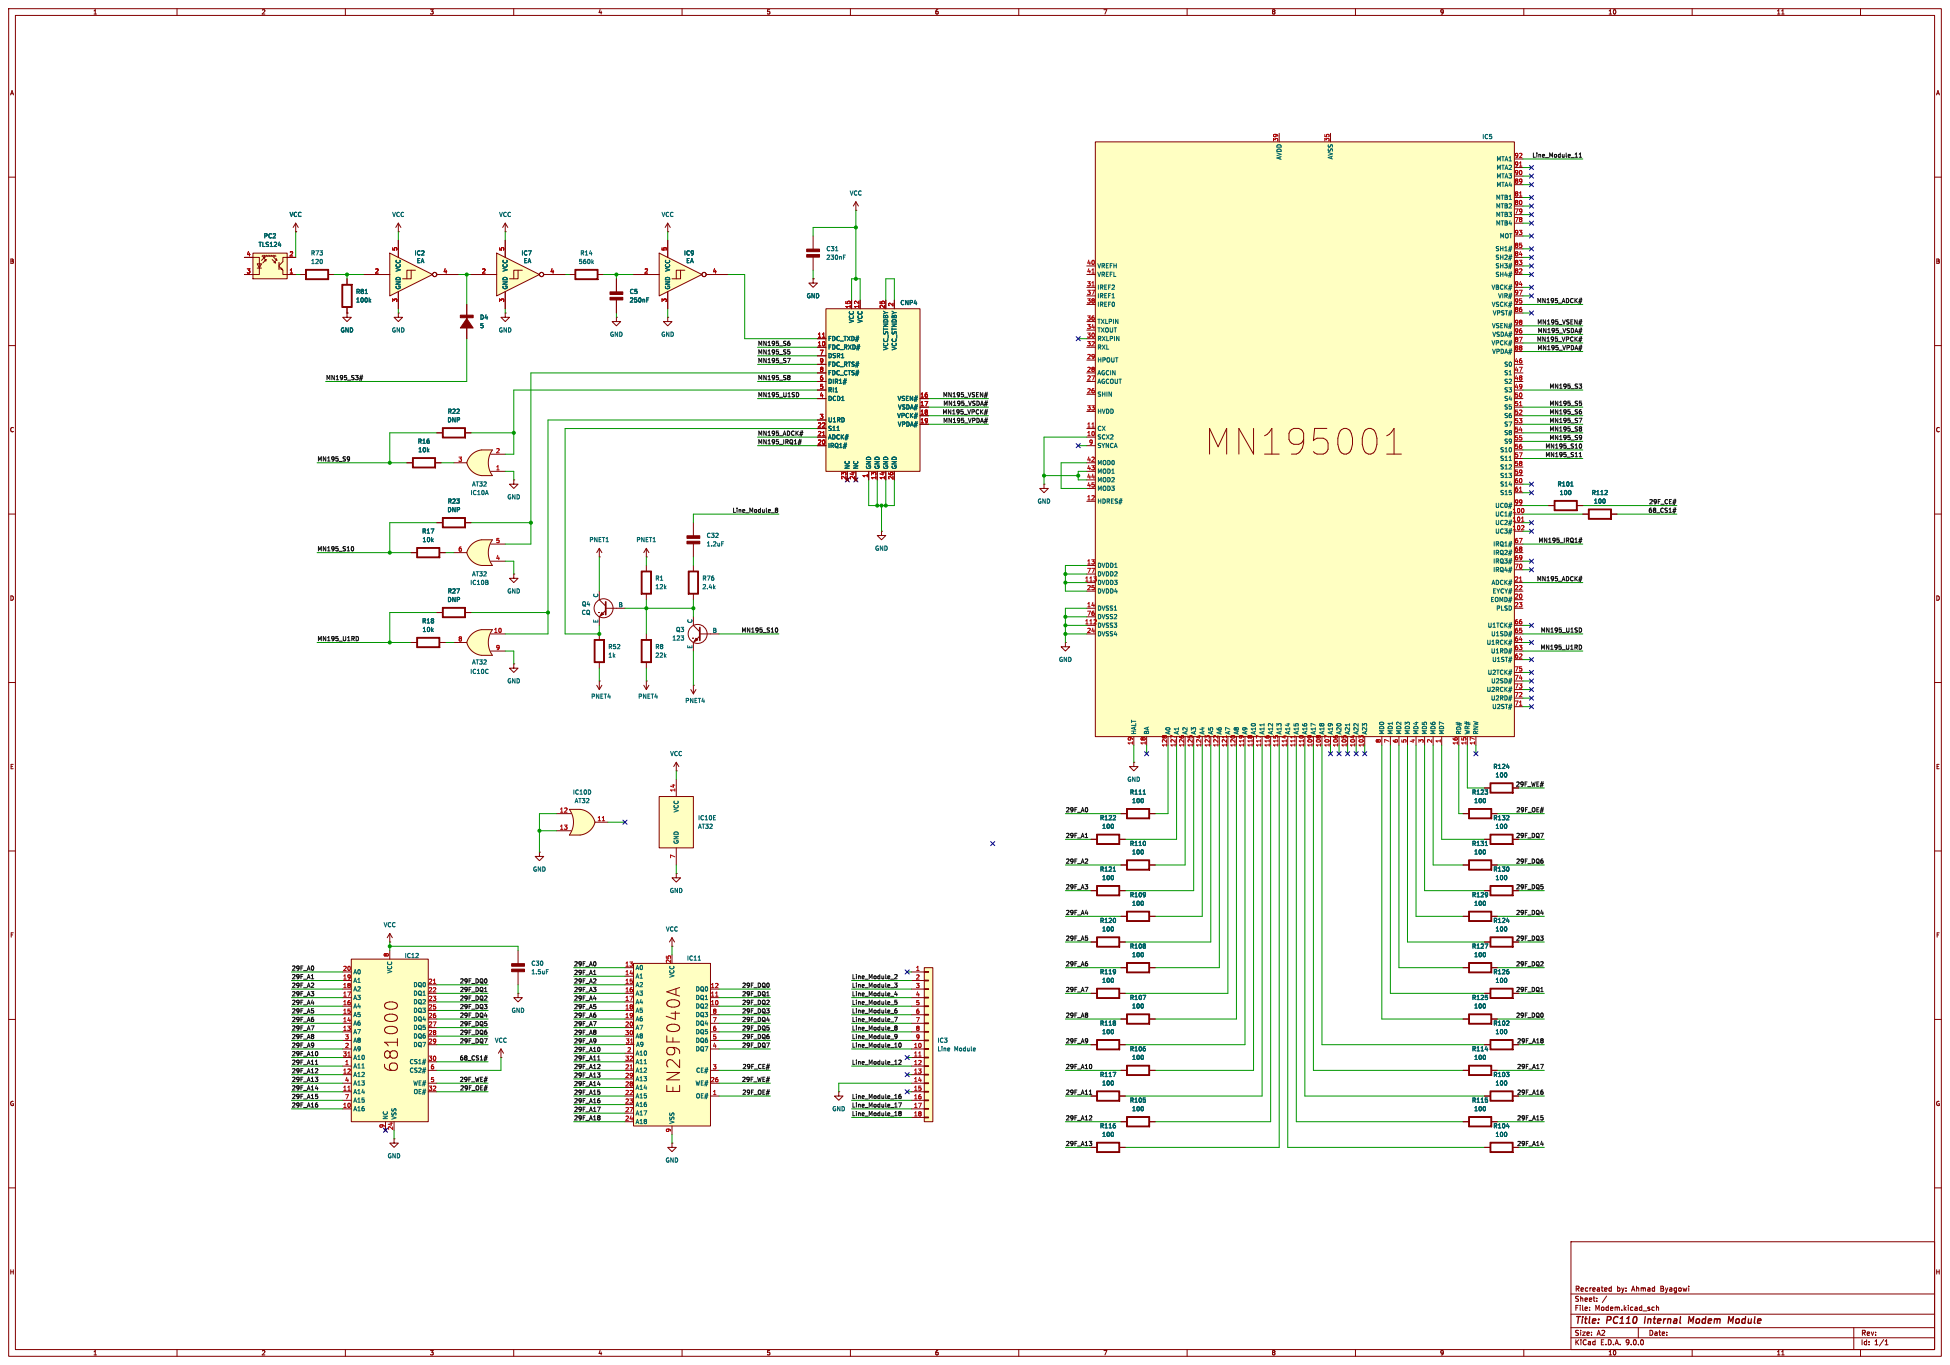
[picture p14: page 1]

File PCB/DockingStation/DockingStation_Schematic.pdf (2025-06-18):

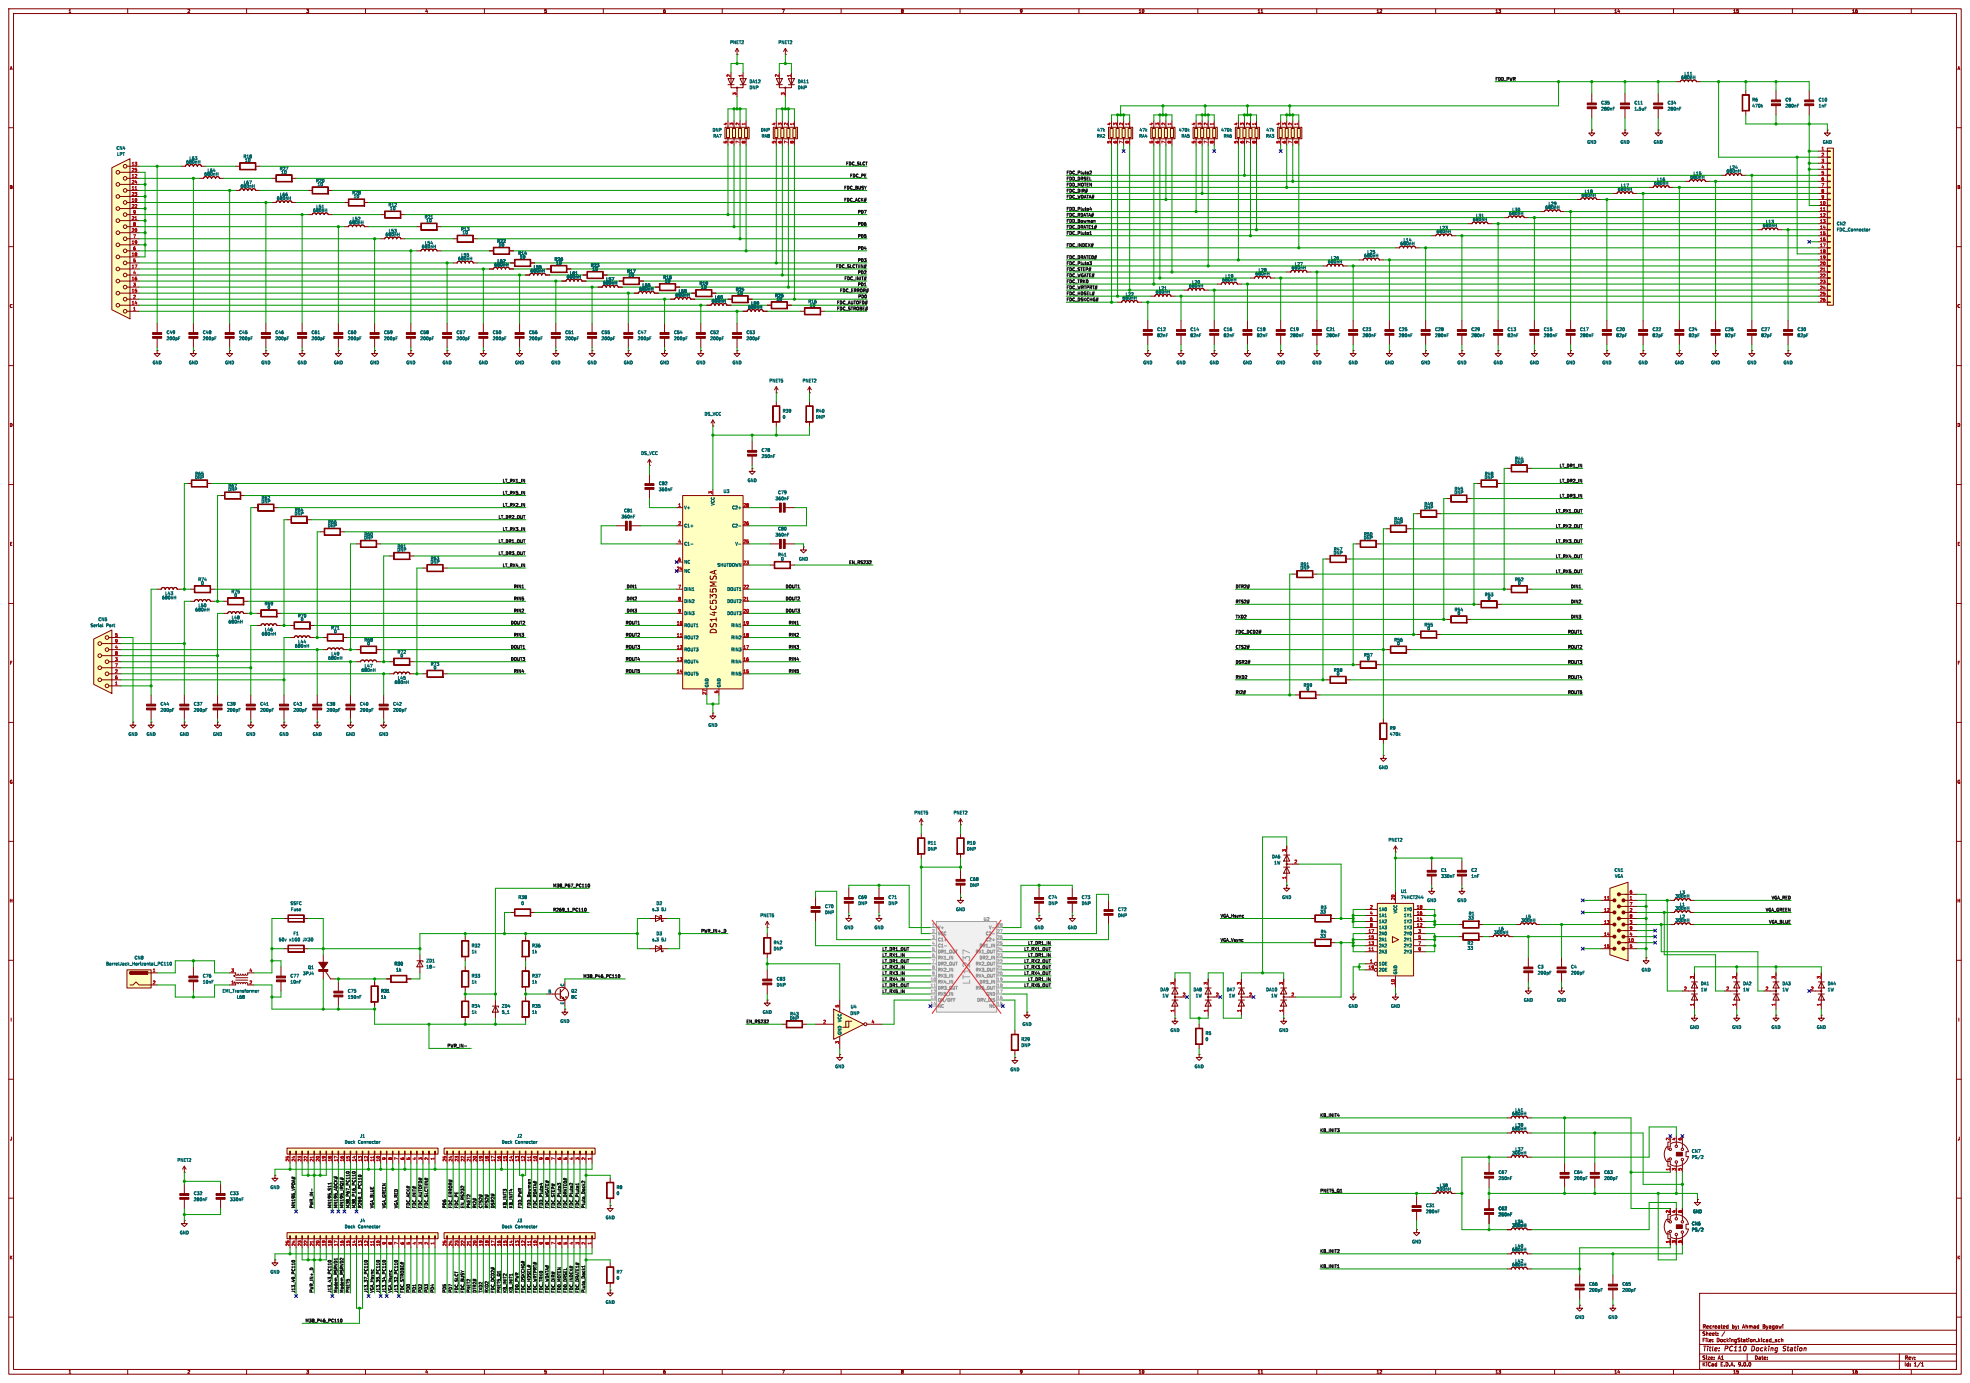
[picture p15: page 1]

Id: 1/1 Title: PC110 Docking Station

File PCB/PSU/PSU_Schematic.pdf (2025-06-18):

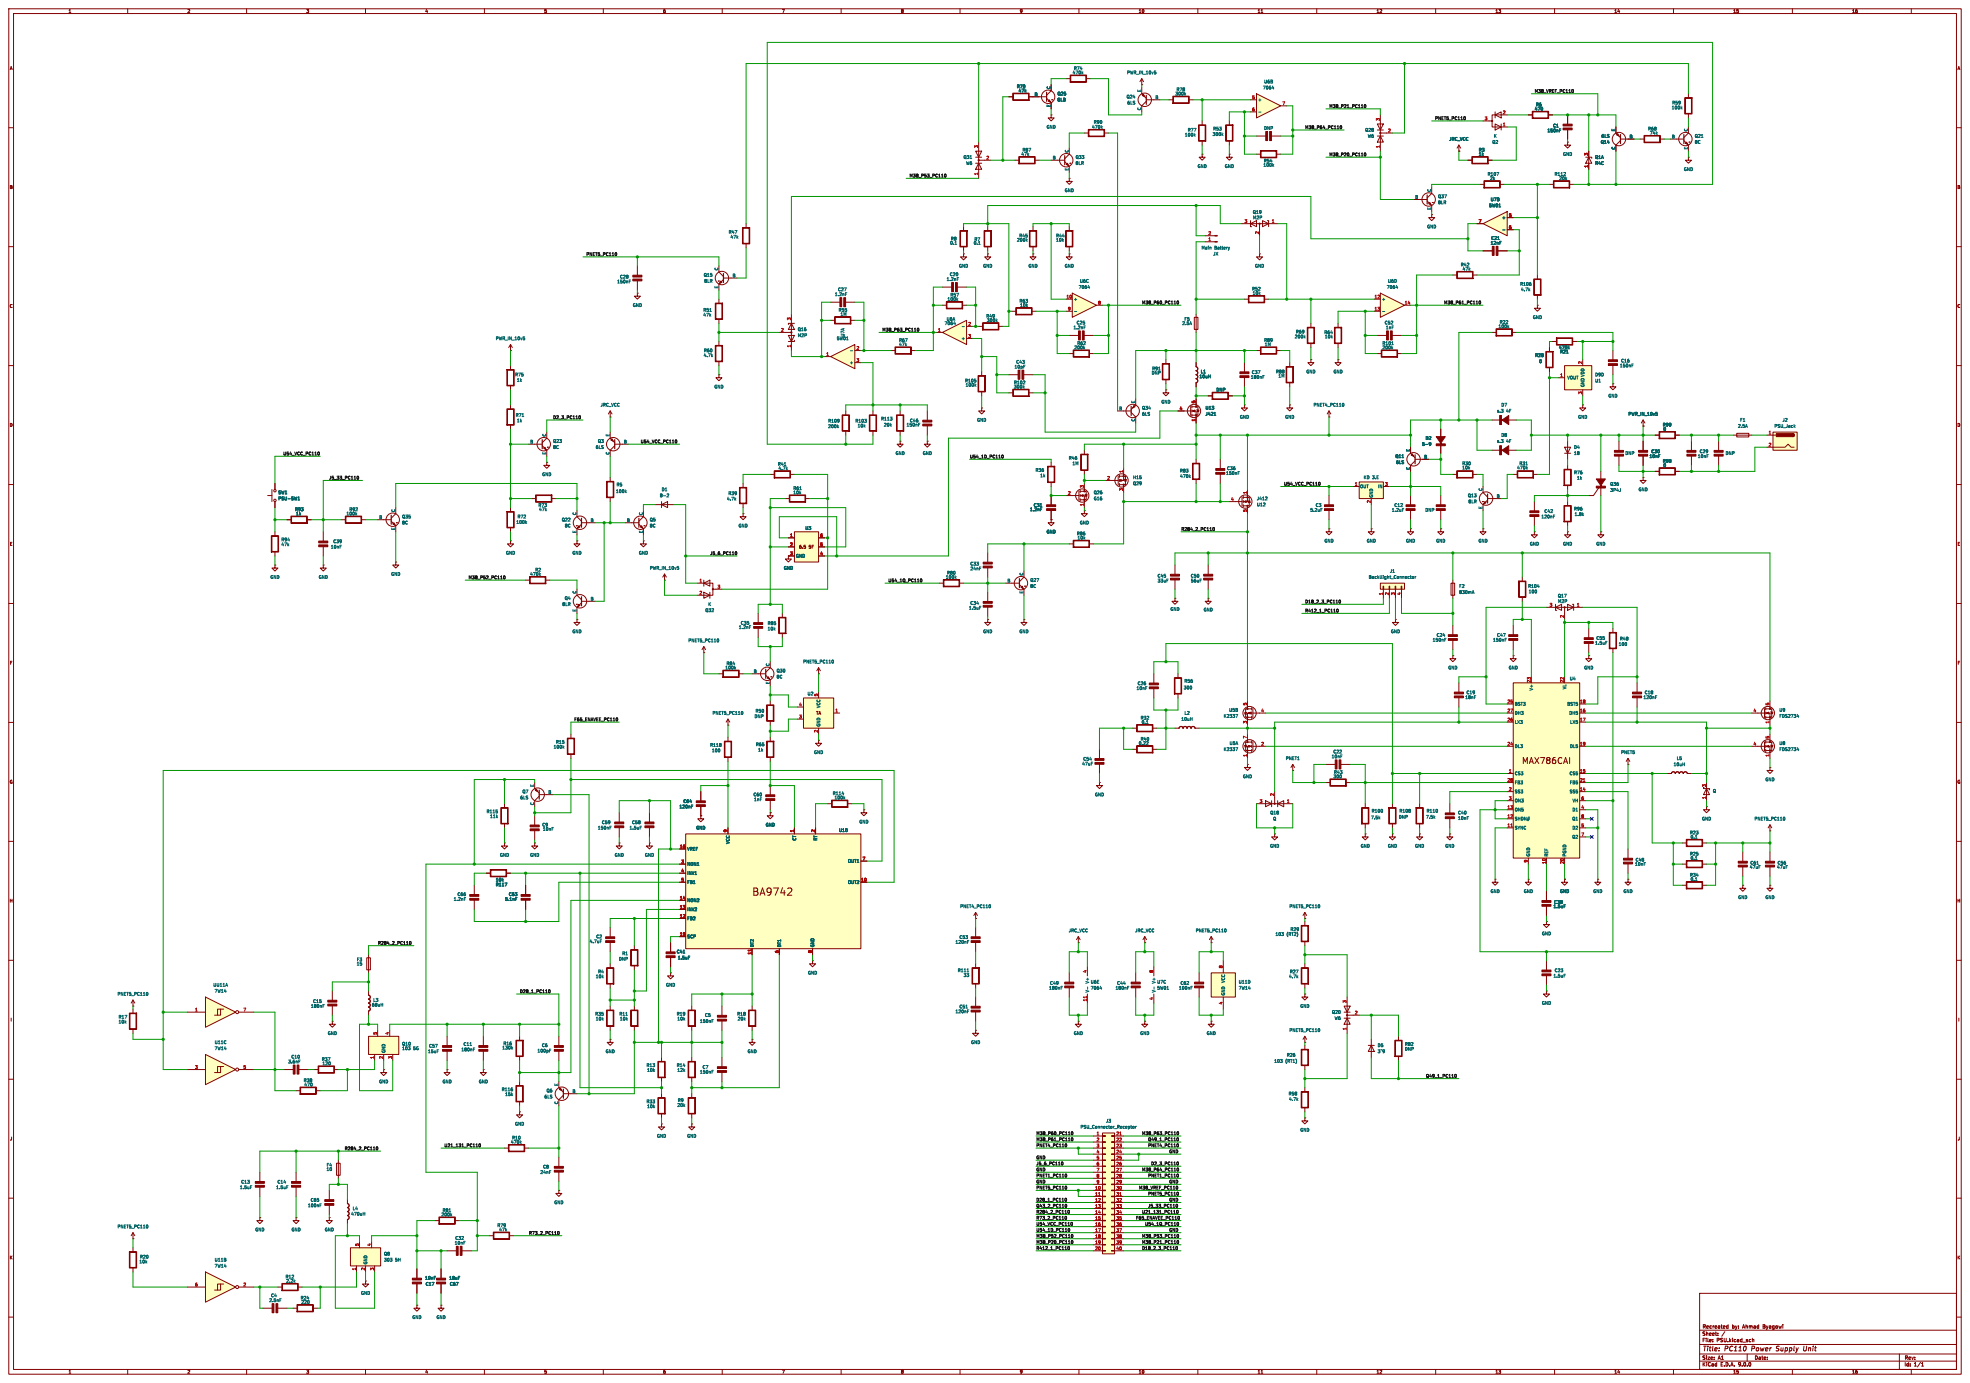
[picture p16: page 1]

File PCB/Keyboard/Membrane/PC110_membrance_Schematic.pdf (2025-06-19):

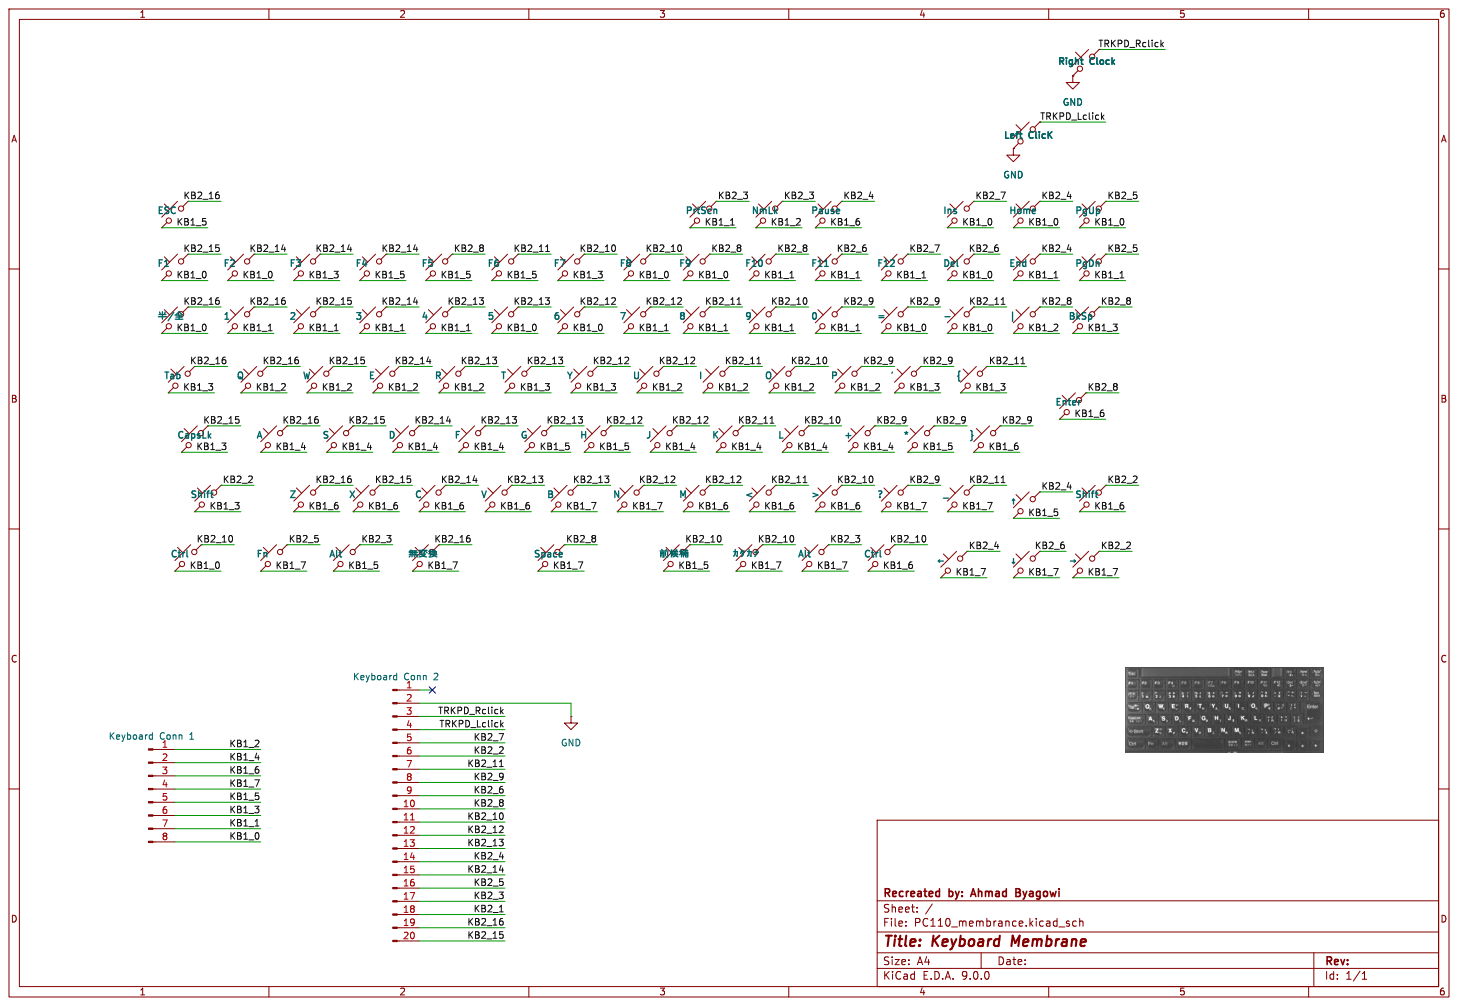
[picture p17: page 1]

Id: 1/1 Title: Keyboard Membrane

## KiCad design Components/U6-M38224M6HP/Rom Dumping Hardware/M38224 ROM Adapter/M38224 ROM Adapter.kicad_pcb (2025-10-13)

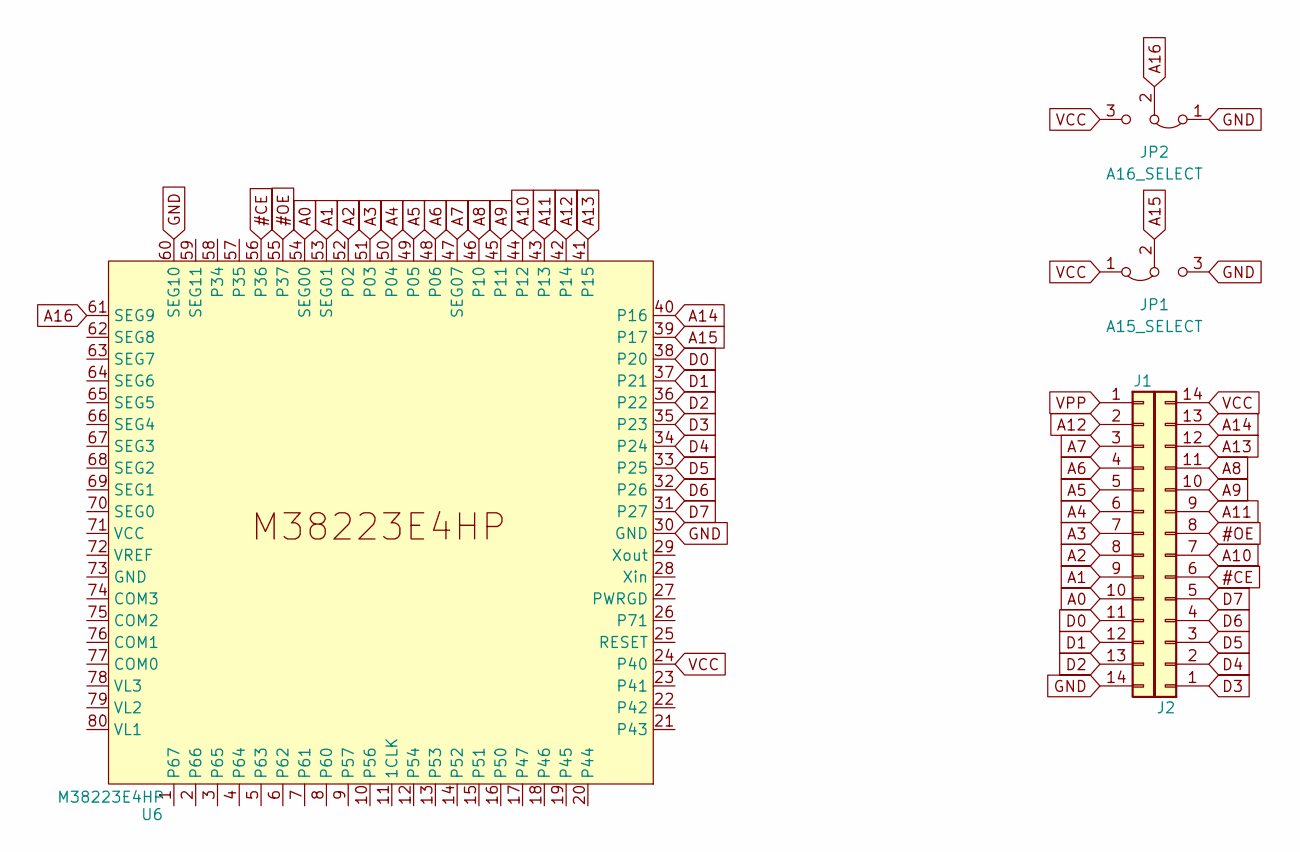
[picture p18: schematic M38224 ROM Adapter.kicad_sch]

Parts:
J1, J2: Conn_01x14; PinHeader_1x14_P2.54mm_Vertical
JP1: A15_SELECT; SolderJumper-3_P1.3mm_Bridged2Bar12_RoundedPad1.0x1.5mm
JP2: A16_SELECT; SolderJumper-3_P1.3mm_Bridged2Bar12_RoundedPad1.0x1.5mm
U6: M38223E4HP; QFN-80

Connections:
#CE: J2.6, U6.56 (P36)
#OE: J2.8, U6.55 (P37)
A0: J1.10, U6.54 (SEG00)
A1: J1.9, U6.53 (SEG01)
A2: J1.8, U6.52 (P02)
A3: J1.7, U6.51 (P03)
A4: J1.6, U6.50 (P04)
A5: J1.5, U6.49 (P05)
A6: J1.4, U6.48 (P06)
A7: J1.3, U6.47 (SEG07)
A8: J2.11, U6.46 (P10)
A9: J2.10, U6.45 (P11)
A10: J2.7, U6.44 (P12)
A11: J2.9, U6.43 (P13)
A12: J1.2, U6.42 (P14)
A13: J2.12, U6.41 (P15)
A14: J2.13, U6.40 (P16)
A15: JP1.2 (C), U6.39 (P17)
A16: JP2.2 (C), U6.61 (SEG9)
D0: J1.11, U6.38 (P20)
D1: J1.12, U6.37 (P21)
D2: J1.13, U6.36 (P22)
D3: J2.1, U6.35 (P23)
D4: J2.2, U6.34 (P24)
D5: J2.3, U6.33 (P25)
D6: J2.4, U6.32 (P26)
D7: J2.5, U6.31 (P27)
GND: J1.14, JP1.3 (B), JP2.1 (A), U6.30 (GND), U6.60 (SEG10)
VCC: J2.14, JP1.1 (A), JP2.3 (B), U6.24 (P40)
VPP: J1.1

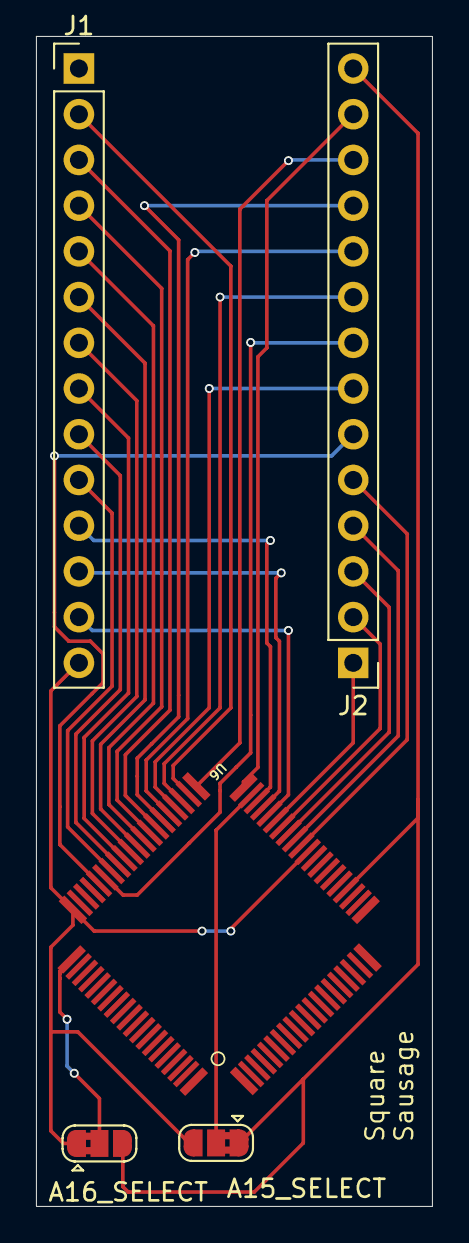
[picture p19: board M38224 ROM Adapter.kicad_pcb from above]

Board: 2 copper layers, 22.0 x 65.0 mm, 5 parts (0 on the bottom side), 29 nets.

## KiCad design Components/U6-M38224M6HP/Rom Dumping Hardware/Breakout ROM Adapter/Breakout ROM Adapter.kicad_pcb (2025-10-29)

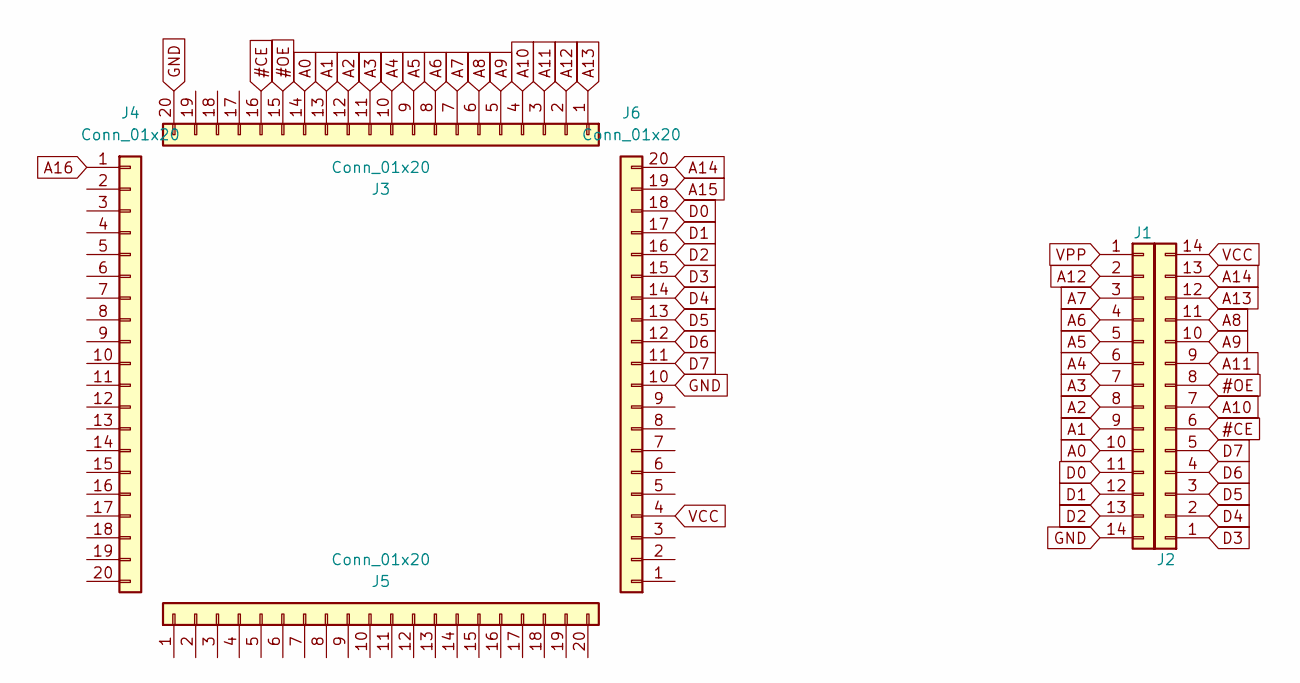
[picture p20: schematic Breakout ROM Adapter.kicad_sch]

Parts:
J1, J2: Conn_01x14; PinHeader_1x14_P2.54mm_Vertical
J3, J4, J5, J6: Conn_01x20; PinSocket_2x10_P2.54mm_Vertical

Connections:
#CE: J2.6, J3.16
#OE: J2.8, J3.15
A0: J1.10, J3.14
A1: J1.9, J3.13
A2: J1.8, J3.12
A3: J1.7, J3.11
A4: J1.6, J3.10
A5: J1.5, J3.9
A6: J1.4, J3.8
A7: J1.3, J3.7
A8: J2.11, J3.6
A9: J2.10, J3.5
A10: J2.7, J3.4
A11: J2.9, J3.3
A12: J1.2, J3.2
A13: J2.12, J3.1
A14: J2.13, J6.20
A15: J6.19
A16: J4.1
D0: J1.11, J6.18
D1: J1.12, J6.17
D2: J1.13, J6.16
D3: J2.1, J6.15
D4: J2.2, J6.14
D5: J2.3, J6.13
D6: J2.4, J6.12
D7: J2.5, J6.11
GND: J1.14, J3.20, J6.10
VCC: J2.14, J6.4
VPP: J1.1

Board: 2 copper layers, 6 parts (0 on the bottom side), 27 nets, no tracks yet.

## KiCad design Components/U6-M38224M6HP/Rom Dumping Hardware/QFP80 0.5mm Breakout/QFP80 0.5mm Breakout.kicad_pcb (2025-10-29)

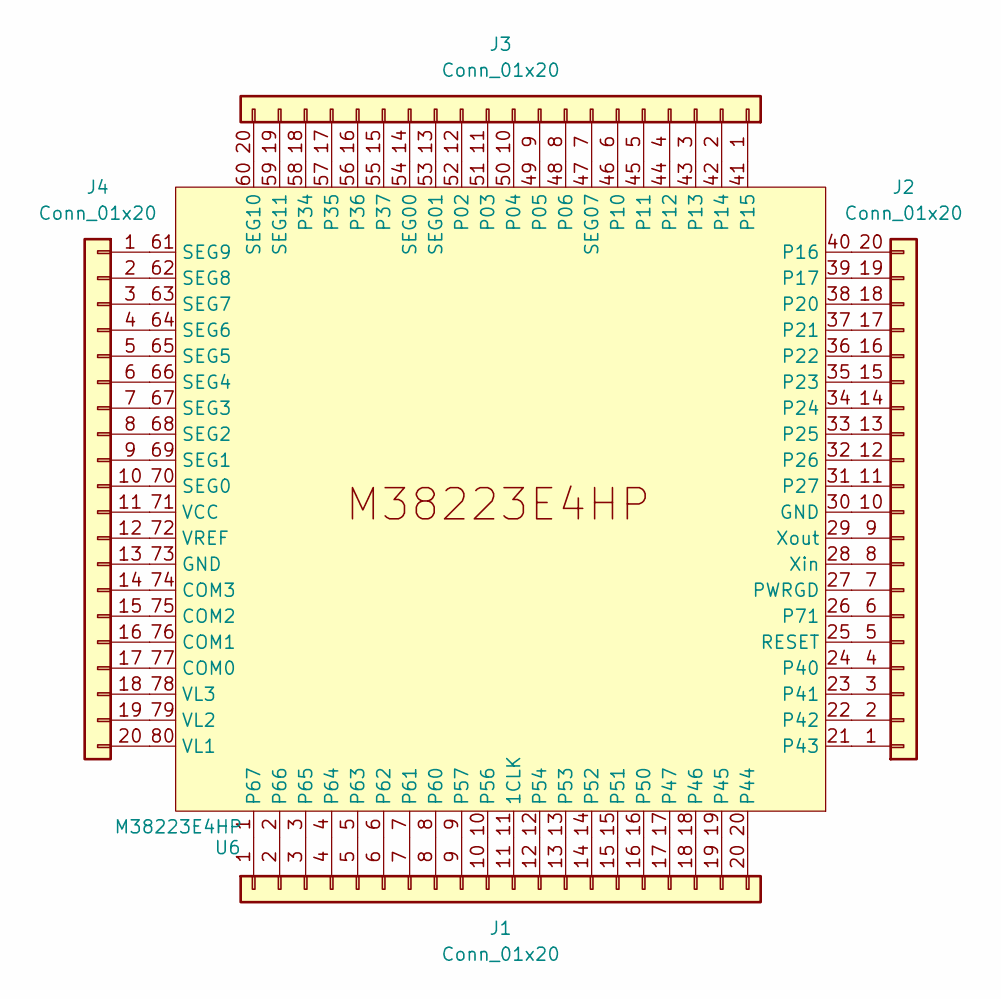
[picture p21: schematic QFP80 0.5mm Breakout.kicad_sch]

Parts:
J1, J2, J3, J4: Conn_01x20; PinSocket_2x10_P2.54mm_Vertical
U6: M38223E4HP; QFN-80

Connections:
unnamed: J1.1, U6.1 (P67)
unnamed: J1.2, U6.2 (P66)
unnamed: J1.3, U6.3 (P65)
unnamed: J1.4, U6.4 (P64)
unnamed: J1.5, U6.5 (P63)
unnamed: J1.6, U6.6 (P62)
unnamed: J1.7, U6.7 (P61)
unnamed: J1.8, U6.8 (P60)
unnamed: J1.9, U6.9 (P57)
unnamed: J1.10, U6.10 (P56)
unnamed: J1.11, U6.11 (1CLK)
unnamed: J1.12, U6.12 (P54)
unnamed: J1.13, U6.13 (P53)
unnamed: J1.14, U6.14 (P52)
unnamed: J1.15, U6.15 (P51)
unnamed: J1.16, U6.16 (P50)
unnamed: J1.17, U6.17 (P47)
unnamed: J1.18, U6.18 (P46)
unnamed: J1.19, U6.19 (P45)
unnamed: J1.20, U6.20 (P44)
unnamed: J2.1, U6.21 (P43)
unnamed: J2.2, U6.22 (P42)
unnamed: J2.3, U6.23 (P41)
unnamed: J2.4, U6.24 (P40)
unnamed: J2.5, U6.25 (RESET)
unnamed: J2.6, U6.26 (P71)
unnamed: J2.7, U6.27 (PWRGD)
unnamed: J2.8, U6.28 (Xin)
unnamed: J2.9, U6.29 (Xout)
unnamed: J2.10, U6.30 (GND)
unnamed: J2.11, U6.31 (P27)
unnamed: J2.12, U6.32 (P26)
unnamed: J2.13, U6.33 (P25)
unnamed: J2.14, U6.34 (P24)
unnamed: J2.15, U6.35 (P23)
unnamed: J2.16, U6.36 (P22)
unnamed: J2.17, U6.37 (P21)
unnamed: J2.18, U6.38 (P20)
unnamed: J2.19, U6.39 (P17)
unnamed: J2.20, U6.40 (P16)
unnamed: J3.1, U6.41 (P15)
unnamed: J3.2, U6.42 (P14)
unnamed: J3.3, U6.43 (P13)
unnamed: J3.4, U6.44 (P12)
unnamed: J3.5, U6.45 (P11)
unnamed: J3.6, U6.46 (P10)
unnamed: J3.7, U6.47 (SEG07)
unnamed: J3.8, U6.48 (P06)
unnamed: J3.9, U6.49 (P05)
unnamed: J3.10, U6.50 (P04)
unnamed: J3.11, U6.51 (P03)
unnamed: J3.12, U6.52 (P02)
unnamed: J3.13, U6.53 (SEG01)
unnamed: J3.14, U6.54 (SEG00)
unnamed: J3.15, U6.55 (P37)
unnamed: J3.16, U6.56 (P36)
unnamed: J3.17, U6.57 (P35)
unnamed: J3.18, U6.58 (P34)
unnamed: J3.19, U6.59 (SEG11)
unnamed: J3.20, U6.60 (SEG10)
unnamed: J4.1, U6.61 (SEG9)
unnamed: J4.2, U6.62 (SEG8)
unnamed: J4.3, U6.63 (SEG7)
unnamed: J4.4, U6.64 (SEG6)
unnamed: J4.5, U6.65 (SEG5)
unnamed: J4.6, U6.66 (SEG4)
unnamed: J4.7, U6.67 (SEG3)
unnamed: J4.8, U6.68 (SEG2)
unnamed: J4.9, U6.69 (SEG1)
unnamed: J4.10, U6.70 (SEG0)
unnamed: J4.11, U6.71 (VCC)
unnamed: J4.12, U6.72 (VREF)
unnamed: J4.13, U6.73 (GND)
unnamed: J4.14, U6.74 (COM3)
unnamed: J4.15, U6.75 (COM2)
unnamed: J4.16, U6.76 (COM1)
unnamed: J4.17, U6.77 (COM0)
unnamed: J4.18, U6.78 (VL3)
unnamed: J4.19, U6.79 (VL2)
unnamed: J4.20, U6.80 (VL1)

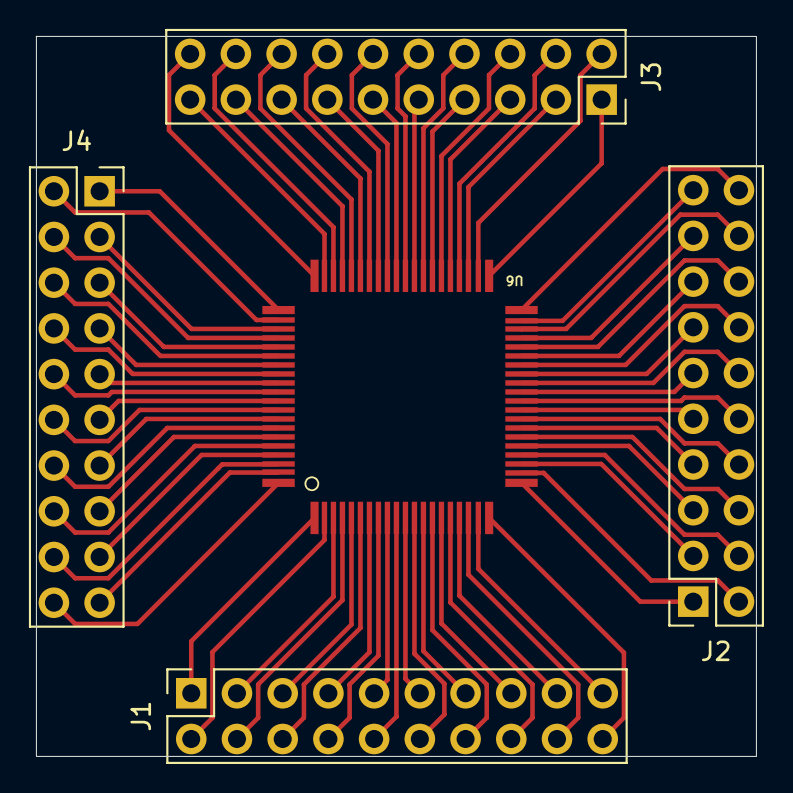
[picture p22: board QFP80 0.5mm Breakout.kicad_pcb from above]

Board: 2 copper layers, 40.0 x 40.0 mm, 5 parts (0 on the bottom side), 80 nets.

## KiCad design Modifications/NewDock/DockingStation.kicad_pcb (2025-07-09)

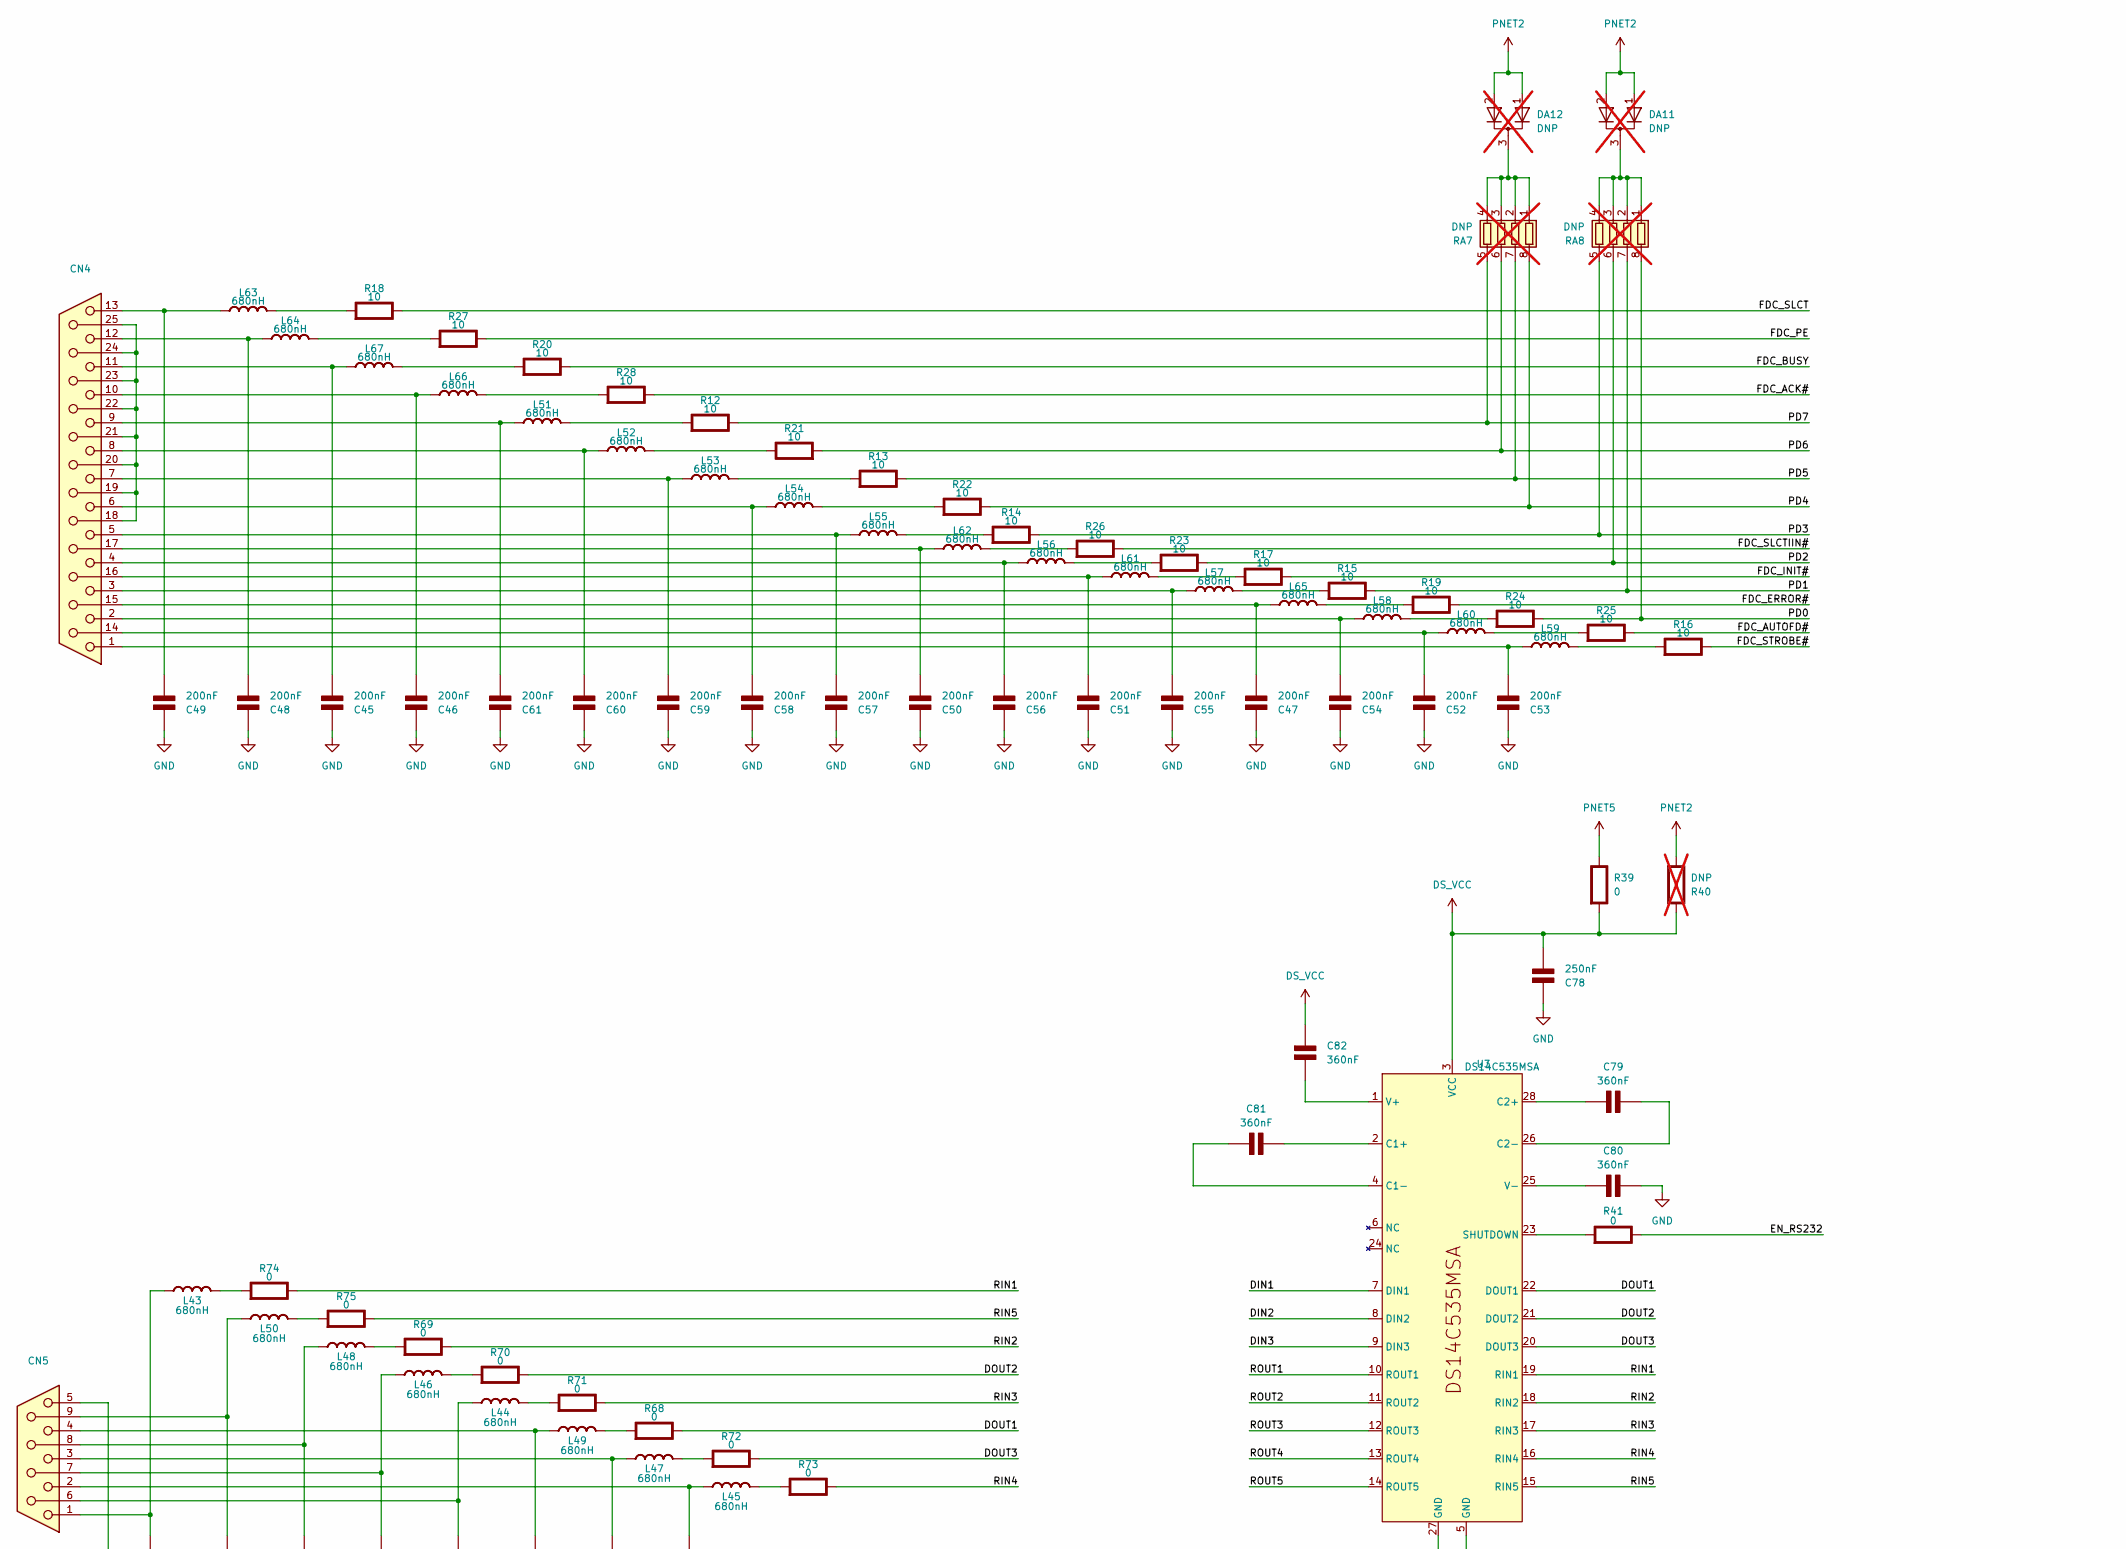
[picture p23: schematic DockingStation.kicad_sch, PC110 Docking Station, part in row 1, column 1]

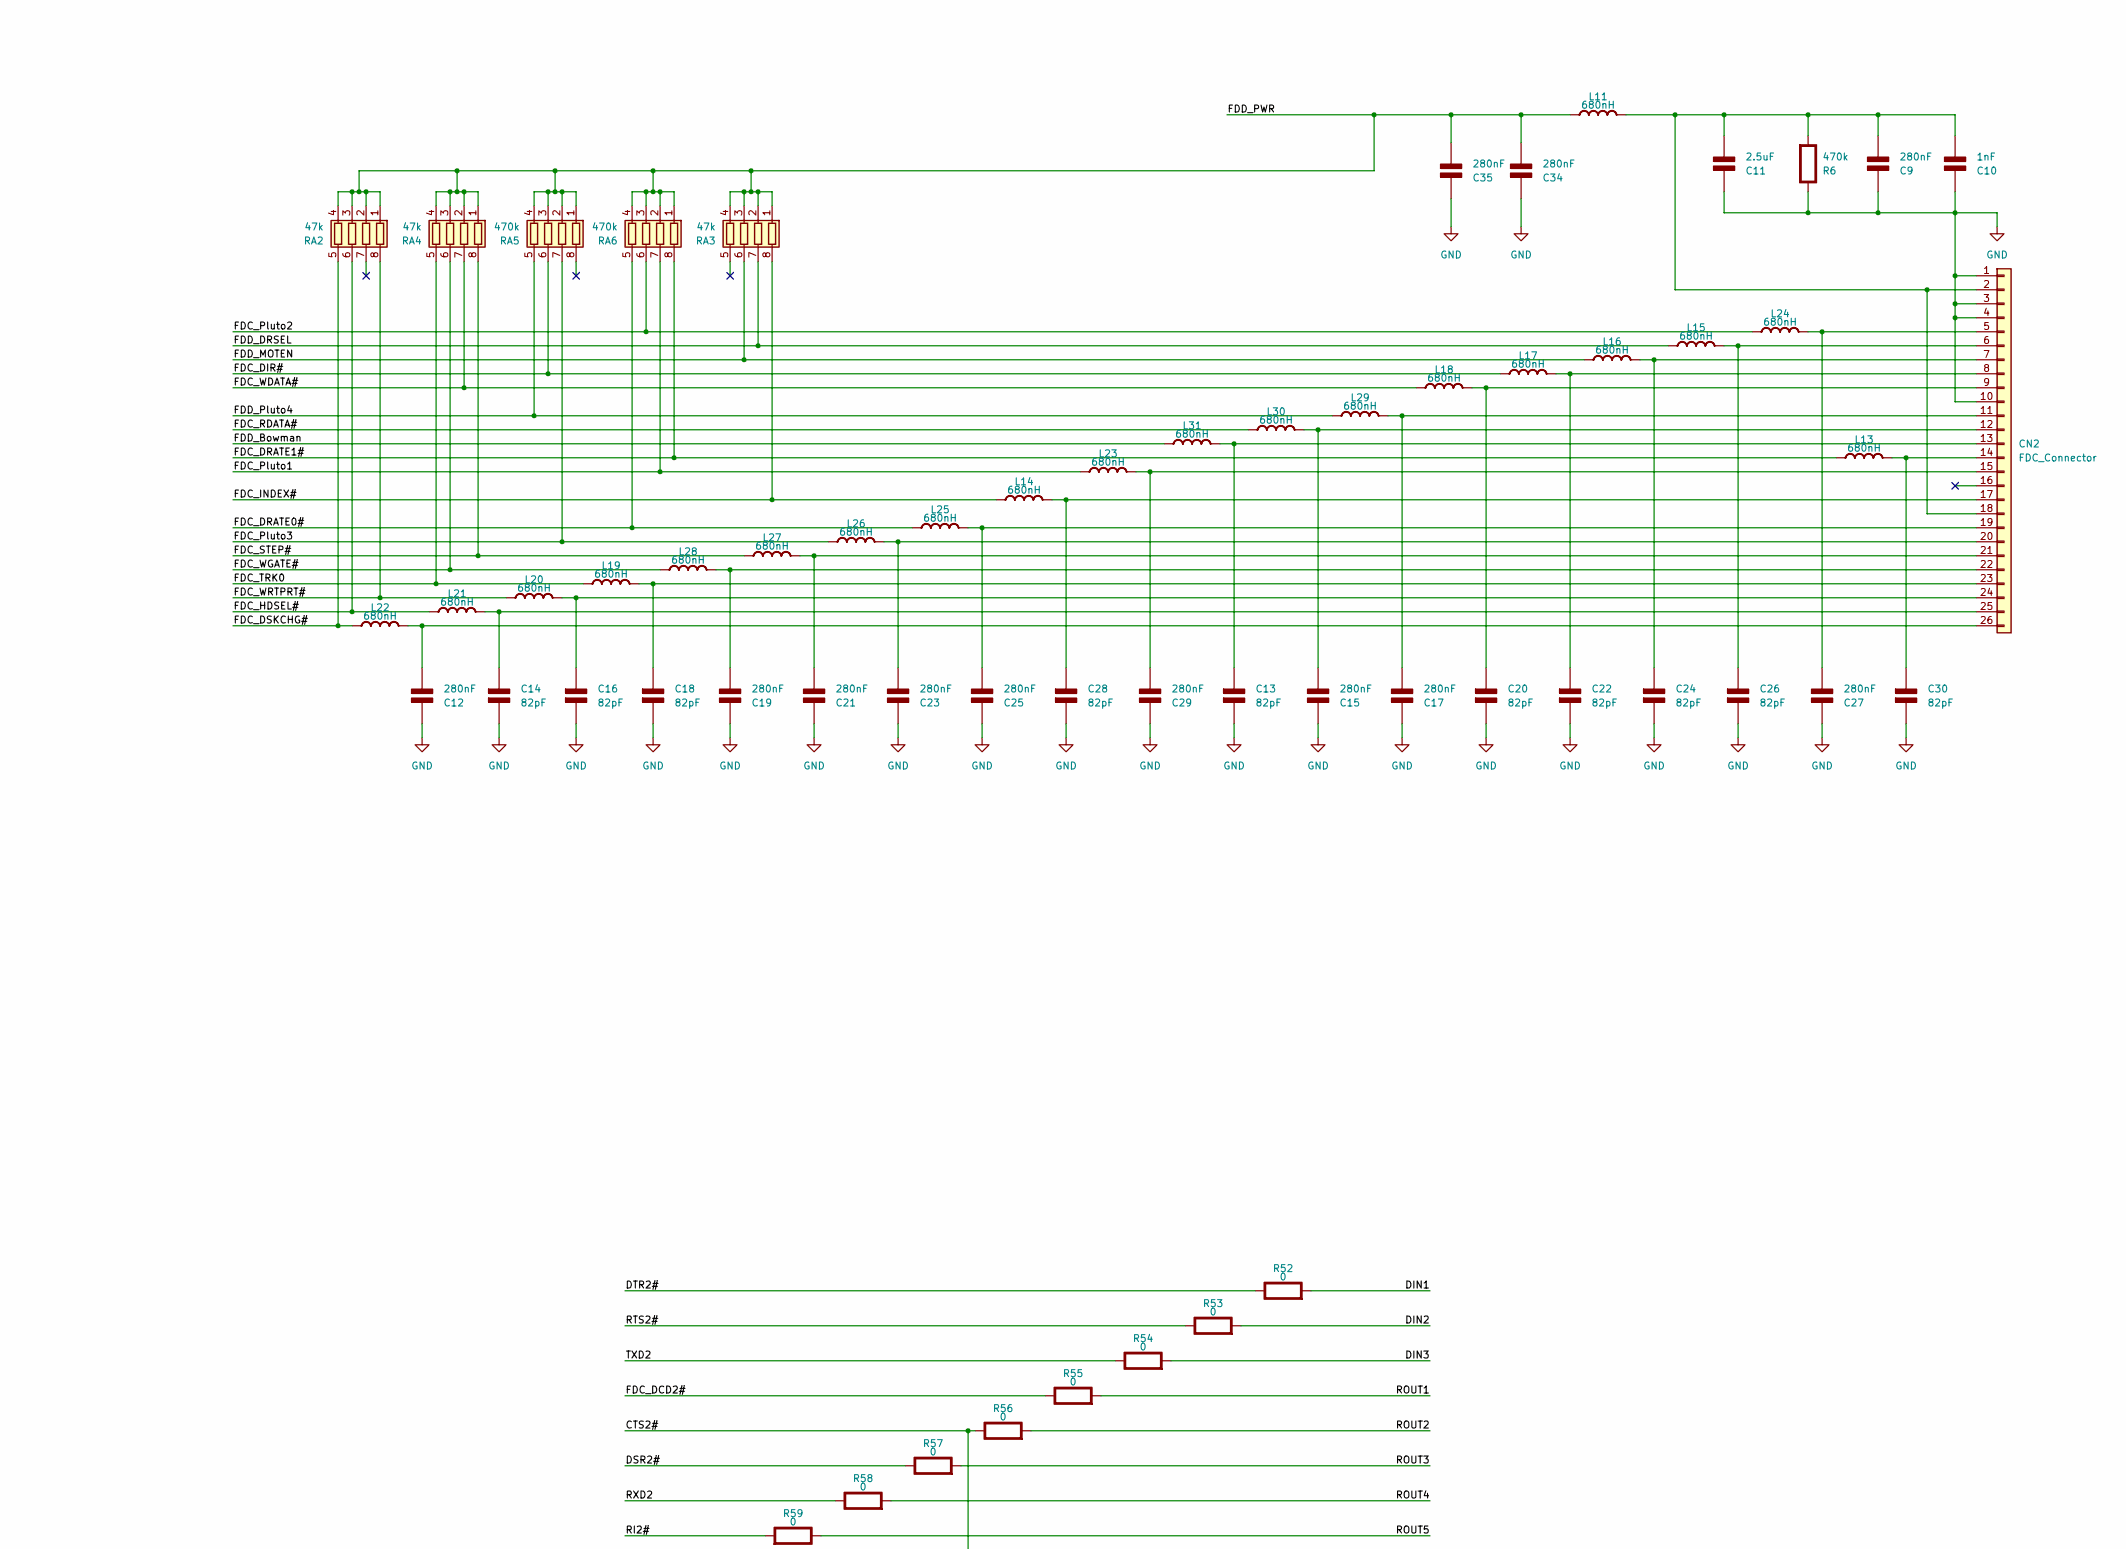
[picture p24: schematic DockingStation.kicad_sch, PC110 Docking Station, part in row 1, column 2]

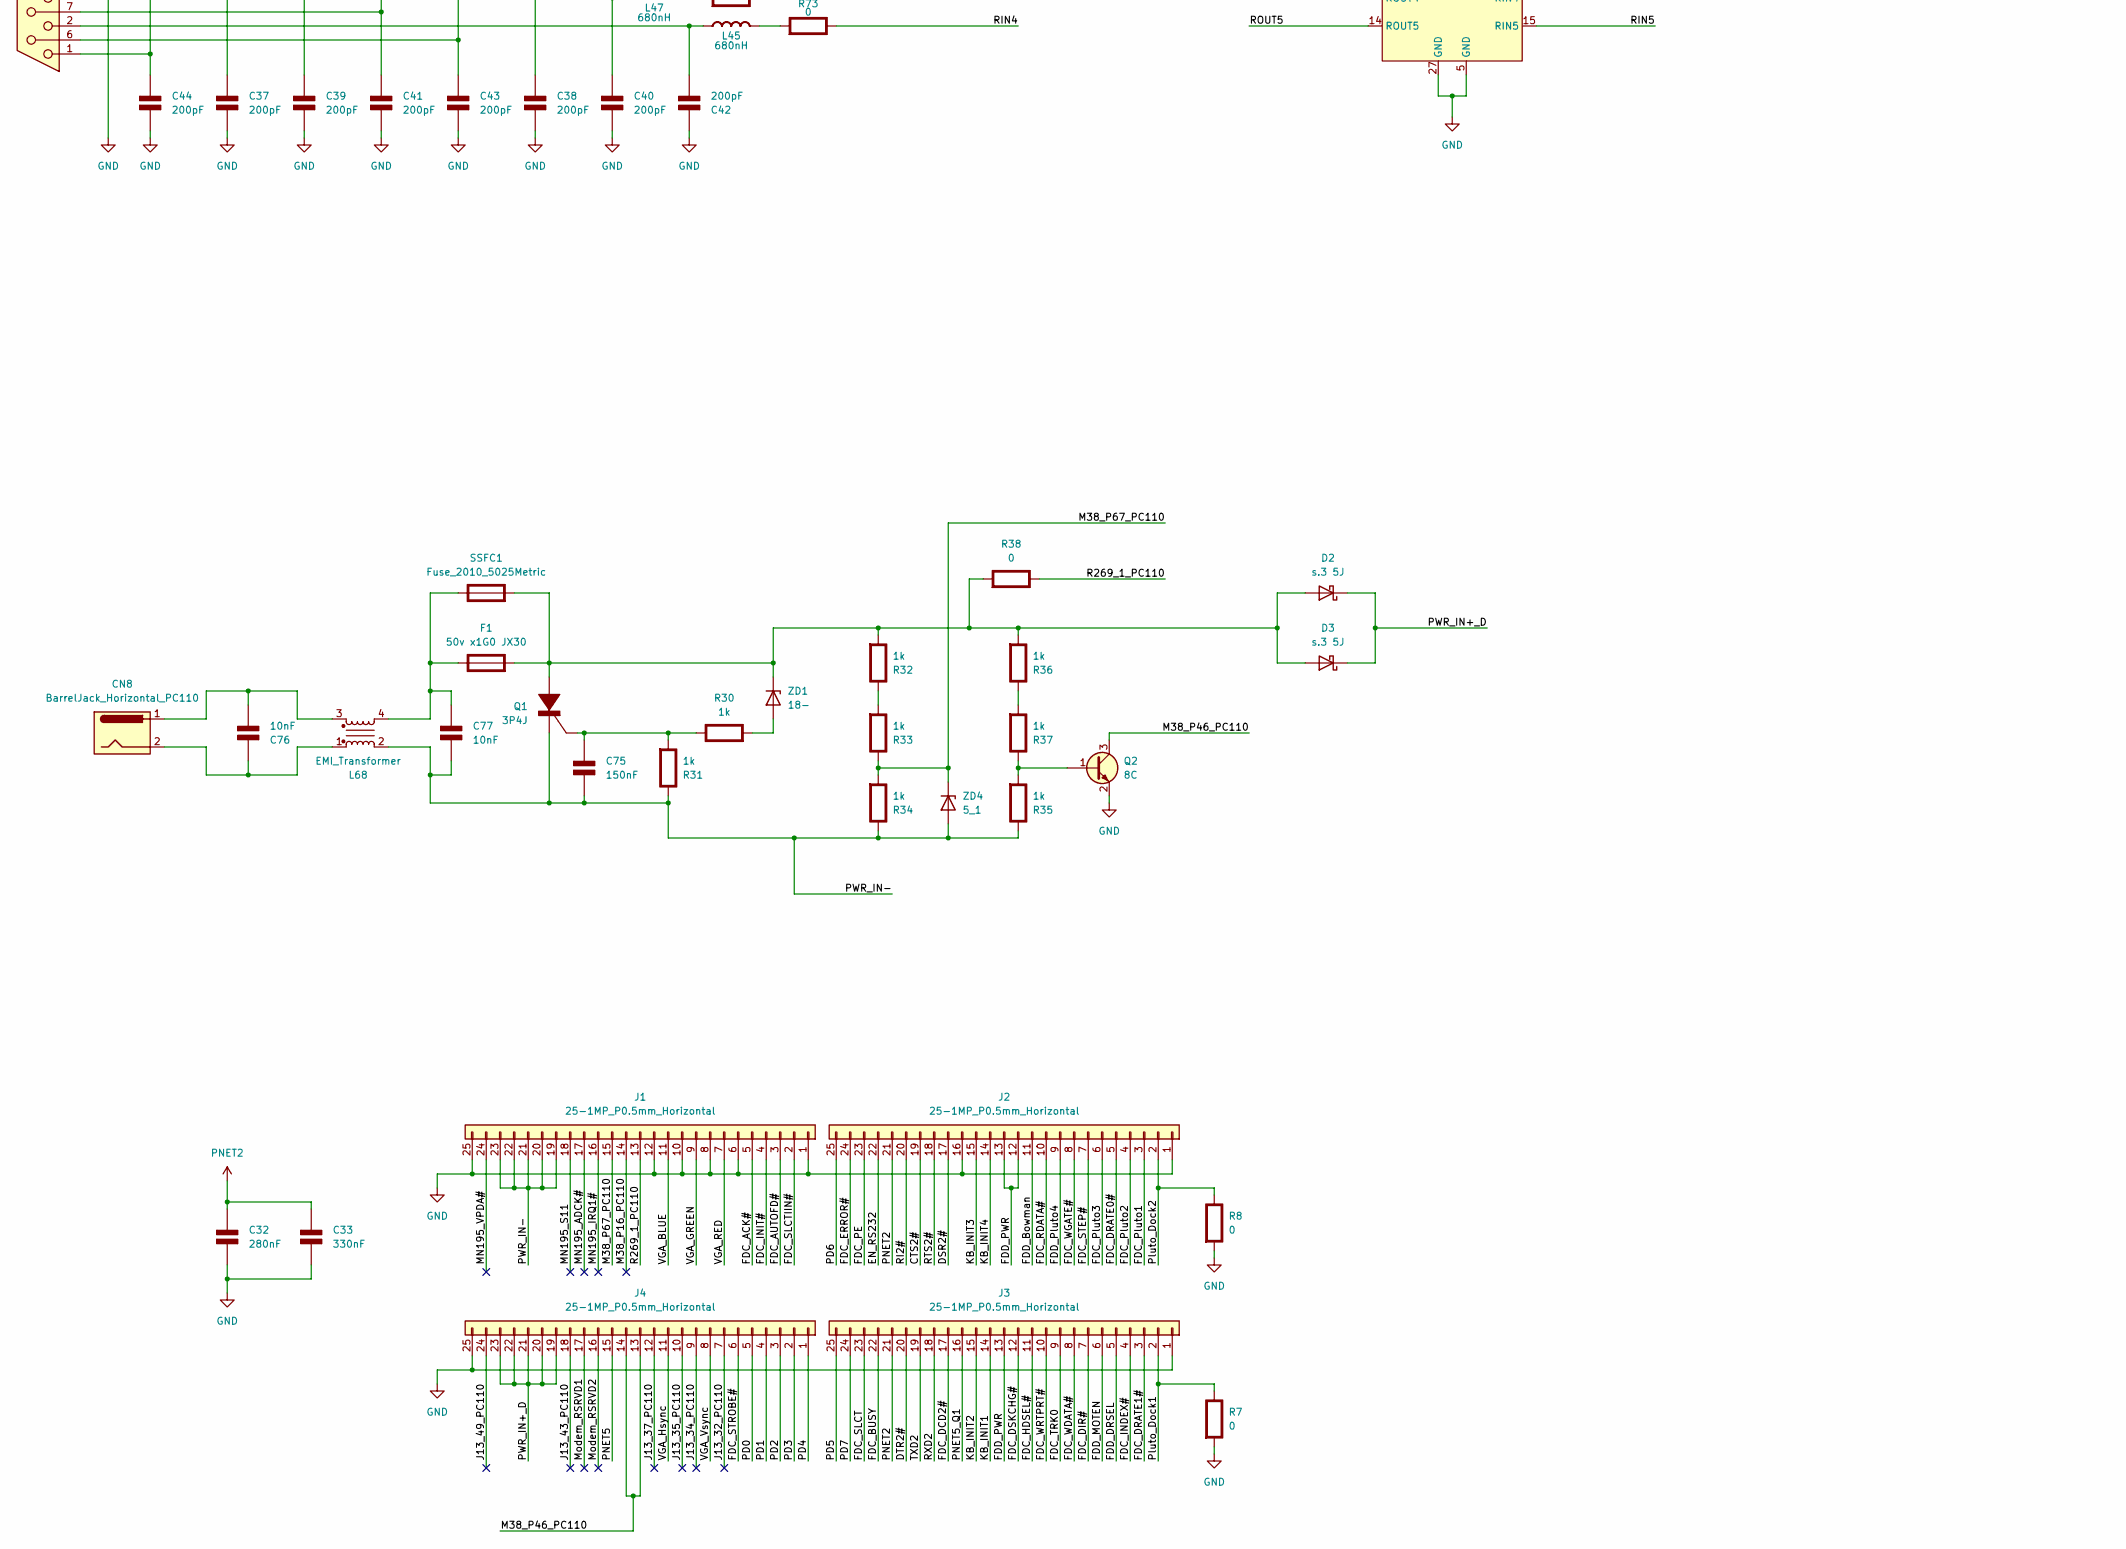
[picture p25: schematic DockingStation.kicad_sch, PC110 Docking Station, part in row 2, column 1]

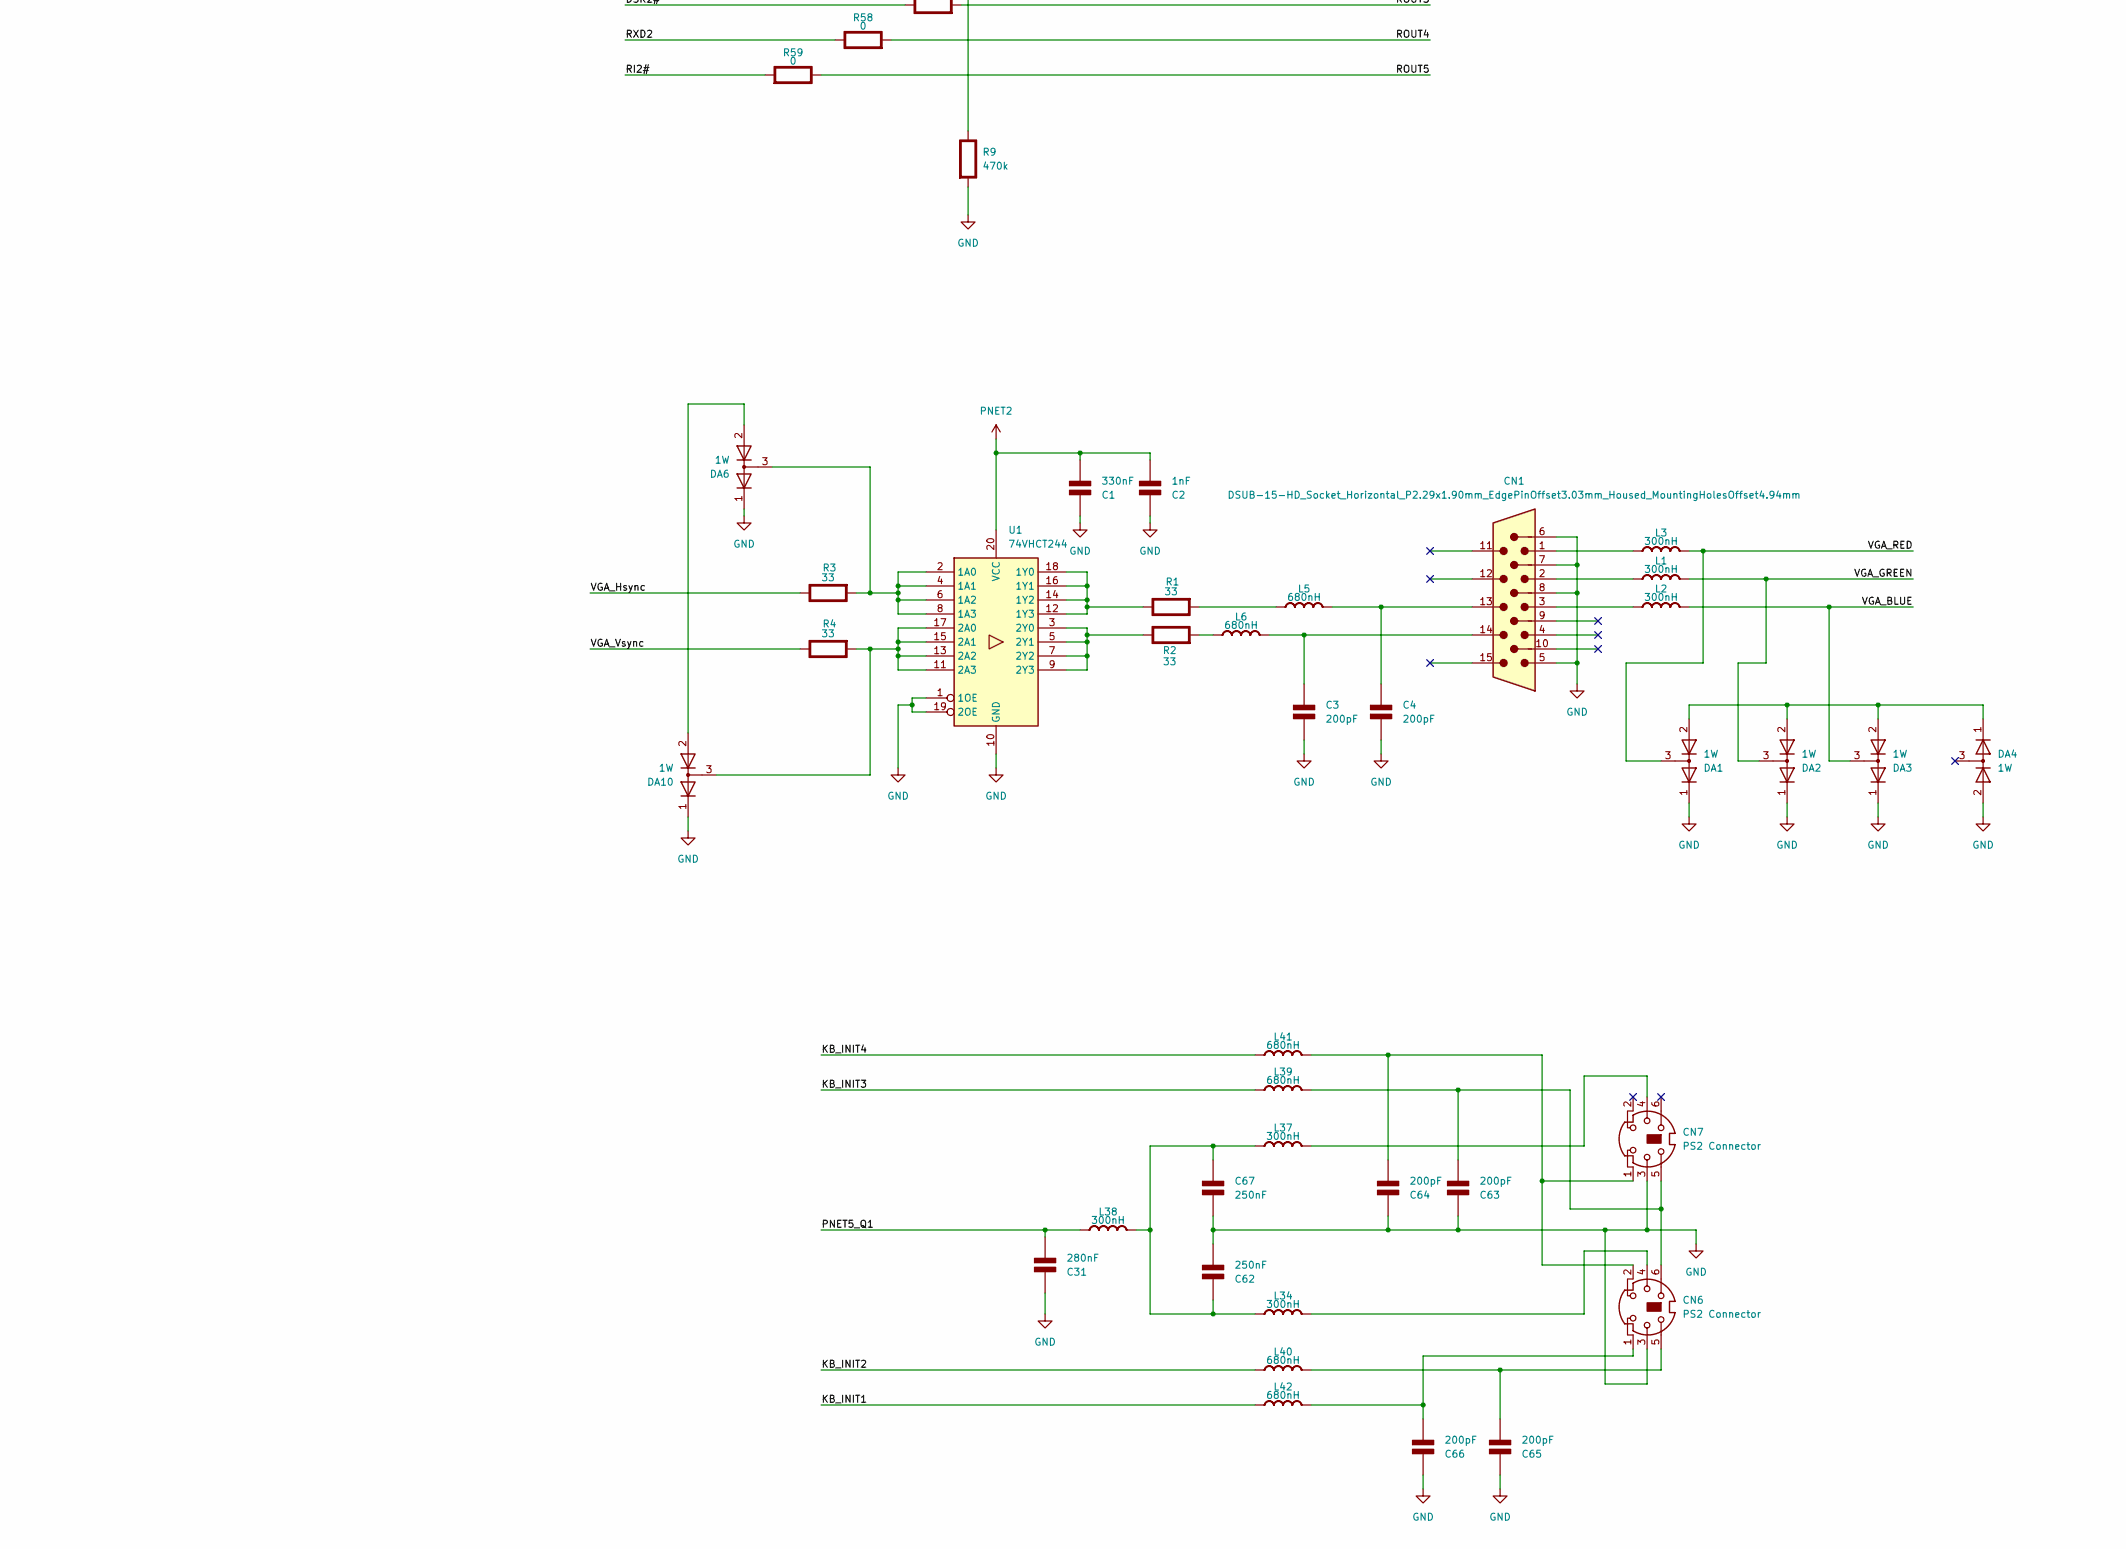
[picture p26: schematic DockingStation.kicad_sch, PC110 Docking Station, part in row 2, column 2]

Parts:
C1: 330nF; C_0805_2012Metric
C2: 1nF; C_0805_2012Metric
C3, C4: 200pF; C_0805_2012Metric
C9, C12, C15, C17, C19, C21, C23, C25, C27, C29, C31, C32, C34, C35: 280nF; C_0603_1608Metric
C10: 1nF; C_0603_1608Metric
C11: 2.5uF; C_1206_3216Metric
C13, C14, C16, C18, C20, C22, C24, C26, C28, C30: 82pF; C_0603_1608Metric
C33: 330nF; C_0603_1608Metric
C37, C38, C39, C40, C41, C42, C43, C44, C63, C64, C65, C66: 200pF; C_0603_1608Metric
C45, C46, C47, C48, C49, C50, C51, C52, C53, C54, C55, C56, C57, C58, C59, C60, C61: 200nF; C_0603_1608Metric
C62, C67, C78: 250nF; C_0603_1608Metric
C75: 150nF; C_0603_1608Metric
C76, C77: 10nF; C_0603_1608Metric
C79, C80, C81, C82: 360nF; C_0805_2012Metric
CN1: DSUB-15-HD_Socket_Horizontal_P2.29x1.90mm_EdgePin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; DSUB-15-HD_Socket_Horizontal_P2.29x1.90mm_EdgePinOffset3.03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
CN2: FDC_Connector
CN4: DSUB-25_Socket_Horizontal_P2.77x2.84mm_EdgePinOff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; DSUB-25_Socket_Horizontal_P2.77x2.84mm_EdgePinOffset4.94mm_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
CN5: DSUB-9_Pins_Horizontal_P2.77x2.84mm_EdgePinOffset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; DSUB-9_Pins_Horizontal_P2.77x2.84mm_EdgePinOffset4.94mm_Hou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
CN6, CN7: PS2 Connector
CN8: BarrelJack_Horizontal_PC110
D2, D3: s.3 5J; D_2010_5025Metric
DA1, DA2, DA3, DA4, DA6, DA10: 1W; SOT-323_SC-70
DA11, DA12: DNP; SOT-23W; not fitted
F1: 50v x1G0 JX30; Fuse_Littelfuse_395Series
J1, J2, J3, J4: 25-1MP_P0.5mm_Horizontal; 25-1MP_P0.5mm_Horizontal_PC110_dock
L1, L2, L3, L34, L37, L38: 300nH; L_0805_2012Metric
L5, L6, L11, L13, L14, L15, L16, L17, L18, L19, L20, L21, L22, L23, L24, L25, L26, L27, L28, L29, L30, L31, L39, L40, L41, L42, L43, L44, L45, L46, L47, L48, L49, L50, L51, L52, L53, L54, L55, L56, L57, L58, L59, L60, L61, L62, L63, L64, L65, L66, L67: 680nH; L_0805_2012Metric
L68: EMI_Transformer
Q1: 3P4J; TO-252-2
Q2: 8C; SOT-323_SC-70
R1, R2: 33; R_0805_2012Metric
R3, R4: 33; R_0603_1608Metric
R6, R9: 470k; R_0603_1608Metric
R7, R8, R39, R41, R52, R53, R54, R55, R56, R57, R58, R59, R68, R69, R70, R71, R72, R73, R74, R75: 0; R_0603_1608Metric
R12, R13, R14, R15, R16, R17, R18, R19, R20, R21, R22, R23, R24, R25, R26, R27, R28: 10; R_0603_1608Metric
R30, R31, R32, R33, R34, R35, R36, R37: 1k; R_0805_2012Metric
R38: 0; R_0805_2012Metric
R40: DNP; R_0603_1608Metric; not fitted
RA2, RA3, RA4: 47k; R_Array_Concave_4x0603
RA5, RA6: 470k; R_Array_Concave_4x0603
RA7, RA8: DNP; R_Array_Concave_4x0603; not fitted
SSFC1: Fuse_2010_5025Metric
U1: 74VHCT244; SSOP-20_4.4x6.5mm_P0.65mm
U3: DS14C535MSA; SSOP-28_5.3x10.2mm_P0.65mm
ZD1: 18-; D_0805_2012Metric
ZD4: 5_1; D_0805_2012Metric

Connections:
/CTS2#: J2.19, R9.1 (+), R56.1 (+)
/DIN1: R52.2 (-), U3.7 (DIN1)
/DIN2: R53.2 (-), U3.8 (DIN2)
/DIN3: R54.2 (-), U3.9 (DIN3)
/DOUT1: R68.1 (+), U3.22 (DOUT1)
/DOUT2: R70.1 (+), U3.21 (DOUT2)
/DOUT3: R72.1 (+), U3.20 (DOUT3)
/DSR2#: J2.17, R57.1 (+)
/DTR2#: J3.20, R52.1 (+)
/EN_RS232: J2.22, R41.1 (+)
/FDC_ACK#: J1.5, R28.1 (+)
/FDC_AUTOFD#: J1.3, R25.1 (+)
/FDC_BUSY: J3.22, R20.1 (+)
/FDC_DCD2#: J3.17, R55.1 (+)
/FDC_DIR#: J3.7, L17.1 (+), RA5.6 (R3.2)
/FDC_DRATE0#: J2.5, L25.1 (+), RA6.5 (R4.2)
/FDC_DRATE1#: J3.3, L13.1 (+), RA6.8 (R1.2)
/FDC_DSKCHG#: J3.12, L22.1 (+), RA2.5 (R4.2)
/FDC_ERROR#: J2.24, R19.1 (+)
/FDC_HDSEL#: J3.11, L21.1 (+), RA2.6 (R3.2)
/FDC_INDEX#: J3.4, L14.1 (+), RA3.8 (R1.2)
/FDC_INIT#: J1.4, R17.1 (+)
/FDC_PE: J2.23, R27.1 (+)
/FDC_Pluto1: J2.3, L23.1 (+), RA6.7 (R2.2)
/FDC_Pluto2: J2.4, L24.1 (+), RA6.6 (R3.2)
/FDC_Pluto3: J2.6, L26.1 (+), RA5.7 (R2.2)
/FDC_RDATA#: J2.10, L30.1 (+)
/FDC_SLCT: J3.23, R18.1 (+)
/FDC_SLCTIIN#: J1.2, R26.1 (+)
/FDC_STEP#: J2.7, L27.1 (+), RA4.8 (R1.2)
/FDC_STROBE#: J4.6, R16.1 (+)
/FDC_TRK0: J3.9, L19.1 (+), RA4.5 (R4.2)
/FDC_WDATA#: J3.8, L18.1 (+), RA4.7 (R2.2)
/FDC_WGATE#: J2.8, L28.1 (+), RA4.6 (R3.2)
/FDC_WRTPRT#: J3.10, L20.1 (+), RA2.8 (R1.2)
/FDD_Bowman: J2.11, L31.2 (-)
/FDD_DRSEL: J3.5, L15.1 (+), RA3.7 (R2.2)
/FDD_MOTEN: J3.6, L16.1 (+), RA3.6 (R3.2)
/FDD_PWR: C34.2 (-), C35.2 (-), J2.12, J2.13, J3.13, L11.1 (+), RA2.1 (R1.1), RA2.2 (R2.1), RA2.3 (R3.1), RA2.4 (R4.1), RA3.1 (R1.1), RA3.2 (R2.1), RA3.3 (R3.1), RA3.4 (R4.1), RA4.1 (R1.1), RA4.2 (R2.1), RA4.3 (R3.1), RA4.4 (R4.1), RA5.1 (R1.1), RA5.2 (R2.1), RA5.3 (R3.1), RA5.4 (R4.1), RA6.1 (R1.1), RA6.2 (R2.1), RA6.3 (R3.1), RA6.4 (R4.1)
/FDD_Pluto4: J2.9, L29.1 (+), RA5.5 (R4.2)
/J13_32_PC110: J4.7
/J13_34_PC110: J4.9
/J13_35_PC110: J4.10
/J13_37_PC110: J4.12
/J13_43_PC110: J4.18
/J13_49_PC110: J4.24
/KB_INIT1: J3.14, L42.2 (-)
/KB_INIT2: J3.15, L40.2 (-)
/KB_INIT3: J2.15, L39.2 (-)
/KB_INIT4: J2.14, L41.2 (-)
/M38_P16_PC110: J1.14
/M38_P46_PC110: J4.13, J4.14, Q2.3 (C)
/M38_P67_PC110: J1.15, R33.1 (+), R34.2 (-), ZD4.1 (K)
/MN195_ADCK#: J1.17
/MN195_IRQ1#: J1.16
/MN195_S11: J1.18
/MN195_VPDA#: J1.24
/Modem_RSRVD1: J4.17
/Modem_RSRVD2: J4.16
/PD0: J4.5, R24.1 (+), RA8.8 (R1.2)
/PD1: J4.4, R15.1 (+), RA8.7 (R2.2)
/PD2: J4.3, R23.1 (+), RA8.6 (R3.2)
/PD3: J4.2, R14.1 (+), RA8.5 (R4.2)
/PD4: J4.1, R22.1 (+), RA7.8 (R1.2)
/PD5: J3.25, R13.1 (+), RA7.7 (R2.2)
/PD6: J2.25, R21.2 (-), RA7.6 (R3.2)
/PD7: J3.24, R12.1 (+), RA7.5 (R4.2)
/PNET5_Q1: C31.2 (-), J3.16, L38.2 (-)
/PWR_IN+_D: D2.1 (K), D3.1 (K), J4.19, J4.20, J4.21, J4.22, J4.23
/PWR_IN-: C75.2 (-), C77.2 (-), J1.19, J1.20, J1.21, J1.22, J1.23, L68.2, Q1.1 (K-), R31.1 (+), R34.1 (+), R35.1 (+), ZD4.2 (A)
/Pluto_Dock1: J3.2, R7.1 (+)
/Pluto_Dock2: J2.2, R8.1 (+)
/R269_1_PC110: J1.13, R38.1 (+)
/RI2#: J2.20, R59.2 (-)
/RIN1: R74.1 (+), U3.19 (RIN1)
/RIN2: R69.1 (+), U3.18 (RIN2)
/RIN3: R71.1 (+), U3.17 (RIN3)
/RIN4: R73.1 (+), U3.16 (RIN4)
/RIN5: R75.1 (+), U3.15 (RIN5)
/ROUT1: R55.2 (-), U3.10 (ROUT1)
/ROUT2: R56.2 (-), U3.11 (ROUT2)
/ROUT3: R57.2 (-), U3.12 (ROUT3)
/ROUT4: R58.2 (-), U3.13 (ROUT4)
/ROUT5: R59.1 (+), U3.14 (ROUT5)
/RTS2#: J2.18, R53.1 (+)
/RXD2: J3.18, R58.1 (+)
/TXD2: J3.19, R54.1 (+)
/VGA_BLUE: DA3.3 (common), J1.11, L2.1 (+)
/VGA_GREEN: DA2.3 (common), J1.9, L1.1 (+)
/VGA_Hsync: J4.11, R3.1 (+)
/VGA_RED: DA1.3 (common), J1.7, L3.1 (+)
/VGA_Vsync: J4.8, R4.1 (+)
DS_VCC: C78.2 (-), C82.1 (+), R39.2 (-), R40.1 (+), U3.3 (VCC)
GND: C1.1 (+), C2.1 (+), C3.2 (-), C4.2 (-), C9.1 (+), C10.1 (+), C11.1 (+), C12.1 (+), C13.2 (-), C14.2 (-), C15.1 (+), C16.2 (-), C17.1 (+), C18.2 (-), C19.1 (+), C20.2 (-), C21.1 (+), C22.2 (-), C23.1 (+), C24.2 (-), C25.1 (+), C26.2 (-), C27.1 (+), C28.2 (-), C29.1 (+), C30.2 (-), C31.1 (+), C32.2 (-), C33.2 (-), C34.1 (+), C35.1 (+), C37.2 (-), C38.2 (-), C39.2 (-), C40.2 (-), C41.2 (-), C42.1 (+), C43.2 (-), C44.2 (-), C45.1 (+), C46.1 (+), C47.1 (+), C48.1 (+), C49.1 (+), C50.1 (+), C51.1 (+), C52.1 (+), C53.1 (+), C54.1 (+), C55.1 (+), C56.1 (+), C57.1 (+), C58.1 (+), C59.1 (+), C60.1 (+), C61.1 (+), C62.2 (-), C63.1 (+), C64.1 (+), C65.1 (+), C66.1 (+), C67.2 (-), C78.1 (+), C80.2 (-), CN1.5, CN1.6, CN1.7, CN1.8, CN2.1, CN2.3, CN2.4, CN2.10, CN5.5, CN6.3, CN7.3, DA1.1 (K), DA2.1 (K), DA3.1 (K), DA4.2 (A), DA6.1 (K), DA10.1 (K), J1.1, J1.6, J1.8, J1.10, J1.12, J1.25, J2.1, J2.16, J3.1, J4.25, Q2.2 (E), R6.1 (+), R7.2 (-), R8.2 (-), R9.2 (-), U1.1 (1OE), U1.10 (GND), U1.19 (2OE), U3.5 (GND), U3.27 (GND)
unnamed: C3.1 (+), CN1.14, L6.2 (-)
unnamed: C4.1 (+), CN1.13, L5.2 (-)
unnamed: C9.2 (-), C10.2 (-), C11.2 (-), CN2.2, CN2.18, L11.2 (-), R6.2 (-)
unnamed: C12.2 (-), CN2.26, L22.2 (-)
unnamed: C13.1 (+), CN2.13, L31.1 (+)
unnamed: C14.1 (+), CN2.25, L21.2 (-)
unnamed: C15.2 (-), CN2.12, L30.2 (-)
unnamed: C16.1 (+), CN2.24, L20.2 (-)
unnamed: C17.2 (-), CN2.11, L29.2 (-)
unnamed: C18.1 (+), CN2.23, L19.2 (-)
unnamed: C19.2 (-), CN2.22, L28.2 (-)
unnamed: C20.1 (+), CN2.9, L18.2 (-)
unnamed: C21.2 (-), CN2.21, L27.2 (-)
unnamed: C22.1 (+), CN2.8, L17.2 (-)
unnamed: C23.2 (-), CN2.20, L26.2 (-)
unnamed: C24.1 (+), CN2.7, L16.2 (-)
unnamed: C25.2 (-), CN2.19, L25.2 (-)
unnamed: C26.1 (+), CN2.6, L15.2 (-)
unnamed: C27.2 (-), CN2.5, L24.2 (-)
unnamed: C28.1 (+), CN2.17, L14.2 (-)
unnamed: C29.2 (-), CN2.15, L23.2 (-)
unnamed: C30.1 (+), CN2.14, L13.2 (-)
unnamed: C37.1 (+), CN5.9, L50.2 (-)
unnamed: C38.1 (+), CN5.4, L49.2 (-)
unnamed: C39.1 (+), CN5.8, L48.2 (-)
unnamed: C40.1 (+), CN5.3, L47.2 (-)
unnamed: C41.1 (+), CN5.7, L46.2 (-)
unnamed: C42.2 (-), CN5.2, L45.2 (-)
unnamed: C43.1 (+), CN5.6, L44.2 (-)
unnamed: C44.1 (+), CN5.1, L43.2 (-)
unnamed: C45.2 (-), CN4.11, L67.2 (-)
unnamed: C46.2 (-), CN4.10, L66.2 (-)
unnamed: C47.2 (-), CN4.15, L65.2 (-)
unnamed: C48.2 (-), CN4.12, L64.2 (-)
unnamed: C49.2 (-), CN4.13, L63.2 (-)
unnamed: C50.2 (-), CN4.17, L62.2 (-)
unnamed: C51.2 (-), CN4.16, L61.2 (-)
unnamed: C52.2 (-), CN4.14, L60.2 (-)
unnamed: C53.2 (-), CN4.1, L59.2 (-)
unnamed: C54.2 (-), CN4.2, L58.2 (-)
unnamed: C55.2 (-), CN4.3, L57.2 (-)
unnamed: C56.2 (-), CN4.4, L56.2 (-)
unnamed: C57.2 (-), CN4.5, L55.2 (-)
unnamed: C58.2 (-), CN4.6, L54.2 (-)
unnamed: C59.2 (-), CN4.7, L53.2 (-)
unnamed: C60.2 (-), CN4.8, L52.2 (-)
unnamed: C61.2 (-), CN4.9, L51.2 (-)
unnamed: C62.1 (+), C67.1 (+), L34.2 (-), L37.2 (-), L38.1 (+)
unnamed: C63.2 (-), CN6.6, CN7.5, L39.1 (+)
unnamed: C64.2 (-), CN6.2, CN7.1, L41.1 (+)
unnamed: C65.2 (-), CN6.5, L40.1 (+)
unnamed: C66.2 (-), CN6.1, L42.1 (+)
unnamed: C75.1 (+), Q1.3 (G), R30.1 (+), R31.2 (-)
unnamed: C76.1 (+), CN8.2, L68.1
unnamed: C76.2 (-), CN8.1, L68.3
unnamed: C77.1 (+), F1.1 (+), L68.4, SSFC1.1 (+)
unnamed: C79.1 (+), U3.28 (C2+)
unnamed: C79.2 (-), U3.26 (C2-)
unnamed: C80.1 (+), U3.25 (V-)
unnamed: C81.1 (+), U3.4 (C1-)
unnamed: C81.2 (-), U3.2 (C1+)
unnamed: C82.2 (-), U3.1 (V+)
unnamed: CN4.18, CN4.19, CN4.20, CN4.21, CN4.22, CN4.23, CN4.24, CN4.25
unnamed: D2.2 (A), D3.2 (A), F1.2 (-), Q1.2 (A+), R32.2 (-), R36.2 (-), R38.2 (-), SSFC1.2 (-), ZD1.1 (K)
unnamed: DA1.2 (A), DA2.2 (A), DA3.2 (A), DA4.1 (K)
unnamed: DA6.3 (common), R3.2 (-), U1.2 (1A0), U1.4 (1A1), U1.6 (1A2), U1.8 (1A3)
unnamed: DA6.2 (A), DA10.2 (A)
unnamed: DA10.3 (common), R4.2 (-), U1.11 (2A3), U1.13 (2A2), U1.15 (2A1), U1.17 (2A0)
unnamed: DA11.3 (K), RA8.1 (R1.1), RA8.2 (R2.1), RA8.3 (R3.1), RA8.4 (R4.1)
unnamed: DA12.3 (K), RA7.1 (R1.1), RA7.2 (R2.1), RA7.3 (R3.1), RA7.4 (R4.1)
unnamed: CN1.2, L1.2 (-)
unnamed: CN1.3, L2.2 (-)
unnamed: CN1.1, L3.2 (-)
unnamed: L5.1 (+), R1.2 (-)
unnamed: L6.1 (+), R2.2 (-)
unnamed: CN6.4, L34.1 (+)
unnamed: CN7.4, L37.1 (+)
unnamed: L43.1 (+), R74.2 (-)
unnamed: L44.1 (+), R71.2 (-)
unnamed: L45.1 (+), R73.2 (-)
unnamed: L46.1 (+), R70.2 (-)
unnamed: L47.1 (+), R72.2 (-)
unnamed: L48.1 (+), R69.2 (-)
unnamed: L49.1 (+), R68.2 (-)
unnamed: L50.1 (+), R75.2 (-)
unnamed: L51.1 (+), R12.2 (-)
unnamed: L52.1 (+), R21.1 (+)
unnamed: L53.1 (+), R13.2 (-)
unnamed: L54.1 (+), R22.2 (-)
unnamed: L55.1 (+), R14.2 (-)
unnamed: L56.1 (+), R23.2 (-)
unnamed: L57.1 (+), R15.2 (-)
unnamed: L58.1 (+), R24.2 (-)
unnamed: L59.1 (+), R16.2 (-)
unnamed: L60.1 (+), R25.2 (-)
unnamed: L61.1 (+), R17.2 (-)
unnamed: L62.1 (+), R26.2 (-)
unnamed: L63.1 (+), R18.2 (-)
unnamed: L64.1 (+), R27.2 (-)
unnamed: L65.1 (+), R19.2 (-)
unnamed: L66.1 (+), R28.2 (-)
unnamed: L67.1 (+), R20.2 (-)
unnamed: Q2.1 (B), R35.2 (-), R37.1 (+)
unnamed: R1.1 (+), U1.12 (1Y3), U1.14 (1Y2), U1.16 (1Y1), U1.18 (1Y0)
unnamed: R2.1 (+), U1.3 (2Y0), U1.5 (2Y1), U1.7 (2Y2), U1.9 (2Y3)
unnamed: R30.2 (-), ZD1.2 (A)
unnamed: R32.1 (+), R33.2 (-)
unnamed: R36.1 (+), R37.2 (-)
unnamed: R41.2 (-), U3.23 (SHUTDOWN)
PNET2: C1.2 (-), C2.2 (-), C32.1 (+), C33.1 (+), DA11.1 (A), DA11.2 (A), DA12.1 (A), DA12.2 (A), J2.21, J3.21, R40.2 (-), U1.20 (VCC)
PNET5: J4.15, R39.1 (+)

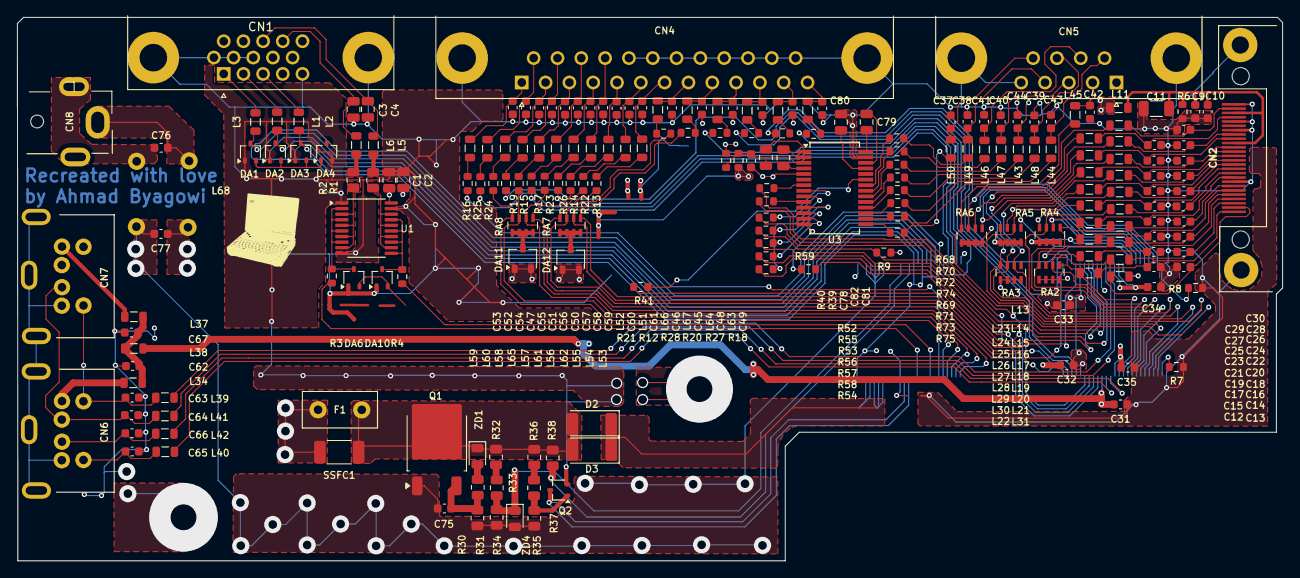
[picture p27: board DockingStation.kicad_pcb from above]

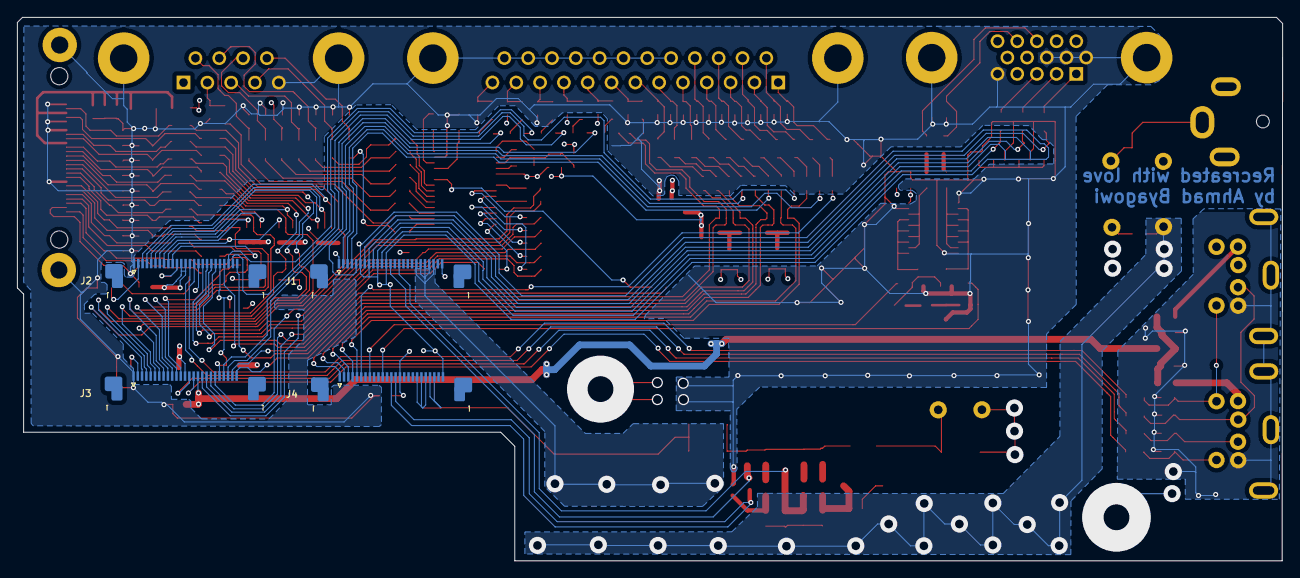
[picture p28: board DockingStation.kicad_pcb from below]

Board: 4 copper layers, 147.2 x 63.2 mm, 218 parts (4 on the bottom side), 192 nets.

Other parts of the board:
G1: LOGO; logo

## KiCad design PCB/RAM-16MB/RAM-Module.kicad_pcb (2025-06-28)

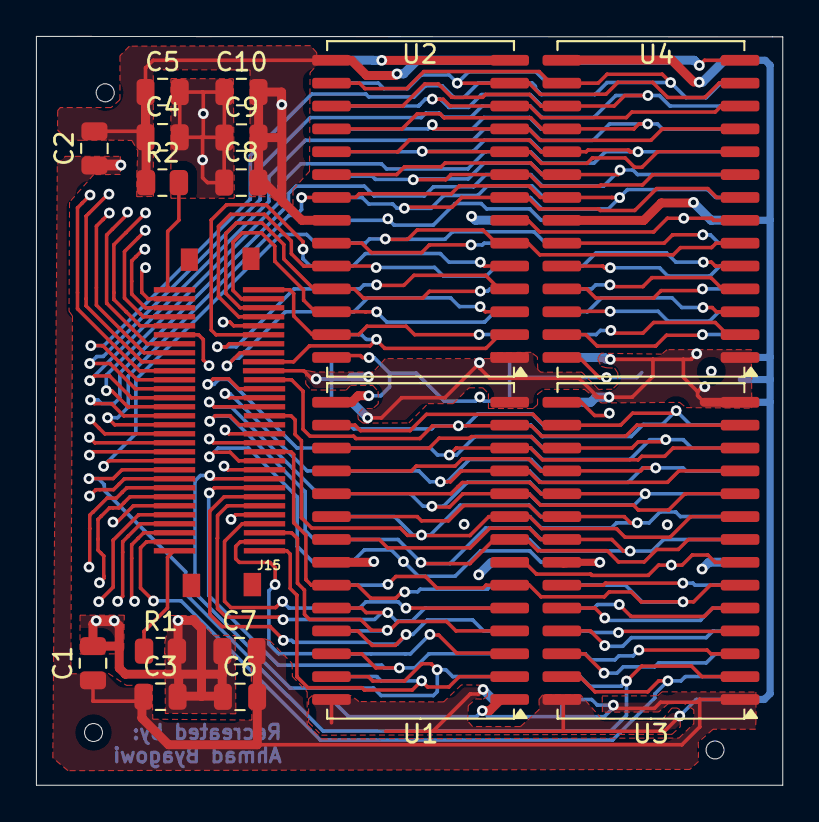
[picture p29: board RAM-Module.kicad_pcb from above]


Board: 4 copper layers, 41.5 x 41.6 mm, 21 parts (4 on the bottom side), 55 nets.

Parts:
C1, C2, C3, C4, C5, C6, C7, C8, C9, C10: 100nF; C_0805_2012Metric
J15: RAM Module
R1, R2: 0; R_0805_2012Metric
U1, U2, U3, U4, U5, U6, U7, U8: 51W17800TT6; SOJ-28_10.16x18.415mm_P1.27mm

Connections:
CPU_D0: J15.1, U1.2, U5.2
CPU_D1: J15.2, U1.3, U5.3
CPU_D2: J15.3, U1.4, U5.4
CPU_D3: J15.4, U1.5, U5.5
CPU_D4: J15.6, U1.24, U5.24
CPU_D5: J15.7, U1.25, U5.25
CPU_D6: J15.8, U1.26, U5.26
CPU_D7: J15.9, U1.27, U5.27
CPU_D8: J15.51, U3.2, U7.2
CPU_D9: J15.52, U3.3, U7.3
CPU_D10: J15.53, U3.4, U7.4
CPU_D11: J15.54, U3.5, U7.5
CPU_D12: J15.56, U3.24, U7.24
CPU_D13: J15.57, U3.25, U7.25
CPU_D14: J15.58, U3.26, U7.26
CPU_D15: J15.59, U3.27, U7.27
CPU_D16: J15.22, U2.2, U6.2
CPU_D17: J15.23, U2.3, U6.3
CPU_D18: J15.24, U2.4, U6.4
CPU_D19: J15.25, U2.5, U6.5
CPU_D20: J15.27, U2.24, U6.24
CPU_D21: J15.28, U2.25, U6.25
CPU_D22: J15.29, U2.26, U6.26
CPU_D23: J15.30, U2.27, U6.27
CPU_D24: J15.32, U4.2, U8.2
CPU_D25: J15.33, U4.3, U8.3
CPU_D26: J15.34, U4.4, U8.4
CPU_D27: J15.35, U4.5, U8.5
CPU_D28: J15.37, U4.24, U8.24
CPU_D29: J15.38, U4.25, U8.25
CPU_D30: J15.39, U4.26, U8.26
CPU_D31: J15.40, U4.27, U8.27
GND: C1.2, C2.2, C3.2, C4.1, C5.1, C6.1, C7.1, C8.2, C9.2, C10.2, J15.10, J15.26, J15.36, J15.55, R1.2, R2.1, U1.15, U1.22, U1.28, U2.15, U2.22, U2.28, U3.15, U3.22, U3.28, U4.15, U4.22, U4.28, U5.15, U5.22, U5.28, U6.15, U6.22, U6.28, U7.15, U7.22, U7.28, U8.15, U8.22, U8.28
PNET1: C1.1, C2.1, C3.1, C4.2, C5.2, C6.2, C7.2, C8.1, C9.1, C10.1, J15.5, J15.14, J15.21, U1.1, U1.14, U2.1, U2.14, U3.1, U3.14, U4.1, U4.14, U5.1, U5.14, U6.1, U6.14, U7.1, U7.14, U8.1, U8.14
RAM_A0: J15.17, U1.10, U2.10, U3.10, U4.10, U5.10, U6.10, U7.10, U8.10
RAM_A1: J15.18, U1.11, U2.11, U3.11, U4.11, U5.11, U6.11, U7.11, U8.11
RAM_A2: J15.19, U1.12, U2.12, U3.12, U4.12, U5.12, U6.12, U7.12, U8.12
RAM_A3: J15.20, U1.13, U2.13, U3.13, U4.13, U5.13, U6.13, U7.13, U8.13
RAM_A4: J15.41, U1.16, U2.16, U3.16, U4.16, U5.16, U6.16, U7.16, U8.16
RAM_A5: J15.42, U1.17, U2.17, U3.17, U4.17, U5.17, U6.17, U7.17, U8.17
RAM_A6: J15.43, U1.18, U2.18, U3.18, U4.18, U5.18, U6.18, U7.18, U8.18
RAM_A7: J15.44, U1.19, U2.19, U3.19, U4.19, U5.19, U6.19, U7.19, U8.19
RAM_A8: J15.45, U1.20, U2.20, U3.20, U4.20, U5.20, U6.20, U7.20, U8.20
RAM_A9: J15.46, U1.21, U2.21, U3.21, U4.21, U5.21, U6.21, U7.21, U8.21
RAM_A10: J15.16, U1.9, U2.9, U3.9, U4.9, U5.9, U6.9, U7.9, U8.9
RAM_A11: J15.15, U1.8, U2.8, U3.8, U4.8, U5.8, U6.8, U7.8, U8.8
RAM_ID0: J15.60, R1.1
RAM_ID1: J15.31, R2.2
RAM_LCASL#: J15.48, U2.23, U6.23
RAM_LCASU#: J15.12, U1.23, U5.23
RAM_RAS2: J15.11, U5.7, U6.7, U7.7, U8.7
RAM_RAS3: J15.49, U1.7, U2.7, U3.7, U4.7
RAM_UCASL#: J15.47, U4.23, U8.23
RAM_UCASU#: J15.13, U3.23, U7.23
RAM_WE#: J15.50, U1.6, U2.6, U3.6, U4.6, U5.6, U6.6, U7.6, U8.6

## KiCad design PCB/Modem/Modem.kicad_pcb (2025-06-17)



Board: 6 copper layers, 64.6 x 58.9 mm, 211 parts (136 on the bottom side), 205 nets.

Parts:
C1, C4, C52, C54: 330nF; C_0603_1608Metric
C2, C34: 1nF; C_0603_1608Metric
C2#2, C15, C32: 1.2uF; C_0603_1608Metric
C3: 30nF; C_0603_1608Metric
C5: 250nF; C_0603_1608Metric
C12, C45: 47uF 16v; C_1812_4532Metric
C13: 822J; C_1206_3216Metric
C23: 1.2uF; C_0805_2012Metric
C24, C37: 230nF; C_0603_1608Metric
C26: 10nF; C_0603_1608Metric
C28: 8.1uF; C_1206_3216Metric
C29, C30: 1.5uF; C_0603_1608Metric
C31: 230nF; C_1206_3216Metric
C38: 2.2uF; C_0603_1608Metric
C39: 100nF; C_0603_1608Metric
C39#2, C48: 25nF; C_0603_1608Metric
C40: 16nF; C_0603_1608Metric
C41, C43: 1uF; C_0603_1608Metric
C42, C51: 1.2nF; C_0603_1608Metric
C46, C47: 24nF; C_0603_1608Metric
C56: 1.6nF; C_0402_1005Metric
C56#2: 470nF; C_0603_1608Metric
C57: 6.8uF; C_1206_3216Metric
C58: 220nF; C_0603_1608Metric
C59, C60, C62: 280nF; C_2220_5750Metric
C70, C72: 1.8uF; C_0603_1608Metric
C71: 1.3uF; C_0805_2012Metric
C73: 100pF; C_0402_1005Metric
C74: 220nF; C_0805_2012Metric
CNP1: Line_Connector
CNP2: modem_heaset_jack
CNP3: JST_8_headset_connector
CNP4: Modem-Connector
CNP5: JST_2_modem_spkr
D1, D7, D9: TO-269AA
D2: 1N4148; D_SOD-128
D3, D4, D8: 5; D_1206_3216Metric_modem
D5: 3D; SOT-323_SC-70
D6: 30H; SOT-23-3
D10: 152; D_1206_3216Metric
DA1: M1T; DA_Modem
IC2, IC7, IC9, IC13, IC17: EA; SOT-353_SC-70-5
IC3: Line-Module
IC4: E5; SOT-353_SC-70-5
IC5: MN195
IC6: 54; SOT-353_SC-70-5
IC8: TA31033F; SOIC-16_4.55x10.3mm_P1.27mm
IC10: AT32 433; TSSOP-14_4.4x5mm_P0.65mm
IC11: EN29F040A; TSOP-I-32_18.4x8mm_P0.5mm_Reverse
IC12: KM681000BLT-7 (I-Reverse); TSOP-I-32_18.4x8mm_P0.5mm_Reverse
IC14: E4; SOT-353_SC-70-5
IC15: 8206 5877; SOIC-8_5.3x6.2mm_P1.27mm
IC16: E3; SOT-353_SC-70-5
IC18: 3L01; TSOT-23-5
L1, L2: 1.2uH; L_1206_3216Metric
L3, L5: 1.8uH; L_0603_1608Metric
L4: 1.2uH; L_0603_1608Metric
NF1: 300nH; L_1206_3216Metric
NF2, NF4: 4.7nH; L_1206_3216Metric
NF3: 0; L_1206_3216Metric
OSC1: 41.472; Oscillator_SMD_Fordahl_DFAS2-4Pin_7.3x5.1mm
PC2: TLP124; Everlight_ITR8307_Reverse
Q1, Q4: CQ; SOT-323_SC-70
Q2: DA QU; SOT-89-3
Q3: 123; SOT-323_SC-70
Q7: SOT-323_SC-70
Q9: HP; SOT-323_SC-70
R1: 12k; R_0402_1005Metric
R2, R3, R28, R29, R30, R31, R32, R36, R37, R38, R41, R43: 4.7k; R_0402_1005Metric
R4: 330; R_0402_1005Metric
R5: 100; R_0603_1608Metric
R6: 3.3k; R_0603_1608Metric
R7, R26, R33, R34: 10; R_1206_3216Metric
R8: 22k; R_0402_1005Metric
R9, R20, R63, R81: 100k; R_0402_1005Metric
R10, R11, R68: 38k; R_0402_1005Metric
R12, R75: 2.2k; R_2010_5025Metric
R13, R16, R17, R19, R21, R47, R49, R62, R67, R82, R133: 10k; R_0402_1005Metric
R14: 560k; R_0402_1005Metric
R15: 330k; R_0402_1005Metric
R18, R46: 1.5k; R_0402_1005Metric
R22, R23, R27: DNP; R_0402_1005Metric
R24: 200; R_0603_1608Metric
R25: 500k; R_0402_1005Metric
R35: 20; R_1206_3216Metric
R42: 15k; R_0402_1005Metric
R44: 51; R_0402_1005Metric
R48: 3.3; R_1206_3216Metric
R50: 6.2k; R_0603_1608Metric
R51, R72, R72#2, R90, R100: 470k; R_0402_1005Metric
R52, R70, R71: 1k; R_0402_1005Metric
R53: 11k; R_0603_1608Metric
R54: 1.5k; R_0603_1608Metric
R55: 82; R_2010_5025Metric
R56: 15; R_1206_3216Metric
R57: 150; R_0603_1608Metric
R58: 620; R_0603_1608Metric
R59, R60: 2.2k; R_0402_1005Metric
R61: 3.6k; R_0402_1005Metric
R65: 15; R_0402_1005Metric
R68#2: 20k; R_0402_1005Metric
R73: 120; R_0603_1608Metric
R76: 2.4k; R_0402_1005Metric
R77: 270k; R_0402_1005Metric
R78: 5.6k; R_0402_1005Metric
R92: 47k; R_0402_1005Metric
R98, R99: 100; R_0805_2012Metric
R101, R102, R103, R104, R105, R106, R107, R108, R109, R110, R111, R112, R114, R115, R116, R117, R118, R119, R120, R121, R122, R123, R124, R124#2, R125, R126, R127, R129, R130, R131, R132: 100; R_0402_1005Metric
RL1: RL
SW2: SW_modem
T1: IsoTransformer
VA1: R_2512_6332Metric

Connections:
29FA7: IC11.20, IC12.13, R119.1
29F_A0: IC11.13, IC12.20, R111.1
29F_A1: IC11.14, IC12.19, R122.1
29F_A2: IC11.15, IC12.18, R110.1
29F_A3: IC11.16, IC12.17, R121.1
29F_A4: IC11.17, IC12.16, R109.1
29F_A5: IC11.18, IC12.15, R120.1
29F_A6: IC11.19, IC12.14, R108.1
29F_A8: IC11.30, IC12.3, R107.1
29F_A9: IC11.31, IC12.2, R118.1
29F_A10: IC11.2, IC12.31, R106.1
29F_A11: IC11.32, IC12.1, R117.1
29F_A12: IC11.21, IC12.12, R105.1
29F_A13: IC11.29, IC12.4, R116.1
29F_A14: IC11.28, IC12.11, R104.1
29F_A15: IC11.22, IC12.7, R115.1
29F_A16: IC11.23, IC12.10, R103.1
29F_A17: IC11.27, R114.1
29F_A18: IC11.24, R102.1
29F_CE#: IC11.3, R101.1
29F_DQ0: IC11.12, IC12.21, R28.2, R125.1
29F_DQ1: IC11.11, IC12.22, R29.2, R126.1
29F_DQ2: IC11.10, IC12.23, R30.2, R127.1
29F_DQ3: IC11.8, IC12.25, R31.2, R124#2.1
29F_DQ4: IC11.7, IC12.26, R32.2, R129.1
29F_DQ5: IC11.6, IC12.27, R36.2, R130.1
29F_DQ6: IC11.5, IC12.28, R37.2, R131.1
29F_DQ7: IC11.4, IC12.29, R38.2, R132.1
29F_OE#: IC11.1, IC12.32, R123.1
29F_WE#: IC11.26, IC12.5, R124.1
C32_1: C32.1, IC3.8
C32_2: C32.2, R76.1
C39_1: C39.1, R60.2
C40_2: C40.2, R62.2
C51_1: C51.1, R70.1, R71.2
C52_2: C52.2, C54.1, C56.1, D6.1, D7.2, IC15.5, PC2.3, R42.2, R82.1
C70_1: C70.1, IC17.4, R100.1
C70_2: C70.2, DA1.1, DA1.4
C72_1: C72.1, IC3.12, R99.2
C74_1: C74.1, IC17.5, R98.1
CNP2_2: CNP2.2, CNP3.3
CNP2_3: CNP2.3, L4.2
CNP3_1: CNP2.4, CNP3.1
CNP3_5: CNP3.5, R78.2
CNP5_1: CNP5.1, SW2.3
CNP5_2: CNP3.6, CNP5.2
D1_1: D1.1, D2.1, Q1.3, Q2.2, R20.1
D1_2: C15.1, D1.2, R7.2, R9.1
D2_2: C15.2, D2.2, Q1.1, R9.2, R20.2
D4_1: D4.1, IC2.4, IC7.2
D7_1: C54.2, D6.3, D7.1, IC15.1
D7_3: C59.1, C60.1, D7.3
DA1_2: C71.1, DA1.2, R99.1
FDC_CTS1#: CNP4.8, IC10.5, R23.2
FDC_DCD1_PC110: CNP4.4, IC5.65
FDC_DIR1#_PC110: CNP4.6, IC5.54
FDC_DSR1_PC110: CNP4.7, IC5.51
FDC_RI1_PC110: CNP4.5, IC10.2, R22.2
FDC_RTS1#_PC110: CNP4.9, IC5.53
FDC_RXD1_PC110: CNP4.10, IC5.52
FDC_TXD1_PC110: CNP4.11, IC9.4
GND: C5.1, C23.1, C24.2, C28.1, C29.1, C30.2, C31.1, C37.2, C39#2.2, C46.1, C47.2, C48.1, C58.2, CNP3.8, CNP4.1, CNP4.13, CNP4.14, CNP4.26, IC2.3, IC4.3, IC5.10, IC5.14, IC5.19, IC5.24, IC5.43, IC5.44, IC5.76, IC5.112, IC6.3, IC7.3, IC9.3, IC10.1, IC10.4, IC10.7, IC10.9, IC10.12, IC10.13, IC11.9, IC12.24, IC13.3, IC14.3, IC16.3, IC18.3, NF4.2, OSC1.4, Q7.2, R2.1, R51.1, R67.1, R81.1
IC3_15: IC3.15, T1.3
IC6_2: IC4.4, IC6.2
IC7_4: IC7.4, R14.1
IC8_3: IC8.3, R55.2, R56.1, R57.1
IC8_5: C2#2.1, IC8.5
IC8_7: C43.2, IC8.7, R63.2
IC8_9: C41.1, IC8.9, R68.1
IC8_10: C42.2, IC8.10, R63.1
IC8_11: C41.2, IC8.11, R62.1, R68.2
IC8_12: IC8.12, R13.1
IC8_13: C38.1, IC8.13, R59.1, R60.1
IC8_14: C38.2, IC8.14, R59.2
IC8_15: C13.1, IC8.15, R4.2
IC8_16: C12.2, IC8.16, R13.2, R58.1, R70.2
IC9_2: C5.2, IC9.2, R14.2
IC10_6: IC10.6, R17.1
IC10_8: IC10.8, R19.2
IC12_3: IC12.30, R112.1
IC13_2: C37.1, IC13.2, R24.1, R25.2
IC13_4: D8.1, IC13.4, IC16.2
IC14_1: IC14.1, Q7.3, R90.2
IC14_4: IC14.4, R46.1
IC15_2: IC15.2, R42.1
IC15_3: C52.1, IC15.3, R77.2
IC15_4: IC15.4, R77.1
IC15_6: IC15.6, R15.1
IC15_7: C56.2, IC15.7, R15.2
IC15_8: C56#2.2, IC15.8, R68#2.1, R78.1
IC16_1: D3.1, IC16.1, R2.2
IC16_4: IC14.2, IC16.4
IC17_2: C73.2, IC17.2, R100.2
IC18_2: C58.1, D5.1, D5.2, IC18.2, R49.2
IREF2: C34.2, IC5.31
L1_1: D1.4, D7.4, D9.4, L1.2, T1.1, VA1.1
L1_2: L2.2, R12.1, R75.2, RL1.6, RL1.8, VA1.2
L3_1: C42.1, L3.1, R71.1
L3_2: CNP2.1, L3.2
L4_1: L4.1, R65.1
L5_2: CNP2.5, L5.2
MN192_S11_BUF: CNP4.22, Q4.2, R52.2
MN195_A0: IC5.128, R111.2
MN195_A1: IC5.127, R122.2
MN195_A2: IC5.126, R110.2
MN195_A3: IC5.125, R121.2
MN195_A4: IC5.124, R109.2
MN195_A5: IC5.123, R120.2
MN195_A6: IC5.122, R108.2
MN195_A7: IC5.121, R119.2
MN195_A8: IC5.120, R107.2
MN195_A9: IC5.119, R118.2
MN195_A10: IC5.118, R106.2
MN195_A11: IC5.117, R117.2
MN195_A12: IC5.116, R105.2
MN195_A13: IC5.115, R116.2
MN195_A14: IC5.114, R104.2
MN195_A15: IC5.111, R115.2
MN195_A16: IC5.110, R103.2
MN195_A17: IC5.109, R114.2
MN195_A18: IC5.108, R102.2
MN195_ADCK#: CNP4.21, IC5.21, IC5.95
MN195_AGCIN: IC3.18, IC5.28
MN195_AGCOUT: IC3.17, IC5.27
MN195_CX: IC5.11, R44.1
MN195_DVDD1: C23.2, C39#2.1, C46.2, C47.1, C48.2, IC5.13, IC5.25, IC5.77, IC5.113, R26.1, R33.1, R34.1
MN195_HDRES#: IC5.12, IC18.1, R51.2
MN195_HPOUT: IC3.6, IC5.29
MN195_HVDD: IC3.2, IC5.33
MN195_IREF0: IC5.38, R10.1
MN195_IREF1: C2.1, IC5.37, R10.2, R11.1
MN195_IRQ1#: CNP4.20, IC5.67, R3.1
MN195_IRQ2#: IC5.68, R43.2
MN195_MD0: IC5.8, R125.2
MN195_MD1: IC5.7, R126.2
MN195_MD2: IC5.6, R127.2
MN195_MD3: IC5.5, R124#2.2
MN195_MD4: IC5.4, R129.2
MN195_MD5: IC5.3, R130.2
MN195_MD6: IC5.2, R131.2
MN195_MD7: IC5.1, R132.2
MN195_MOD1,3: IC5.42, IC5.45, R41.2
MN195_MTA1: IC3.11, IC5.92
MN195_PLSD: IC3.1, IC5.23
MN195_RD#: IC5.16, R123.2
MN195_RXL: IC3.3, IC5.32
MN195_S0: IC5.46, IC6.1, R21.2, R92.1
MN195_S1: IC3.4, IC5.47
MN195_S2: IC4.2, IC5.48, R47.2
MN195_S3: D4.2, IC5.49, R72.2
MN195_S4: IC3.5, IC5.50
MN195_S9: IC5.55, R16.2, R22.1
MN195_S10: IC5.56, R17.2, R23.1
MN195_S11: IC5.57, Q3.1, R133.2
MN195_S12: D3.2, IC5.58, R67.2
MN195_S13: D8.2, IC5.59, R72#2.2
MN195_SHIN: IC3.16, IC5.26
MN195_TXLPIN: C2.2, IC3.9, IC5.36, R11.2
MN195_TXOUT: IC3.10, IC5.34
MN195_U1RD#: IC5.63, R19.1, R27.2
MN195_U1RD#_R: CNP4.3, IC10.10, R27.1
MN195_UC0#: IC5.99, R101.2
MN195_UC1: IC5.100, R112.2
MN195_VPCK#: CNP4.18, IC5.87
MN195_VPDA#: CNP4.19, IC5.88
MN195_VREEH: C45.2, IC5.39, IC5.40, R35.2
MN195_VSDA#: CNP4.17, IC5.96
MN195_VSEN#: CNP4.16, IC5.98
MN195_WR#: IC5.15, R124.2
NF1_1: NF1.1, R35.1
NF2_1: NF2.1, R26.2, R33.2, R34.2
OSC1_1: OSC1.1, R44.2
OSC1_2: C24.1, NF3.1, OSC1.2
PC2_1: PC2.1, R68#2.2
PNET1: C57.2, IC3.13, NF1.2, Q4.3, R1.2, R48.1, R98.2
PNET4: C45.1, C57.1, C71.2, C72.2, C73.1, C74.2, DA1.3, IC3.7, IC3.14, IC5.35, IC5.41, IC17.3, NF4.1, Q3.2, R8.1, R52.1, T1.2
Pluto_Enabled_PNET5: C31.2, CNP4.12, CNP4.15, IC2.5, IC7.5, IC9.5, IC13.5, IC14.5, IC16.5, PC2.2, R25.1, RL1.1
Q2_1: Q1.2, Q2.1, Q2.3, R7.1
Q3_3: Q3.3, Q4.1, R1.1, R8.2, R76.2
Q7_1: Q7.1, R92.2
Q9_1: Q9.1, R6.1
R6_2: R5.1, R6.2
R12_2: C62.2, R12.2
R16_1: IC10.3, R16.1
R24_2: CNP3.7, R24.2
R54_1: D9.1, D10.1, IC8.1, Q9.2, R5.2, R50.1, R54.1, R58.2
R54_2: C26.2, R53.2, R54.2
R55_1: Q9.3, R55.1
R56_2: C2#2.2, C12.1, C40.1, C43.1, C51.2, CNP3.2, CNP3.4, D9.2, D10.2, IC8.8, L5.1, R4.1, R56.2
R57_2: C26.1, C39.2, R50.2, R53.1, R57.2
R61_2: C56#2.1, R61.2
R65_2: C13.2, R65.2
R73_2: IC2.2, R73.2, R81.2
R75_1: C59.2, C60.2, R75.1
R82_2: R61.1, R82.2, SW2.2
RL1_2: R46.2, RL1.2
RL1_3: R18.2, RL1.3
RL1_4: IC6.4, RL1.4
RL1_5: C1.1, C3.1, C4.1, C62.1, D1.3, RL1.5
RL1_7: D9.3, RL1.7
T1_4: C1.2, C3.2, C4.2, T1.4
TEL_GND: CNP1.2, CNP1.3, CNP1.4, L2.1
TEL_Line: CNP1.1, L1.1
TLP124_4: PC2.4, R73.1
VCC_PC110: C28.2, C29.2, C30.1, CNP4.2, CNP4.25, D5.3, IC4.5, IC6.5, IC10.14, IC11.25, IC12.6, IC12.8, NF2.2, NF3.2, R3.2, R18.1, R21.1, R28.1, R29.1, R30.1, R31.1, R32.1, R36.1, R37.1, R38.1, R41.1, R43.1, R47.1, R48.2, R49.1, R72.1, R72#2.1, R90.1, R133.1

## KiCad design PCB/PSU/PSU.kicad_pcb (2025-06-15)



Board: 4 copper layers, 72.3 x 45.0 mm, 258 parts (87 on the bottom side), 155 nets.

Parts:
C1, C5, C7, C16, C24, C28, C36, C46, C47, C59: 150nF; C_0603_1608Metric
C2: 4.7nF; C_0603_1608Metric
C3: 5.2uF; C_1206_3216Metric
C4: 2.5nF; C_0603_1608Metric
C6, C20: 100pF; C_0603_1608Metric
C8, C33: 24nF; C_0603_1608Metric
C9, C17, C22, C26, C29, C30, C32, C39, C40, C48: 10nF; C_0603_1608Metric
C10: 3.6nF; C_0603_1608Metric
C11, C15, C37, C44, C49: 180nF; C_0603_1608Metric
C12: 1.2uF; C_1206_3216Metric
C13, C14: 1.5uF; C_1206_3216Metric
C18, C42, C51, C53, C64: 120nF; C_0603_1608Metric
C19: 18nF; C_0603_1608Metric
C21: 12nF; C_0603_1608Metric
C23, C34, C38, C41, C55, C58: 1.5uF; C_0805_2012Metric
C25, C27, C31, C35, C66: 1.2nF; C_0603_1608Metric
C43: 10pF; C_0603_1608Metric
C45: 33uF 20V; C_Disc_D3.0mm_W1.6mm_P2.50mm
C50: 56uF 25V EC; EC
C52, C60: 1nF; C_0603_1608Metric
C54, C61: 47uF 6.3v; C_Radial_D6.3mm_H11.0mm_P2.50mm
C56: 47uF 6.3V; C_Radial_D6.3mm_H11.0mm_P2.50mm
C57: 15uF 16V; C_Radial_D6.3mm_H11.0mm_P2.50mm
C62, C65: 100nF; C_0603_1608Metric
C63: 5.1nF; C_0603_1608Metric
C67: 18uF 50V; C_Radial_D6.3mm_H11.0mm_P2.50mm
D1: 8-2; D_0603_1608Metric
D2: 5-9; D_0603_1608Metric
D3, D6: DNP; D_1206_3216Metric
D4: 18; D_0603_1608Metric
D5: 3^9; D_0603_1608Metric
D7, D8: s.3 4F; D_1206_3216Metric
F1, F5: 2.5A; Fuse_2010_5025Metric
F2: 830mA; Fuse_2010_5025Metric
F3: 15; Fuse_1206_3216Metric
F4: 10; Fuse_1210_3225Metric
G1: LOGO; logo
J1: Backllight_Connector
J2: PSU_Jack
J3: PSU_Connector_Receptor
L1: 10uH; L_Radial_D7.5mm_P5.00mm_Fastron_07P
L2, L5: 10uH; L_Radial_D10.0mm_P5.00mm_Fastron_07M
L3: 68uH; L_Coilcraft_LPS5030
L4: 470uH; L_Coilcraft_LPS5030
Q1: R4C; 3D
Q2, Q32: K; 3D
Q3, Q6, Q7, Q11, Q14, Q24, Q34: 6LS; SOT-416
Q4, Q13, Q15, Q33, Q37: 8LR; SOT-416
Q5, Q21, Q22, Q23, Q27, Q30, Q35: 8C; SOT-416
Q8: 303 5H; SOT-powerT
Q9: KD 3.E; SOT-89-3
Q10: 103 5G; SOT-powerT
Q12, Q18: Q; 3D
Q16, Q17, Q19: M2P; 3D
Q20, Q28, Q31: W6; 3D
Q25: 8LB; SOT-416
Q26: G16; SOT-23-PC110
Q29: H15; SOT-23-PC110
Q36: 3P4J; TO-252-2
R1, R50, R66, R82, R108: DNP; R_0603_1608Metric
R2, R10, R21, R31, R70, R74, R83, R87, R90: 470k; R_0603_1608Metric
R3, R36, R65, R71, R72, R75, R76, R93: 1k; R_0603_1608Metric
R4, R11, R13, R17, R19, R20, R30, R33, R35, R44, R52, R61, R63, R64, R85, R86, R103, R114, R117: 10k; R_0603_1608Metric
R5, R15, R22, R54, R57, R59, R77, R80, R84, R92, R105: 100k; R_0603_1608Metric
R6, R38: 470; R_0603_1608Metric
R7, R8: 0.1; R_1210_3225Metric
R9, R18, R112, R113: 20k; R_0603_1608Metric
R12: 2.2k; R_0603_1608Metric
R14: 12k; R_0603_1608Metric
R16: 130k; R_0603_1608Metric
R23, R25, R32, R34: 0.1; R_1206_3216Metric
R24: 220; R_0603_1608Metric
R26: 103 (RT1); R_1206_3216Metric
R27, R39, R41, R51, R58, R60, R106: 4.7k; R_0603_1608Metric
R28: 0; R_0603_1608Metric
R29: 103 (RT2); R_1206_3216Metric
R37: 120; R_0603_1608Metric
R40: 0.22; R_1206_3216Metric
R42, R47, R67, R68, R73, R79, R94: 47k; R_0603_1608Metric
R43, R56: 300; R_0603_1608Metric
R45, R62, R69, R81, R101, R109: 200k; R_0603_1608Metric
R46, R55, R88, R89: 1M; R_0603_1608Metric
R48, R104, R118: 100; R_0603_1608Metric
R49, R53, R78, R102: 300k; R_0603_1608Metric
R91, R95, R97: DNP; R_1206_3216Metric
R96: 1.8k; R_0603_1608Metric
R98, R99: 0; R_1206_3216Metric
R100, R110: 7.5k; R_0603_1608Metric
R107: 2k; R_0603_1608Metric
R111: 33; R_0603_1608Metric
R115: 11K; R_0603_1608Metric
R116: 15k; R_0603_1608Metric
SW1: PSU-SW1
U1: D9D; SOT-23-5
U2: TA; SOT-23-5
U3: 6.5 5F; SOT-23-6_Handsoldering
U4: MAX786CAI; TSSOP-28_6.1x9.7mm_P0.65mm
U5: K2337; SOP-8_3.9x4.9mm_P1.27mm
U6: 7064; TSSOP-14_4.4x5mm_P0.65mm
U7: 5W01; SSOP-8-PSU
U8, U9: 2556; SOP-8_3.9x4.9mm_P1.27mm
U10: 9742; SSOP-16_4.4x5.2mm_P0.65mm
U11: 7W14; SSOP-8-PSU
U12, U13: J421; SOP-8_3.9x4.9mm_P1.27mm

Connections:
BATT_POS: R7.2, R8.2, R49.1, R52.2, R63.2
C1_1: C2.1, R4.1
C1_2: C2.2, R1.1, U10.12
C6_1: C4.1, R24.2
C6_2: C4.2, R12.2, U11.2
C8_1: C7.1, R9.2, R14.2, U10.6
C14_2: C12.2, D3.2, Q9.3, Q11.3
C31_1: C33.1, Q27.3, R86.2
C32_1: C33.2, C34.1, Q27.1, R80.1
C33_1: C31.1, Q26.1, R36.1
C35_2: C36.2, Q29.3, R83.2, R86.1, U12.4
C36_1: C35.1, R61.1, R85.2, U3.2, U3.5
C36_2: C35.2, Q30.3, R85.1
D1_2: D1.2, Q5.1
D2_3_PC110: J3.26, Q23.3
D18_2_3_PC110: J1.1, J3.40
D28_1_PC110: C6.2, C11.1, C57.1, J3.12, Q10.4, R16.2
F3_1: C15.1, F3.1, L3.1
F65_ENAVEE_PC110: J3.35, R15.1
GND: C1.1, C3.1, C8.2, C9.1, C11.2, C12.1, C13.2, C14.2, C15.2, C16.2, C17.1, C23.1, C24.1, C28.1, C30.1, C31.2, C34.2, C37.1, C38.2, C39.2, C40.1, C41.1, C42.2, C44.2, C45.1, C46.2, C47.1, C48.2, C49.2, C50.1, C51.1, C54.2, C55.1, C56.1, C57.2, C58.1, C59.2, C60.1, C61.2, C62.1, C64.2, C65.2, C67.1, D3.1, D6.2, J1.3, J3.5, J3.7, J3.9, J3.24, J3.25, J3.29, J3.32, J3.37, Q1.1, Q4.2, Q5.2, Q8.2, Q9.2, Q10.2, Q12.1, Q12.3, Q13.2, Q18.1, Q18.3, Q19.2, Q21.2, Q22.2, Q23.2, Q25.2, Q26.2, Q27.2, Q33.2, Q35.2, Q36.1, Q37.2, R7.1, R8.1, R9.1, R18.2, R27.1, R33.2, R35.2, R39.2, R44.1, R45.1, R53.1, R58.1, R60.2, R64.1, R69.2, R72.1, R77.2, R88.1, R91.1, R94.2, R95.2, R96.2, R98.2, R100.2, R105.2, R106.2, R108.1, R110.1, R113.2, R114.2, R115.2, R116.1, U1.3, U2.2, U3.3, U4.4, U4.5, U4.9, U4.11, U4.20, U5.1, U6.11, U7.4, U8.1, U8.2, U8.3, U10.8, U11.4
J1_4: C24.2, F2.1, J1.4
J5_6_PC110: D1.1, J3.6, Q32.1
J5_33_PC110: C39.1, J3.33, R92.1, R93.2
JRC_IN1+: C43.1, R102.1, R105.1, U6.3
JRC_IN1-: C20.2, R49.2, R57.2, U6.2
JRC_IN2+: R77.1, R78.1, U6.5
JRC_IN2-: R53.2, R54.2, R66.2, U6.6
JRC_IN3+: R44.2, R45.2, U6.10
JRC_IN3-: C25.2, Q19.3, R62.2, R63.1, U6.9
JRC_IN4+: Q19.1, R52.1, R69.1, U6.12
JRC_IN4-: C52.2, R64.2, R101.2, U6.13
JRC_VDD: C44.1, C49.1, Q3.3, R3.1, U6.4, U7.8
L1_2: D6.1, L1.2, U13.5, U13.6, U13.7, U13.8
L2_2: L3.2, Q10.3, Q10.5
M38_P20_PC110: J3.19, Q28.1, Q37.1
M38_P21_PC110: J3.39, Q28.3
M38_P52_PC110: J3.18, R2.1
M38_P53_PC110: J3.38, Q31.1
M38_P60_PC110: C25.1, J3.1, R62.1, U6.8
M38_P61_PC110: C52.1, J3.2, R42.1, R101.1, U6.14
M38_P63_PC110: C20.1, J3.21, R57.1, R67.2, U6.1
M38_P64_PC110: J3.27, R54.1, R66.1, U6.7
M38_VREF_PC110: C1.2, J3.30, Q1.3, Q14.2, R6.1
MAX_BST3: C19.2, Q17.3, U4.25
MAX_BST5: C18.2, Q17.1, U4.18
MAX_CS3: C26.2, R56.2, R108.2, R110.2, U4.1
MAX_CS5: L5.1, R23.2, R25.2, R34.2, U4.15
MAX_DH3: U4.27, U5.4
MAX_DH5: U4.16, U9.4
MAX_DL3: U4.24, U5.2
MAX_DL5: U4.19, U8.4
MAX_FB3: C22.2, R43.2, R100.1, U4.28
MAX_LX3: C19.1, L2.1, Q18.2, U4.26, U5.3, U5.7, U5.8
MAX_LX5: C18.1, L5.2, Q12.2, U4.17, U8.5, U8.6, U8.7, U8.8, U9.1, U9.2, U9.3
MAX_REF: C38.1, U4.10
MAX_SS3: C40.2, U4.2
MAX_SS5: C48.1, U4.14
MAX_VL: C55.2, Q17.2, R48.1, U4.22
MAX_VL+: C47.2, R104.1, U4.23
ON3_ON5_VH_SHDN#: C23.2, R48.2, U4.3, U4.6, U4.12, U4.13
PNET1_PC110: C22.1, C54.1, J3.8, J3.28, R32.1, R40.1, R43.1
PNET4_PC110: C36.1, C53.2, D2.1, D7.1, D8.1, J3.3, J3.4, J3.23, Q11.2, Q29.2, R22.2, R46.2, R83.1, U12.1, U12.2, U12.3, U13.1, U13.2, U13.3
PNET5_PC110: C28.2, C56.2, C61.1, C62.2, J3.10, J3.11, J3.31, Q2.3, Q15.3, R17.2, R20.2, R23.1, R25.1, R26.1, R29.2, R34.1, R84.2, R118.1, U2.5, U4.21, U11.8
PWR_IN_10v5: C30.2, D4.1, D7.2, D8.2, Q24.2, Q32.3, Q36.2, R75.2, R95.1, R99.2
PWR_IN_NEG: C29.1, J2.2, J2.3, R97.2, R98.1
PWR_IN_POS: F1.2, J2.1
PWR_IN_POS_Fuse: C29.2, F1.1, R97.1, R99.1
Q3_1: Q4.1, R2.2
Q3_3: Q4.3, Q5.3, Q22.3, R5.2
Q4_1: Q3.1, R5.1
Q6_2: C5.1, C7.2, C58.2, C59.1, Q6.2, Q7.2, R11.2, R13.1, R14.1, R19.2, U10.16
Q7_1: C8.1, Q6.1, R10.1
Q7_3: C6.1, Q6.3, R16.1, R116.2, U10.14
Q8_1: Q8.1, R12.1, R24.1
Q8_5: L4.1, Q8.3, Q8.5
Q9_1: Q10.1, R37.1, R38.1
Q13_3: Q13.3, R30.1
Q14_2: D5.1, Q20.2, R82.1
Q20_1: C27.2, Q16.1, R55.2, U7.1
Q22_1: Q24.1, R74.1
Q27_3: Q26.3, Q29.1, R46.1
Q29_2: Q31.2, R70.1, R87.2
Q30_2: Q28.2, Q31.3, R47.2, R59.2
Q33_2: C37.2, F5.2, L1.1, Q34.2, R89.2, R91.2
Q33_3: C43.2, Q34.3, R102.2
Q36_3: Q37.3, R107.2
Q43_2_PC110: C17.2, C32.2, C67.2, J3.13, Q8.4, R81.2
Q49_1_PC110: D5.2, J3.22, R82.2
R2_2: Q2.1, R3.2
R6_2: Q2.2, R6.2
R11_1: R20.1, U10.7, U11.6
R17_2: C9.2, Q7.1, R15.2
R19_1: R17.1, U10.10, U11.1, U11.3
R20_1: C5.2, R18.1, R19.1, U10.11
R21_1: Q13.1, R31.1
R21_2: R28.1, R31.2, U1.1
R24_2: C10.1, R38.2, U11.5, U11.7
R26_2: R21.2, R28.2
R31_1: C16.1, R21.1, R22.1, U1.2
R32_1: R1.2, R4.2, R11.1, R35.1, U10.13
R35_2: D2.2, Q11.1, R30.2
R36_1: C63.2, R13.2, R33.1, R117.1, U10.4
R36_2: C10.2, R37.2
R38_1: Q20.3, R27.2, R29.1
R48_2: Q20.1, R26.2, R58.2
R50_1: Q30.2, R50.1, U2.4
R50_2: R50.2, R65.2, U2.3
R51_1: Q16.2, R51.1, R60.1, U2.1
R51_2: Q15.2, R51.2
R54_2: R39.1, R41.2
R56_1: C26.1, L2.2, R32.2, R40.2, R56.1
R59_1: Q21.1, R59.1
R61_1: Q15.1, R47.1
R68_1: Q14.1, R68.1
R68_2: Q21.3, R68.2
R70_2: Q25.3, R74.2
R72_1: D4.2, R76.1
R72_2: C42.1, Q36.3, R76.2, R96.1
R73_2: Q25.1, R70.2
R73_2_PC110: J3.15, R79.2
R76_1: R71.1, R75.1
R77_1: Q23.1, R71.2, R72.2, R73.1
R77_2: Q22.1, Q35.3, R73.2
R78_2: Q24.3, R78.2
R80_1: C32.1, Q7.3, R79.1, R81.1, R115.1, U10.3
R82_1: Q30.1, R84.1
R88_1: Q33.1, R87.1
R89_1: R88.2, R89.1
R91_1: Q33.3, R90.1
R91_2: Q34.1, R90.2
R92_2: Q35.1, R92.2
R104_1: R106.1, R107.1, R112.1, U7.5
R106_1: C51.2, R111.1
R106_2: C53.1, R111.2
R111_2: Q14.3, R103.2, R109.2, R112.2
R111_!: C46.1, R103.1, R109.1, R113.1, U7.3
R115_2: C66.2, R117.2
R284_2_PC110: C13.1, C14.1, C45.2, C50.2, F2.2, F3.2, F4.2, J3.14, R104.2, U5.5, U5.6, U9.5, U9.6, U9.7, U9.8, U12.5, U12.6, U12.7, U12.8
R284_2_PC110_Fuse: C65.1, F4.1, L4.2
R412_1_PC110: J1.2, J3.20
SW1_2: R93.1, R94.1, SW1.2
U3_1: U3.1, U3.4, U13.4
U3_6: Q32.2, R41.1, R61.2, U3.6
U6_2: C27.1, R55.1, R67.1, U7.2
U6_6: C21.1, R42.2, U7.6
U6_7: C21.2, Q16.3, U7.7
U11_1: C60.2, R65.1, U10.1
U11_2: R114.1, U10.2
U11_5: C63.1, C66.1, U10.5
U11_9: C64.1, R118.2, U10.9
U11_15: C41.2, U10.15
U21_131_PC110: J3.34, R10.2
U54_1D_PC110: J3.17, R36.2
U54_1Q_PC110: J3.36, R80.2
U54_VCC_PC110: C3.2, J3.16, Q3.2, Q9.1, SW1.1

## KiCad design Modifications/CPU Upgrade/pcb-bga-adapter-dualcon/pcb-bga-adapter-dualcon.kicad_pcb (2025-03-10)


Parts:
J1: 54722-0604; 547220604; Mouser Part Number 538-54722-0604
J2: 55560-0607; 555600607; Mouser Part Number 538-55560-0607
U1: BGA-256-MIRRORED

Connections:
A2: J1.54, U1.A3 (A2)
A3: J1.48, U1.D2 (A3)
A4: J1.46, U1.D1 (A4)
A5: J1.44, U1.E2 (A5)
A6: J1.42, U1.F2 (A6)
A7: J1.40, U1.F1 (A7)
A8: J1.38, U1.G2 (A8)
A9: J1.36, U1.G1 (A9)
A10: J1.32, U1.H2 (A10)
A11: J1.34, U1.H1 (A11)
A12: J1.30, U1.J1 (A12)
A13: J1.28, U1.K2 (A13)
A14: J1.26, U1.K1 (A14)
A15: J1.24, U1.L2 (A15)
A16: J1.22, U1.L1 (A16)
A17: J1.20, U1.M2 (A17)
A18: J1.18, U1.N1 (A18)
A19: J1.16, U1.P2 (A19)
A20: J1.14, U1.P1 (A20)
A20M#: J2.58, U1.B13 (A20M#)
A21: J1.8, U1.T3 (A21)
A22: J1.10, U1.R3 (A22)
A23: J1.12, U1.P3 (A23)
A24: J1.2, U1.T4 (A24)
A25: J1.4, U1.R4 (A25)
A26: J1.6, U1.P4 (A26)
A27: J1.27, U1.T5 (A27)
A28: J1.25, U1.R5 (A28)
A29: J1.23, U1.P5 (A29)
A30: J1.21, U1.T6 (A30)
A31: J1.1, U1.R6 (A31)
ADS#: J1.52, U1.B3 (ADS#)
AHOLD: J1.59, U1.A8 (AHOLD)
BE0#: J1.33, U1.B10 (BE0#)
BE1#: J1.29, U1.C10 (BE1#)
BE2#: J2.48, U1.A11 (BE2#)
BE3#: J2.50, U1.B11 (BE3#)
BLAST#: J1.50, U1.C3 (BLAST#)
BRDY#: J1.58, U1.B5 (BRDY#)
BS16#: J1.60, U1.A6 (BS16#)
CLK: J1.35, U1.A9 (CLK)
D0: J1.17, U1.R7 (D0)
D1: J1.3, U1.P7 (D1)
D2: J1.5, U1.T8 (D2)
D3: J1.11, U1.R8 (D3)
D4: J1.7, U1.P8 (D4)
D5: J1.13, U1.T9 (D5)
D6: J1.15, U1.R9 (D6)
D7: J1.9, U1.P9 (D7)
D8: J2.4, U1.R10 (D8)
D9: J2.14, U1.P10 (D9)
D10: J2.2, U1.R11 (D10)
D11: J2.8, U1.P11 (D11)
D12: J2.10, U1.T12 (D12)
D13: J2.16, U1.R12 (D13)
D14: J2.12, U1.P12 (D14)
D15: J2.18, U1.T13 (D15)
D16: J2.1, U1.P13 (D16)
D17: J2.5, U1.R16 (D17)
D18: J2.9, U1.P16 (D18)
D19: J2.7, U1.P15 (D19)
D20: J2.13, U1.N16 (D20)
D21: J2.11, U1.N15 (D21)
D22: J2.17, U1.M16 (D22)
D23: J2.15, U1.M15 (D23)
D24: J2.19, U1.L15 (D24)
D25: J2.25, U1.K16 (D25)
D26: J2.23, U1.K15 (D26)
D27: J2.29, U1.J16 (D27)
D28: J2.27, U1.J15 (D28)
D29: J2.33, U1.H16 (D29)
D30: J2.31, U1.H15 (D30)
D31: J2.37, U1.G16 (D31)
DC#: J2.60, U1.A12 (DC#)
DP0: J1.19, U1.T7 (DP0)
DP1: J2.6, U1.T10 (DP1)
DP2: J2.3, U1.R13 (DP2)
DP3: J2.21, U1.L16 (DP3)
EADS#: J2.54, U1.A13 (EADS#)
FLUSH#: J2.49, U1.C16 (FLUSH#)
GND: J2.20, J2.22, J2.24, J2.26, J2.28, J2.30, J2.32, J2.34, J2.36, J2.38, J2.40, J2.42, J2.44, J2.46, U1.F4 (GND), U1.F5 (GND), U1.F6 (GND), U1.F7 (GND), U1.F8 (GND), U1.F9 (GND), U1.F10 (GND), U1.F11 (GND), U1.F12 (GND), U1.F13 (GND), U1.G4 (GND), U1.G5 (GND), U1.G6 (GND), U1.G7 (GND), U1.G8 (GND), U1.G9 (GND), U1.G10 (GND), U1.G11 (GND), U1.G12 (GND), U1.G13 (GND), U1.H4 (GND), U1.H5 (GND), U1.H6 (GND), U1.H7 (GND), U1.H8 (GND), U1.H9 (GND), U1.H10 (GND), U1.H11 (GND), U1.H12 (GND), U1.H13 (GND), U1.J4 (GND), U1.J5 (GND), U1.J6 (GND), U1.J7 (GND), U1.J8 (GND), U1.J9 (GND), U1.J10 (GND), U1.J11 (GND), U1.J12 (GND), U1.J13 (GND), U1.K4 (GND), U1.K5 (GND), U1.K6 (GND), U1.K7 (GND), U1.K8 (GND), U1.K9 (GND), U1.K10 (GND), U1.K11 (GND), U1.K12 (GND), U1.K13 (GND), U1.L4 (GND), U1.L5 (GND), U1.L6 (GND), U1.L7 (GND), U1.L8 (GND), U1.L9 (GND), U1.L10 (GND), U1.L11 (GND), U1.L12 (GND), U1.L13 (GND)
HLDA: J1.37, U1.B9 (HLDA)
HOLD: J1.39, U1.C7 (HOLD)
INTR: J2.45, U1.D15 (INTR)
KEN#: J1.56, U1.B7 (KEN#)
MIO#: J2.56, U1.C11 (MIO#)
NMI: J2.47, U1.D16 (NMI)
RDY#: J1.57, U1.A7 (RDY#)
RESET: J2.52, U1.C13 (RESET)
SMI#: J2.39, U1.F15 (SMI#)
SMIACT#: J2.43, U1.E16 (SMIACT#)
SRESET: J2.41, U1.E15 (SRESET)
STPCLK#: J2.35, U1.G15 (STPCLK#)
VCC: J1.41, J1.43, J1.45, J1.47, J1.49, J1.51, J1.53, J1.55, J2.51, J2.53, J2.55, J2.57, J2.59, U1.D3 (VCC), U1.D4 (VCC), U1.D5 (VCC), U1.D6 (VCC), U1.D7 (VCC), U1.D8 (VCC), U1.D9 (VCC), U1.D10 (VCC), U1.D11 (VCC), U1.D12 (VCC), U1.D13 (VCC), U1.D14 (VCC), U1.E3 (VCC), U1.E4 (VCC), U1.E5 (VCC), U1.E6 (VCC), U1.E7 (VCC), U1.E8 (VCC), U1.E9 (VCC), U1.E10 (VCC), U1.E11 (VCC), U1.E12 (VCC), U1.E13 (VCC), U1.E14 (VCC), U1.F3 (VCC), U1.F14 (VCC), U1.G3 (VCC), U1.G14 (VCC), U1.H3 (VCC), U1.H14 (VCC), U1.J3 (VCC), U1.J14 (VCC), U1.K3 (VCC), U1.K14 (VCC), U1.L3 (VCC), U1.L14 (VCC), U1.M3 (VCC), U1.M4 (VCC), U1.M5 (VCC), U1.M6 (VCC), U1.M7 (VCC), U1.M8 (VCC), U1.M9 (VCC), U1.M10 (VCC), U1.M11 (VCC), U1.M12 (VCC), U1.M13 (VCC), U1.M14 (VCC), U1.N3 (VCC), U1.N4 (VCC), U1.N5 (VCC), U1.N6 (VCC), U1.N7 (VCC), U1.N8 (VCC), U1.N9 (VCC), U1.N10 (VCC), U1.N11 (VCC), U1.N12 (VCC), U1.N13 (VCC), U1.N14 (VCC)
WR#: J1.31, U1.C9 (WR#)


Board: 2 copper layers, 23.0 x 23.0 mm, 3 parts (1 on the bottom side), 95 nets.

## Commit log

2025-01-22 Add files via upload
    BC1 and FC1 are traced
    [PC110.kicad_pcb, PC110.kicad_sch]
2025-01-29 progress on BC2
    [PC110.kicad_sch]
2025-02-06 fix pin 14 of OPL chip
2025-02-06 update and fix issues with footprints
2025-02-08 resolve footprint issues
2025-02-09 correct BGA footprint
2025-02-09 finish PCMCIA driver netlist
2025-02-11 improve traces
2025-02-12 complete ram connector netlist
2025-02-14 annotate top layer Capacitors, Resistors and Inductors
2025-02-14 annotate all resistor, capacitor, inductor & Fuse
2025-02-15 reference schematic
2025-02-17 improve traces and add 3D model for XTALs
2025-02-17 minor trace improvements and added 3D model 4 BGA
2025-02-17 add initial schematic from the sandy river project
    The entire schematic needs to be redesigned/reassigned
    [Audio.kicad_sch, Buffers.kicad_sch, Chipset.kicad_sch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]
2025-02-18 minor improvements on traces
2025-02-18 Major improvement in traces clearance
2025-02-18 major traces and via improvement
2025-02-18 major update and fix traces and vias
2025-02-19 Major improvement, minimum trace to 3mil
2025-02-19 minor traces issues resolved
2025-02-20 minor improvements in traces
2025-02-20 minor changes to traces
2025-02-21 update traces
2025-02-22 complete CPU ball map based on xray, die map
2025-02-23 minor improvement in traces
2025-02-26 improved netlist and traces
2025-03-09 Resistor value for FC2 completed
2025-03-09 Resistor values BC2 in progress
2025-03-09 CPU Upgrade
    [51338-1074.stp, pcb-bga-adapter.kicad_pcb, pcb-bga-adapter.kicad_sch]
2025-03-09 Initial commit of cpu adapter
    [pcb-bga-adapter.kicad_pcb, pcb-bga-adapter.kicad_sch]
2025-03-09 measure value of all resistors
2025-03-09 complete missing resistor values
2025-03-09 fix issue with one of the capacitor values
2025-03-09 complete FC2 capacitor measurement
2025-03-09 cleanup kicad locks and backups
2025-03-10 silkscreen update
    [pcb-bga-adapter.kicad_pcb]
2025-03-10 complete all capacitor and resistor values
2025-03-10 dualcon
    switch to dual connectors for more power pins
    [51338-1074.stp, pcb-bga-adapter-dualcon.kicad_pcb, pcb-bga-adapter-dualcon.kicad_sch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]
2025-03-10 cpu adapter board updates
    [51338-1074.stp, bgacpu-dualcon.kicad_pcb, bgacpu-dualcon.kicad_sch]
2025-03-10 Updated CPU Board
    [pcb-bga-adapter-dualcon.kicad_pcb, pcb-bga-adapter-dualcon.kicad_sch]
2025-03-18 update polygons
    [PSU.kicad_pcb]
2025-03-19 netlist completed
    [DockingStation.kicad_pcb]
2025-03-22 Routing finished
    [Modem.kicad_pcb]
2025-03-23 Disassembly
    Attempt to disassemble power sense firmware to understand and troubleshoot power up issues.
2025-06-19 Add part numbers to some SMT parts
    [ASIC.kicad_sch, Audio.kicad_sch, Chipset.kicad_sch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]
2025-06-20 add RAS4
    RAS4 is used to add up to the internal RAM (to make it 8MB)
    [Chipset.kicad_sch]
2025-06-26 fix local and global labels
    [ASIC.kicad_sch, Audio.kicad_sch, Chipset.kicad_sch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]
2025-10-13 fixed connection with 3V3 buck output and PNET1
    [PSU.kicad_sch]
2025-10-13 Added current state of U6 Disassembly, readme update, better U6 Datasheet
2025-10-13 confirmed U6 Crystal freq
    [Power.kicad_sch]
2025-10-13 fixed accidental short of ASIC/U6 line to PNET2 ##In schematic only##
    [ASIC.kicad_sch, Power.kicad_sch]
2025-10-13 Made a little PCB that hopefully will reliably read an M38224 with a ROM programmer
    [M38224 ROM Adapter.kicad_pcb, M38224 ROM Adapter.kicad_sch]
2025-10-13 mistyped a patch (wrong ADC version)
2025-10-13 Added files via upload that were accidentally deleted
    Try as I might, my merge cludge broke :( fixing manually. These are the exact files from before the merge.
    [ASIC.kicad_sch, Power.kicad_sch]
2025-10-29 updates to disassembly
    [Breakout ROM Adapter.kicad_pcb, Breakout ROM Adapter.kicad_sch, M38224 ROM Adapter.kicad_pcb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]
